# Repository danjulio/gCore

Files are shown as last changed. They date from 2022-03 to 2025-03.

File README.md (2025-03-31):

## gCore - gadget Core

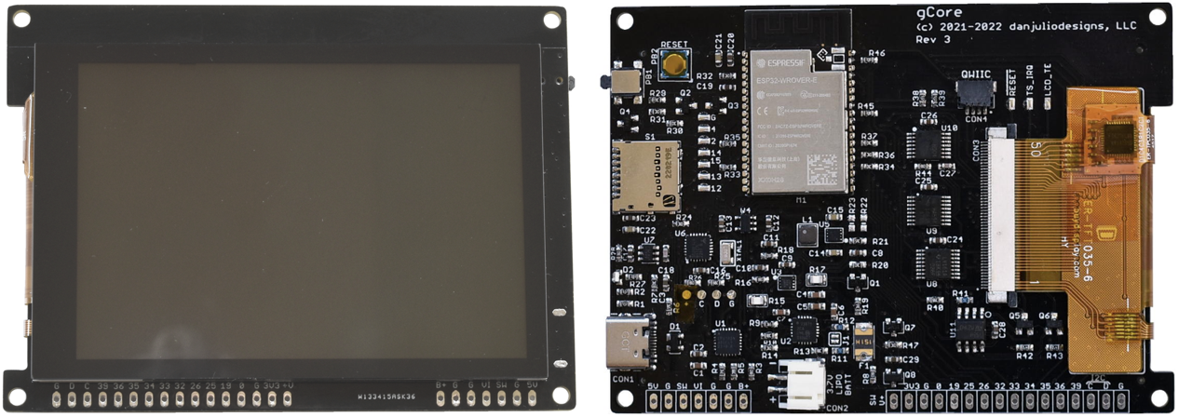
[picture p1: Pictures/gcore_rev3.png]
gCore Top

 
This repository contains documentation and example code for an ESP32-based development board I designed to enable building portable GUI-based gadgets (*).  It provides a rich feature set and high performance operation enabling, I hope, all kinds of cool and useful devices such as remote controls, instrument controllers and game platforms.  Code may be written using the ESP32 Arduino environment, Espressif's IDF or MicroPython.  Both Adafruit-compatible and [LVGL](https://lvgl.io) LCD drivers are available.

gCore can be purchased from [tindie](https://www.tindie.com/products/globoy/gcore-high-end-esp32-graphics-dev-board/).

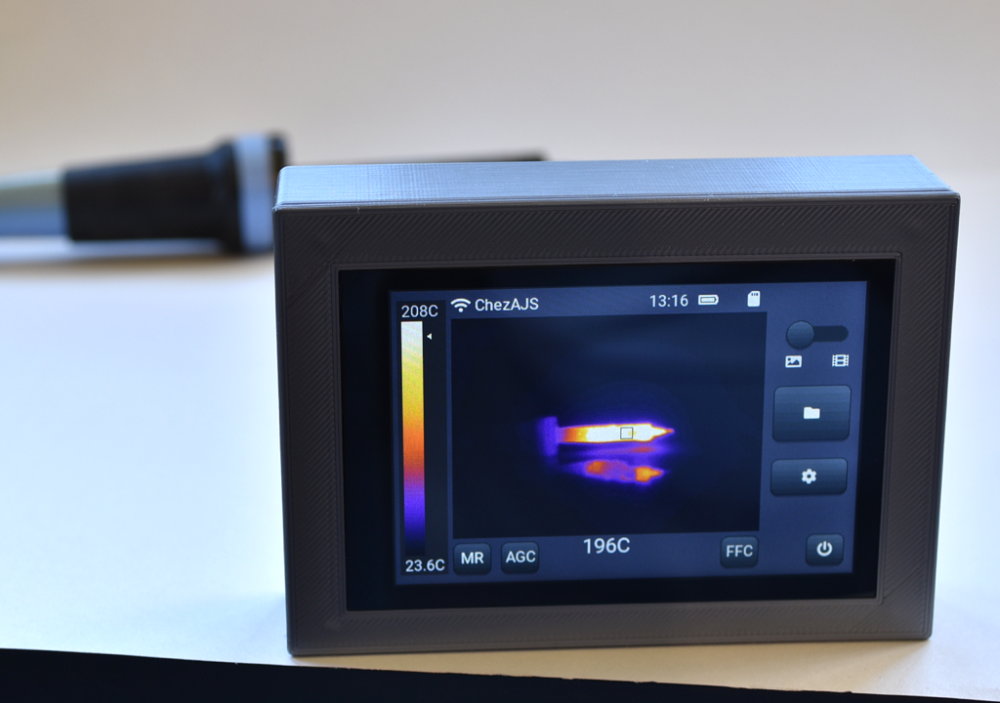
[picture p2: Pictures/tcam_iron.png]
gCore based tCam

(tCam thermal imaging camera)

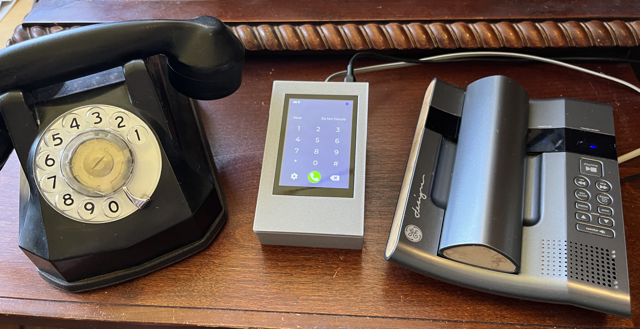
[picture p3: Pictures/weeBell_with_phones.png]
gCore based POTS to bluetooth

(POTS telephone to bluetooth adapter)

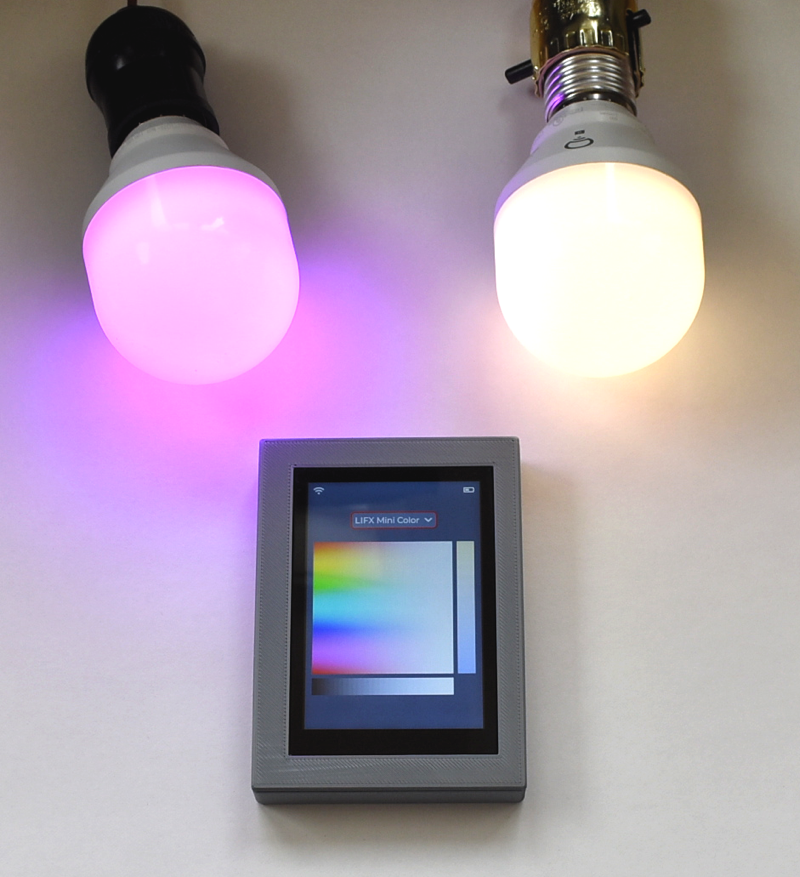
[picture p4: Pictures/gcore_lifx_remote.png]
gCore Controlling LIFX bulbs

(Controlling LIFX LED light bulbs via Wifi)

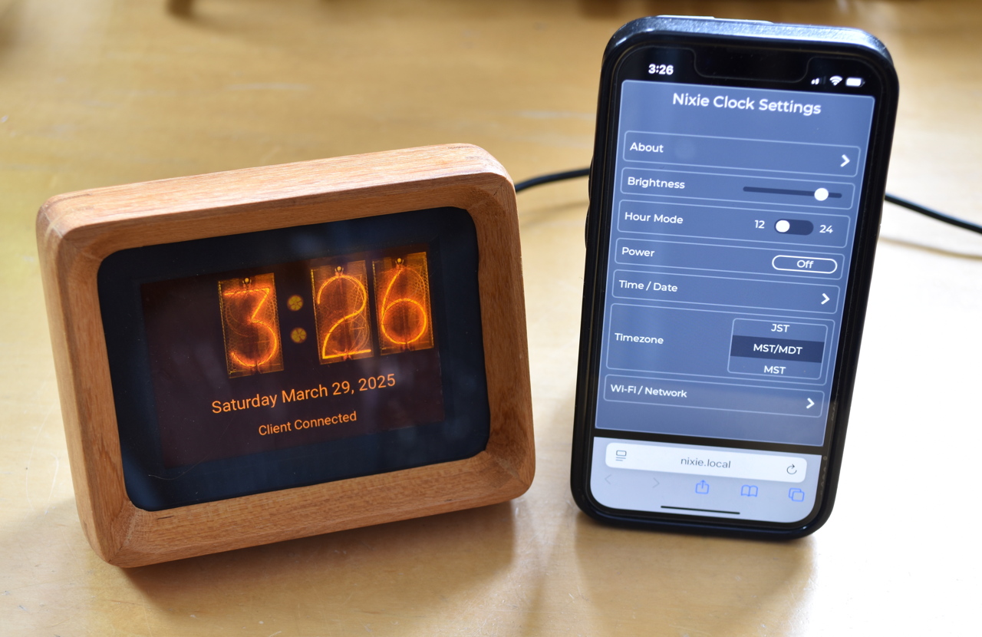
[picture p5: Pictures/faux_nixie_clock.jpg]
gCore Faux Nixie Clock

("Nixie" Desk clock)

### Supporting documentation and code
This repository contains documentation, firmware, an Arduino library with example code, and designs for 3D printed enclosures.

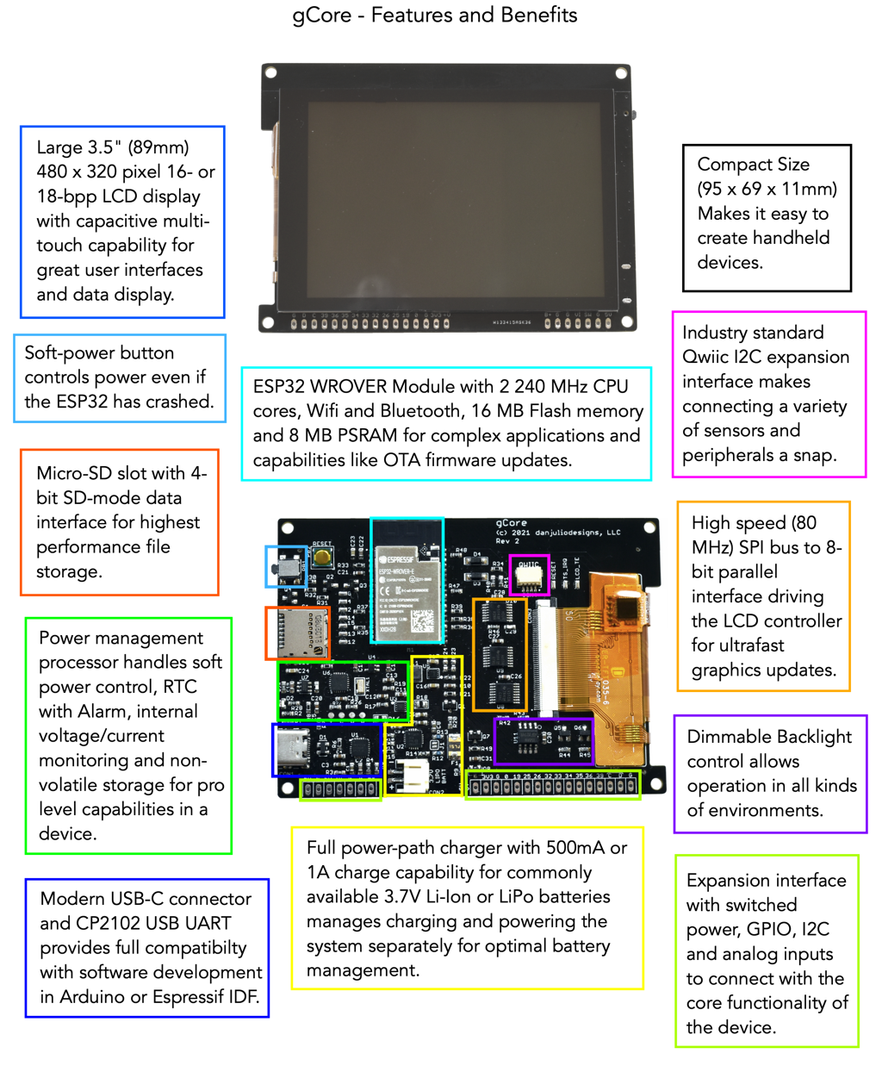
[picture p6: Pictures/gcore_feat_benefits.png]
gCore Features and Benefits


### Support in other Github repositories
Additional demos and ports of other software to gCore are stored in the following additional repositories to reduce the size of this repository.

1. [TFT_eSPI](https://github.com/danjulio/TFT_eSPI) - A fork of Bodmer's LCD driver library ported to gCore to maximize LCD drawing performance for Arduino programs.  Very fast.
2. [tCam](https://github.com/danjulio/tCam) - Assembly instructions and firmware for the tCam thermal imaging camera.
3. [MicroPython](https://github.com/danjulio/lv_binding_micropython) - LVGL binding for MicroPython.
4. [gcore_life](https://github.com/danjulio/gcore_life) - Life running on gCore using LVGL.  Shows how to integrate control for gCore into an ESP32 IDF program.
5. [gcore\_lv\_port_esp32](https://github.com/danjulio/gcore_lv_port_esp32) - The LVGL v7 demo with gCore optimized LCD and touch drivers useful for for ESP32 IDF programs.
6. [gcore_tank](https://github.com/danjulio/gcore_tank) - An easy-to-build remote controlled vehicle with video feed using gCore and the remote control.
7. [gcore\_lv\_music_demo](https://github.com/danjulio/gcore_lvgl_music_player) - The LVGL Music Demo running on LVGL v9.
8. [Galaga](https://github.com/danjulio/gcore_galagino) - A port of Harbaum's Galaga emulator on gCore.
9. [MiniWebRadio](https://github.com/danjulio/ESP32-MiniWebRadio) - A port of schreifbfaul1's internet radio/clock program to gCore.
10. [weeBell](https://github.com/danjulio/weeBell_bluetooth) - A bluetooth to POTS phone adapter running on a gCore [expansion board](https://github.com/danjulio/weeBell_hardware).
11. [Faux Nixie Clock](https://github.com/danjulio/faux_nixie_clock) - Desk clock with web browser control panel.

I wrote a desktop app that encapsulates a compiled version of esptool and can download pre-compiled binaries for most of the demos from my [website](https://danjuliodesigns.com/products/gcore.html) and load them into gCore without needing Arduino or the Espressif IDF.

1. [Linux download](https://danjuliodesigns.com/resources/AppSupport/gcore/gsc_0_2_0_Linux_x86_64.zip) - 64-bit x86 architecture version
2. [Mac OS download](https://danjuliodesigns.com/resources/AppSupport/gcore/gsc_0_2_0_macOS.zip) - 64-bit universal (sadly unsigned so you'll have to authorize it)
3. [Windows download](https://danjuliodesigns.com/resources/AppSupport/gcore/gsc_0_2_0_Windows64.zip) - 64-bit x86 architecture version

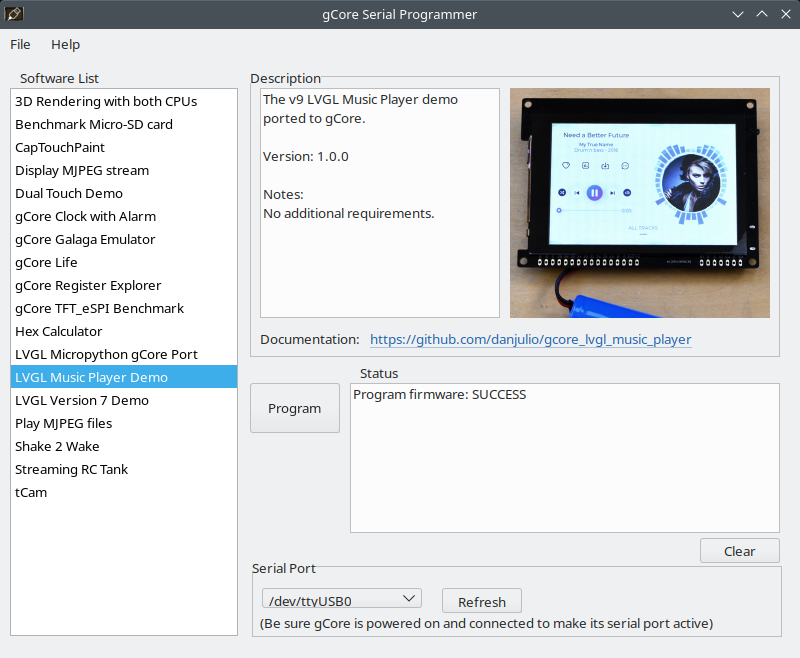
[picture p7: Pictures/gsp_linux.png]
gCore Serial Programmer


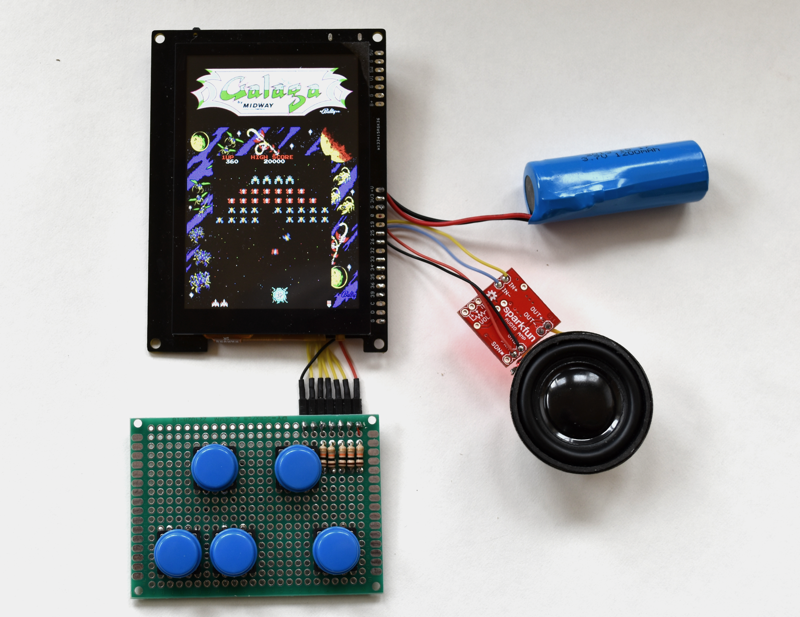
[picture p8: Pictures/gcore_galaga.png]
Galaga on gCore


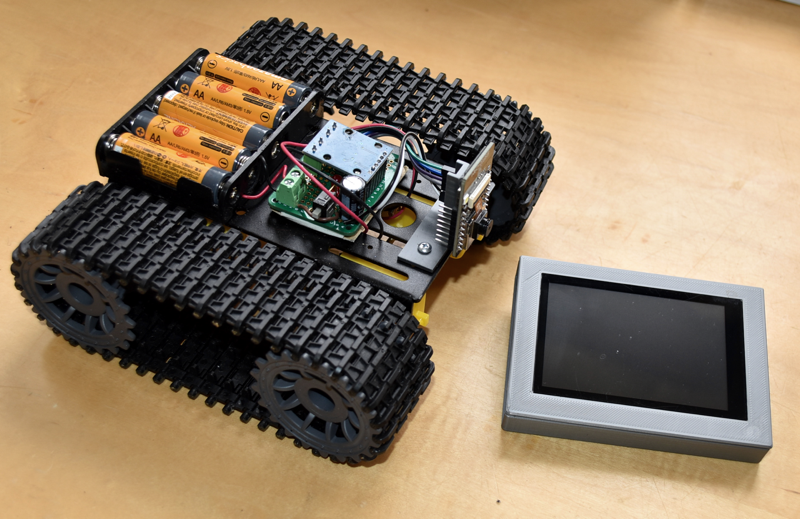
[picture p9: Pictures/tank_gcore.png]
Remote Controlled Tank


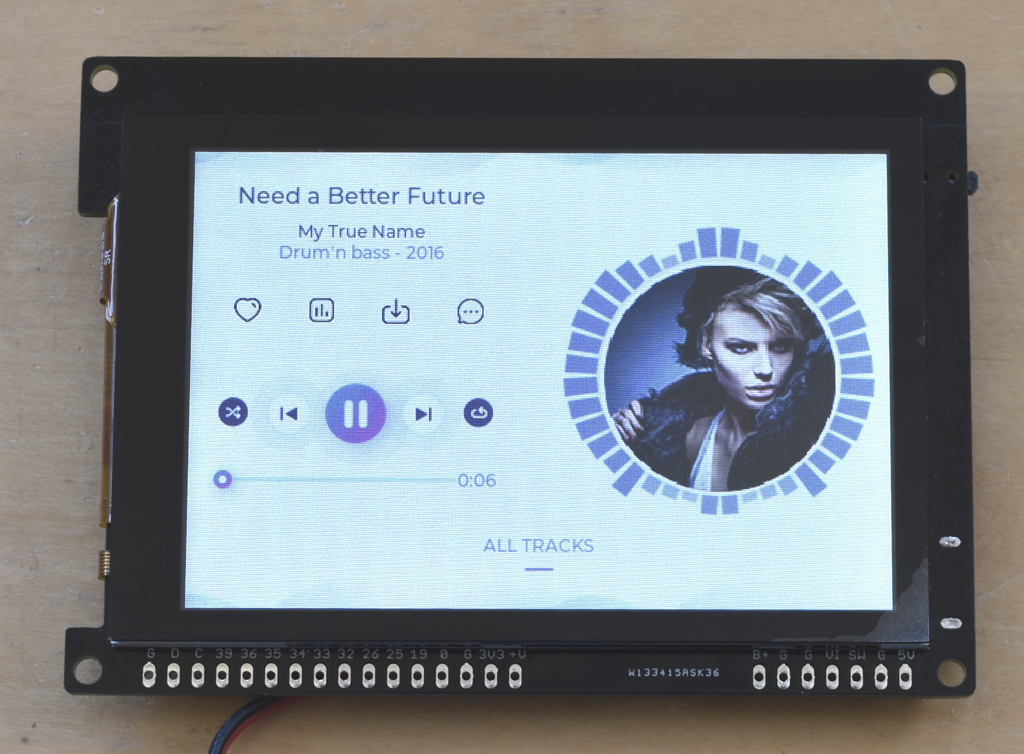
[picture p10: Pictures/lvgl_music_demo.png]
LVGL Music Demo


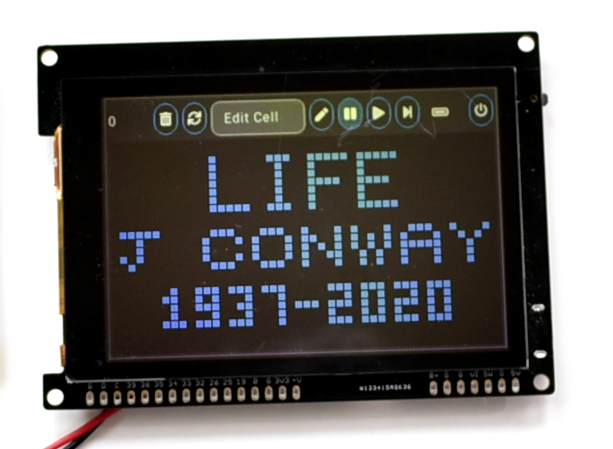
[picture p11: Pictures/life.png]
Life!


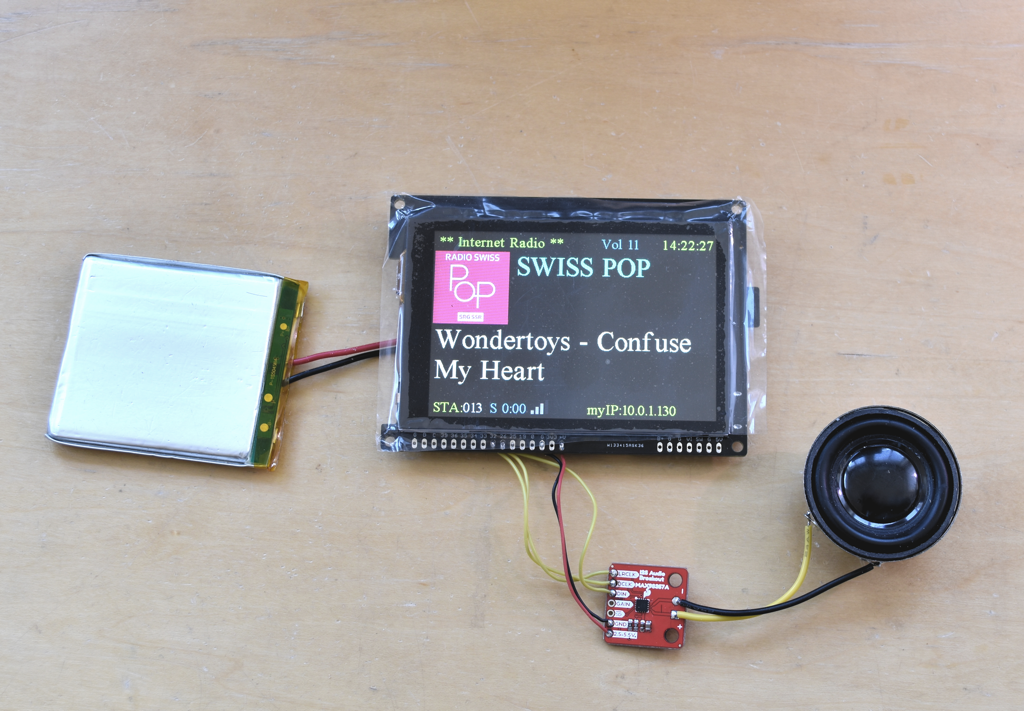
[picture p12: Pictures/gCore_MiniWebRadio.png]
MiniWebRadio


### (*) Historical Note
This is actually my second design.  The original gCore design was based around a "feather" PCB designed to fit under an Adafruit LCD module.  It is documented in the [Original gCore](https://github.com/danjulio/gCore-featherwing) repository.

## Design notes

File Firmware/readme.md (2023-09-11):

## gCore EFM8 Firmware
This directory contains the source code and compiled hex for the EFM8 RTC/PMIC co-processor on gCore.  It was created using Silicon Labs Simplicity Studio v4.

### Sept 2023 - Version 1.2
Version 1.2 fixes two bugs with the Real Time Clock (RTC) in the originally shipped version 1.1 firmware.

1. The once/second RTC interrupt is controlled by a timer.  The timer preset was incorrectly set and led to a time keeping error of -0.0061% (the RTC was slightly slow).
2. The once/second RTC interrupt could be missed on occasion with heavy I2C access to the EFM8 (for example polling the EFM8 several times per second to see if the power button has been pressed).  This could lead to a far more severe time keeping error of up to tens of seconds per day depending on the I2C access frequency.

There are no other known issues with version 1.1 firmware (e.g. there is no problem if you don't use the RTC or can live with the bugs).  Boards are currently shipping with version 1.2 firmware.

### Upgrading Version 1.1 gCore boards
For customers with gCore boards containing version 1.1 firmware and experiencing issues with the RTC there are three ways to get the new firmware loaded on your board.

1. Email me to arrange return and reprogramming.  You will pay the shipping to me and I will pay the return shipping.
2. Install Silicon Labs Simplicity Studio if you have a Silicon Labs USB Debug Adapter and use the programming tool to program the hex from this repository.  The tool can be run from within Simplicity Studio but you need to configure it for an EFM8SB20F32G micro-controller.
3. Update the firmware yourself with the instructions below and a 32-bit Arduino board.

You can tell what firmware you are using by running the ```gcore_reg_explorer``` demo Arduino sketch in the ```Arduino/gCore/examples``` folder in this repository.  You will see a line of text identifying the version on the gCore display.

```
	ID: 0x01  Version: 1.1
```

#### Local Firmware Update
The ```gcore_efm8_upd_1_2``` folder contains an Arduino sketch that contains the new firmware and code capable of programming the gCore EFM8 through a Silicon Labs C2 interface exposed via test points on gCore.  The sketch is designed to run on a 3.3V 32-bit Arduino development board and has been tested on the following boards.

1. PJRC Teensy 3.2 using Teensyduino 1.56
2. PJRC Teensy 4 using Teensyduino 1.56
3. Sparkfun ESP32 Thing Plus using Espressif ESP32 for Arduino version 2.0.9
4. Espressif ESP32-S3-DevKitC-1 using Espressif ESP32 for Arduino version 2.0.9
5. Waveshare RP2040 Zero using Earle Philhower’s Raspberry Pi Pico/RP2040 version 3.4.1

The C2 interface has some timing restrictions and various Arduino implementations have wildly different GPIO performance so unfortunately I cannot guarantee operation on any other board (although different Teensy 3/4, ESP32 and RP2040 boards will probably work).

Three wires connect the Arduino to gCore and programming only takes a few seconds after the sketch is compiled and downloaded to the Arduino board.

You should only attempt this if you understand how to compile Arduino sketches for different boards and can connect wires between the two boards.  Please read through the following instructions before attempting the update.

You will need some connecting wire, ideally three Dupont style wires with male and female ends.

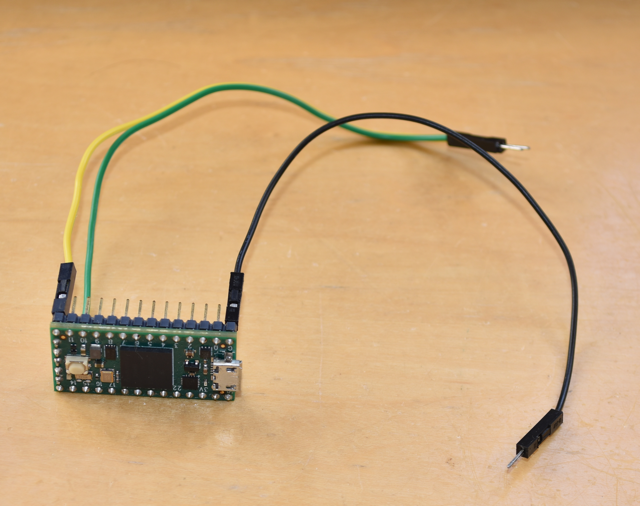
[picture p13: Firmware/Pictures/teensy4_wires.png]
Teensy 4 with wires


You will be connecting to the gCore EFM8 ICSP test points.

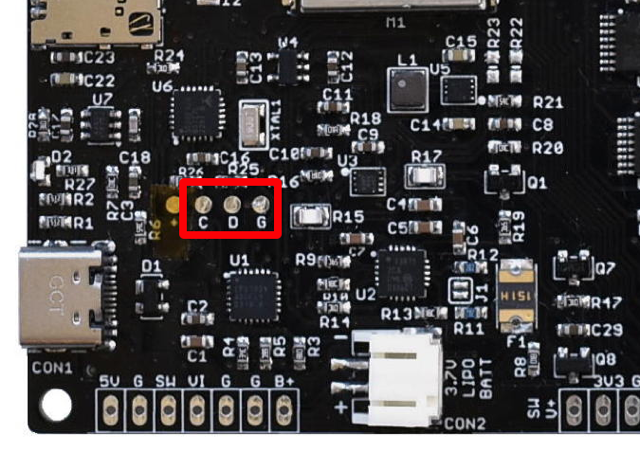
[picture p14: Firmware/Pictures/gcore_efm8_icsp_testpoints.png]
gCore EFM8 ICSP Test Points


#### Compile gcore\_efm8\_upd\_1_2

1. Either update your local copy of this repository or download a zip file of the repository to get the sketch on your computer.
2. Open the Arduino IDE and select your board type.
3. Configure the build environment for your board as discussed below under Board Specific Configuration.
4. Connect your Arduino board and select its serial port.
5. Load the sketch into Arduino. See the note below about selecting GPIO pins on your Arduino.
6. Compile and download the sketch.
7. Open the Arduino Serial Monitor and set it to 115200 baud.  Type the character 'H' in the Serial Monitor and hit send.  You should see the following message displayed in the Serial Monitor.

```
	gCore EFM8 version 1.2 firmware updater sketch
```

##### Board specific configuration

Teensy board have the following setup.  Important to get the right optimization level.

| Board | Setup |
| --- | --- |
| Teensy 3.2 | Optimization: "Faster", CPU Speed: 96 MHz |
| Teensy 4 | Optimization: "Faster", CPU Speed: 600 MHz |
| ESP32 | Flash Frequency: 80 MHz |
| ESP32-S3 | Flash Mode must match your module type (for example use OPI 80 MHz if you have an 8-bit Flash memory) |
| RP2040 | Optimization: "Optimize Even More (-O3)", CPU Speed: 133 MHz |

##### Selecting GPIO pins
By default the sketch uses the following two GPIO pins for the C2 interface.

1. GPIO 12 for the C2 Data (connects to the 'D' pad on gCore)
2. GPIO 14 for the C2 Clock (connects to the 'C' pad on gCore)

You can change these pins if necessary in the sketch under the Pin Definition section in the first tab to match ones available on your board.  Make sure the pins are capable of digital IO.  They should be 3.3V logic levels.

You also need to connect a common ground reference between the Arduino and gCore.

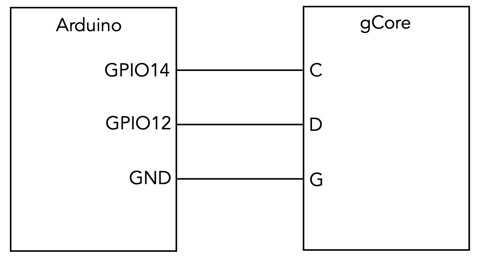
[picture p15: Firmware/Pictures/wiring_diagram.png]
Wiring Diagram


#### Connect the Arduino to gCore
The method described here requires no soldering but does require a steady hand (don't worry I did it a lot while testing this update method).  It also assumes your Arduino board has headers for the Dupont wires or they are soldered to it.

1. gCore should be powered by a connected battery or a USB-C cable but turned off (the EFM8 is always powered when gCore has power).
2. Plug the three Dupont cable female ends onto your Arduino board.  One wire should plug into a Ground (GND) pin and the other two wires into the two GPIO pins implementing the C2 interface.
3. Place the Arduino and gCore next to each other.  Hold the three male ends together in the order 'C' - 'D' - GND and press them onto the gCore EFM8 ICSP pads as shown in the pictures below.  Make sure they are contacting the pads.  They should poke through any oxide layer but you might clean the pads with Isopropyl alcohol on a Q-tip prior to updating.

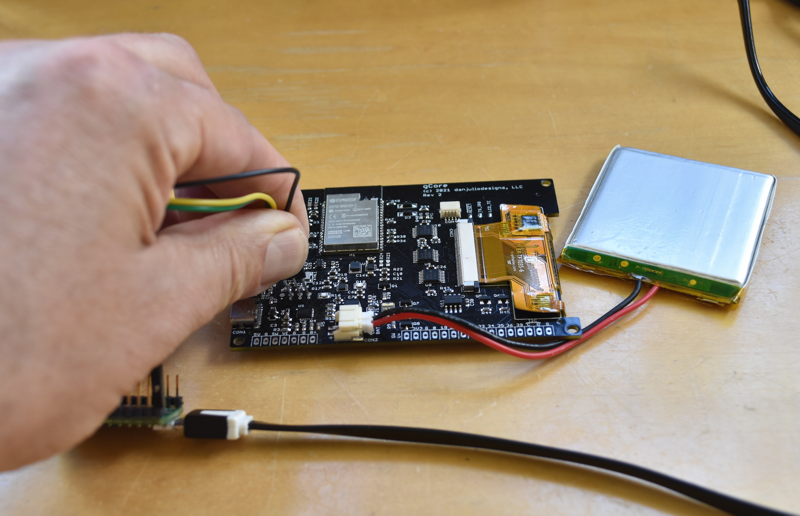
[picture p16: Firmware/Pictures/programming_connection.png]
Programming setup


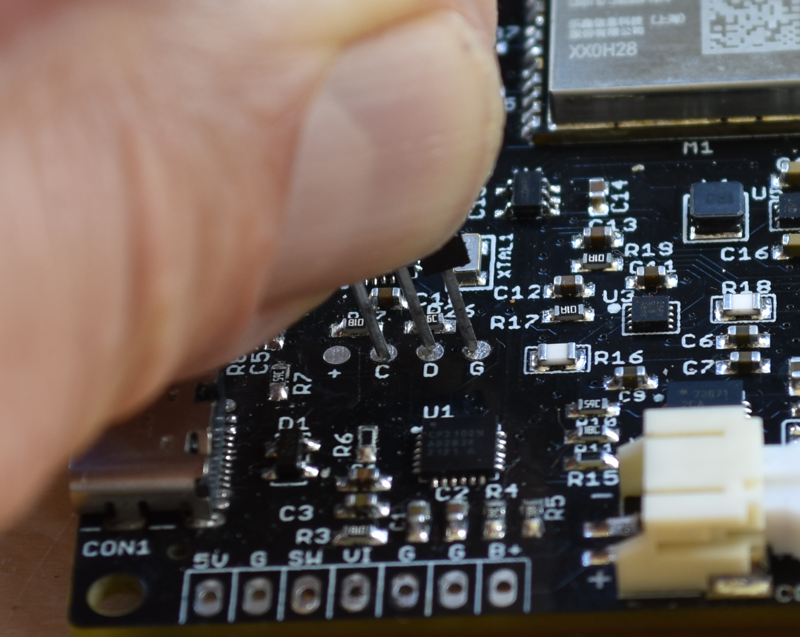
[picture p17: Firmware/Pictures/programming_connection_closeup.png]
Programming setup close-up view


#### Update
While holding the male ends against gCore's test points, type the character 'P' in the Arduino Serial Monitor and hit Send to start programming (it might be easier to type the P in first so you only have to click Send).  You should see the update process start.  It will complete in just a few seconds.

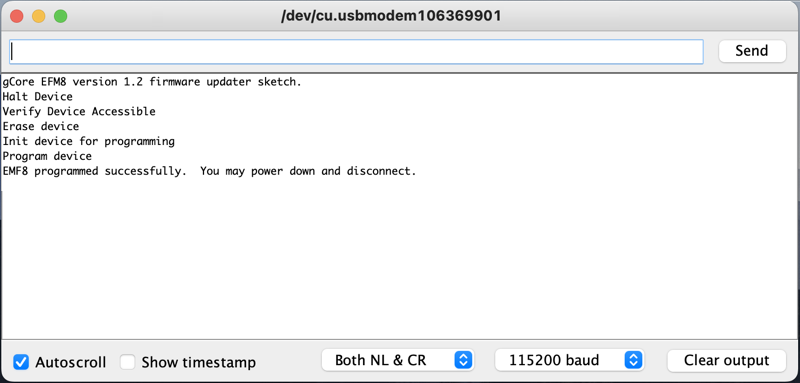
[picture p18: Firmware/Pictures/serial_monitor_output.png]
Serial Monitor Output


You can then disconnect the wires from gCore.  It will be running the new firmware.

#### Errors
The sketch will display an error message if any part of the programming sequence fails.  Most likely this is because of a poor connection or lack of power.  It's also possible if there's some issue with the GPIO performance on your Arduino board.  Although the EFM8 may be erased there should be no way to brick it so don't be afraid to try again.  In the worst case you can arrange re-programming with me.

#### Soldering
It's also possible to solder the Arduino wires to gCore as shown in the following image.  Use a fine wire (I love 30 AWG silicon sleeve wire) and small amounts of solder.  Be sure both the Arduino and gCore are unpowered while soldering and unsoldering.  Take care unsoldering as it is easy to pull the test points off the PCB.

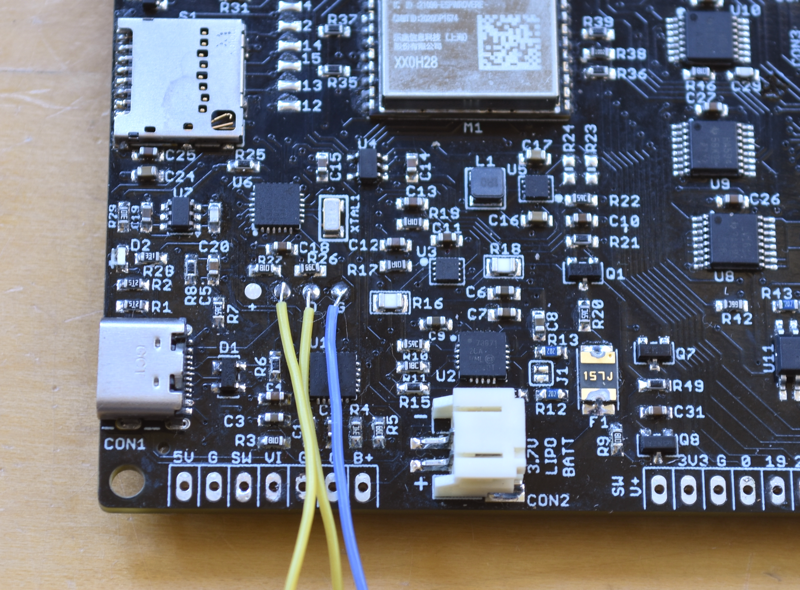
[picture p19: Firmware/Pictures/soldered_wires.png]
Picture of wired assembly


#### Using the Silicon Labs USB Debug Adapter

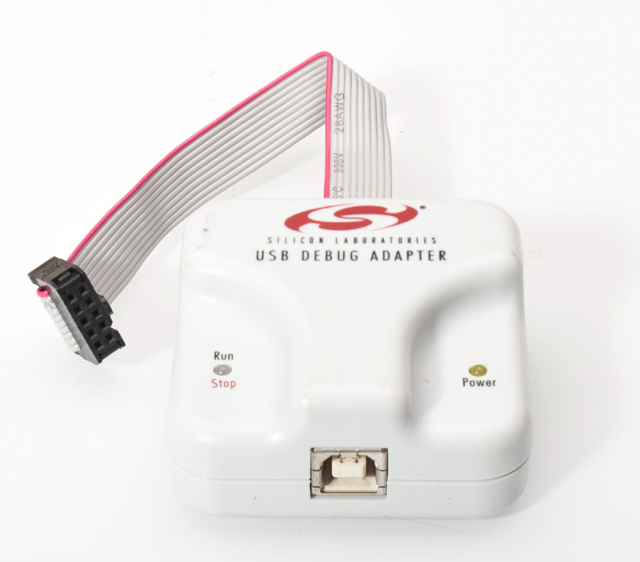
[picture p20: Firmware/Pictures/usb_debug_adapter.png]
Silicon Labs USB Debug Adapter


You will be connecting the same C2 interface pins to gCore: Common ground, clock and data.  In this case use male-male Dupont style wires.

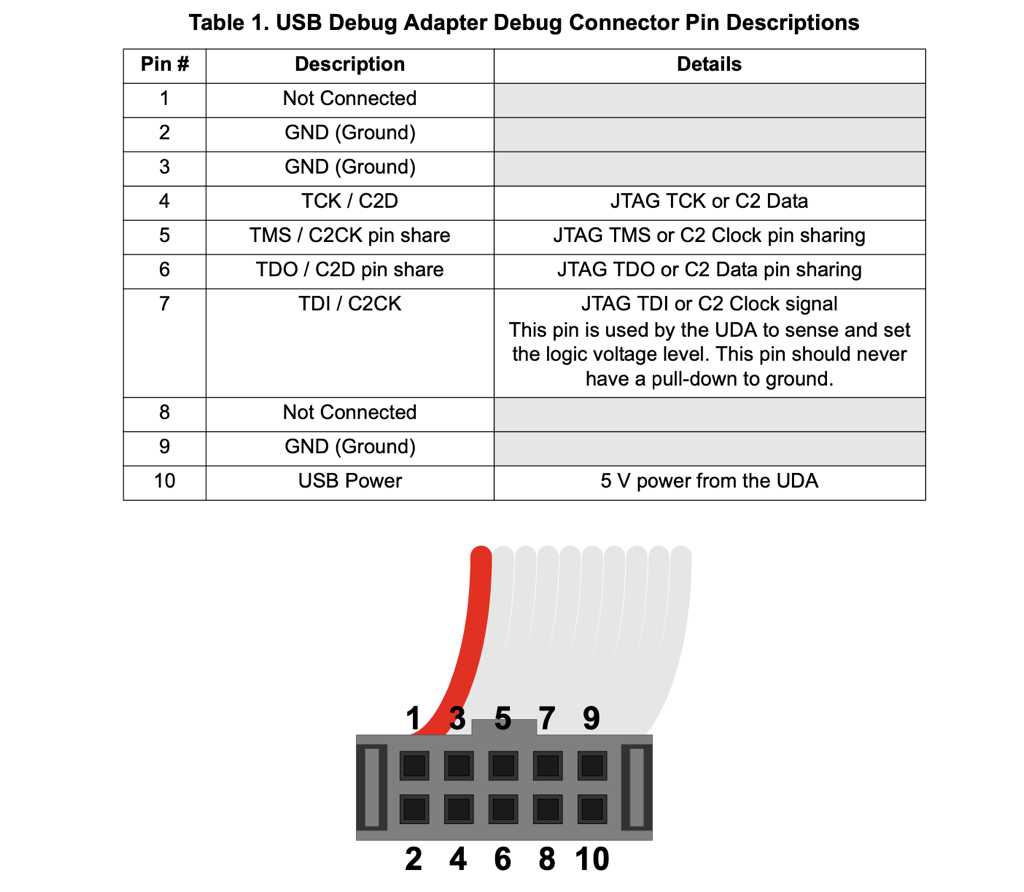
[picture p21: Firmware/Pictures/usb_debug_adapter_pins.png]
USB Debug Adapter Pins


| USB Debug Adapter | gCore |
| --- | --- |
| 9 - GND | G pad on PCB Bottom |
| 4 - TCK / C2D  | D pad on PCB Bottom |
| 7 - TDI / C2CK | C pad on PCB Bottom |

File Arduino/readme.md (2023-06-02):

## gCore Arduino Library

### Arduino Library
Copy the ```gCore``` directory into your Arduino libraries folder.  It contains two libraries.

1. ```gCore``` contains a class that interfaces with the EFM8 co-processor and provides control and time functions.
2. ```gCore_ILI9488``` contains an Adafruit compatible display driver for gCore's ILI9488 LCD controller.  It can be used anywhere an Adafruit driver would be used.  It is not as fast as the TFT\_eSPI library but provides a good example of how to interface with the ILI9488, including setup code.

### Other libraries used by gCore demos
There are other libraries, in addition to the gCore libraries, that have been ported to support gCore or are used by the gCore demos.

1. ```Adafruit_FT6206``` (v1.0.6) - Download using Arduino library manager.
2. ```Adafruit_GFX``` (v1.6.1) - Download using Arduino library manager.
3. ```LIFX``` - Use my version downloaded from [here](https://github.com/danjulio/LIFX).
4. ```lv_arduino``` (v3.0.1) - Download using Arduino library manager (see note below).
5. ```Sparkfun_Qwiic_Joystick_Arduino_Library``` (v1.1.1) - Download using Arduino library manager.
6. ```tgx``` - Use my version found in the ```supporting``` directory here (see note below).
7. ```TJpg_Decoder``` (see note below for version) - Download using the Arduino library manager or found [here](https://github.com/Bodmer/TJpg_Decoder).
8. ```TFT_eSPI``` - Use my version downloaded from [here](https://github.com/danjulio/LIFX) (see note below).

### Library notes

#### Arduino Library Manager
To open the Arduino Library Manager, select ```Sketch->Include Library->Manage Libaries...```.

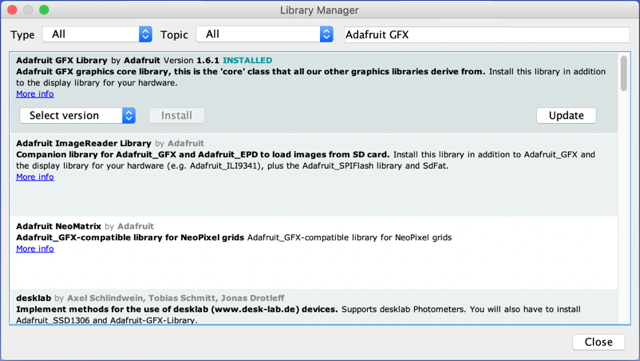
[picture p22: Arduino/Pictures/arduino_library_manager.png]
Arduino Library Manager


#### LIFX Port
I extended [Peter Hum's](https://github.com/peter-hum/LIFX) excellent ```LIFX``` library to support color capable bulbs as well as to be able to query the bulb and identify it and its capabilities.  The additional functionality is used by the ```lifx_controller``` demo.  Peter's original code won't work with the demo.

#### lv_arduino
The ```lv_arduino``` (LVGL for Arduino) library can be downloaded using the Arduino library manager.  I used v3.0.1 for these demos.  In case a new version breaks these demos, you should be able to download v3.0.1 from [here](https://github.com/lvgl/lv_arduino/releases/tag/3.0.1).

LVGL is configured for a particular project using a ```lv_conf.h``` file located at the top of the library directory.  Among many other things it tells LVGL the display resolution and enables various sizes of the built-in fonts.  The following preconfigured files are included in the ```supporting``` subdirectory here for use with the gCore demos.  The associated file should be copied to the LVGL Arduino library directory and renamed ```lv_conf.h```.

1. ```lv_conf_landscape.h``` is used with ```hex_calculator```.
2. ```lv_conf_portrait.h``` is used with ```lifx_controller```.

#### tgx
Because it appears that Arvind Singh is continuing to evolve his amazing 3D [tgx](https://github.com/vindar/tgx) library, I have included the copy of that library I used for the ```joystick_3d``` demo in case the API changes.  This can be found in the ```supporting ``` subdirectory here.  This library may need modification to compile with any of the 2.X ESP32 Arduino board packages.

#### TJpg_Decoder
Install version 0.0.3 of ```TJpg_Decoder``` if you have ESP32 Arduino version 1.X installed.  Install version 1.0.2 if you have ESP32 Arduino version 2.X installed.  This is because Bodmer made changes to the TJpg\_Decoder library that make version 1.0.2 incompatible with version 1.X ESP32 board support packages (see the explanation [here](https://github.com/Bodmer/TJpg_Decoder/issues/30)).

#### TFT_eSPI Port
[Bodmer's](https://github.com/Bodmer/TFT_eSPI) fantastic Adafruit-compatible TFT\_eSPI library is incredibly fast and even though I wrote my own ILI9488 library I'd advise using it when possible.  However it must be configured for each type of display it will use.  My configuration customizations for the ILI9488 LCD controller, gCore specific GPIO pins and 80 MHz SPI operation are found in my [fork](https://github.com/danjulio/TFT_eSPI).  Download and install it as an Arduino library.  You may have to temporarily move aside any other version of TFT_eSPI you have when you compile for gCore.

### Demo Programs
Demo programs show off various aspects of gCore.  They require additonal libraries listed with each demo description.  The Arduino environment needs to have the ESP32 addition installed using the Board Manager and configured for the Wrover Module as shown below.

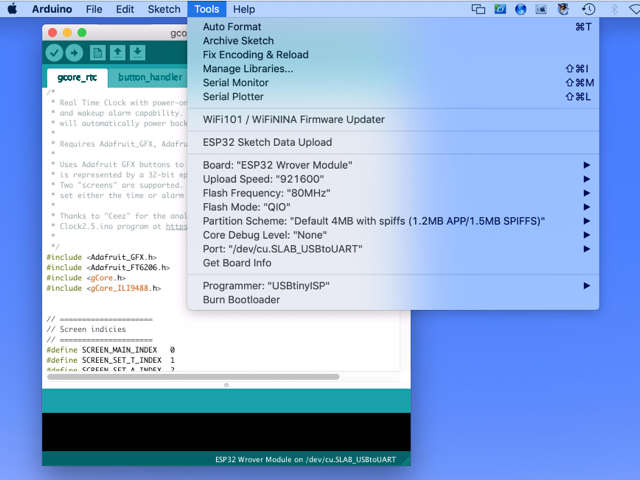
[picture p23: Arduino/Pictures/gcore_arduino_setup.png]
gCore Arduino setup


#### CapTouchPaint
A port of the Adafruit CapTouchPaint program.  Uses the following libraries.

1. gCore
2. gCore_ILI9488
3. Adafruit_GFX
4. Adafruit_FT6206

#### disp\_mjpg_stream
Displays a mjpeg video stream from an ESP32 CAM running the ```esp32-cam-webserver``` sketch found in the ```supporting``` directory.  The ESP32 CAM board acts as a WiFi access point and gCore connects to the camera, initiates a raw stream and uses both CPUs to receive the stream, parse it into individual jpeg images, and then decode and display them.

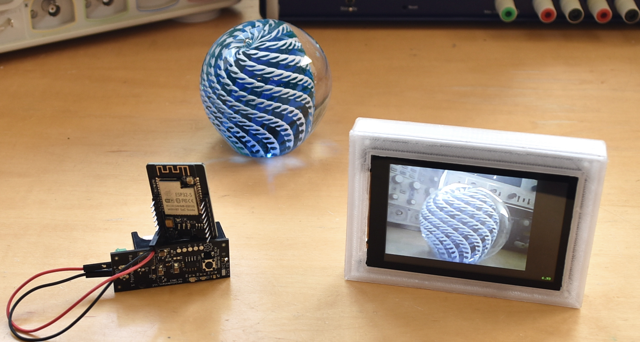
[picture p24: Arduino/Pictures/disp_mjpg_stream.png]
Display streaming mjpeg demo


Uses the following libraries.

1. gCore
2. TFT_eSPI for gCore
3. TJpg_Decoder

The pre-configured ```esp32-cam-webserver``` sketch in ```supporting``` is based on Owen Carter's modified ESP32 cam program ([link](https://github.com/easytarget/esp32-cam-webserver)).  By default it is configured to run on an [AI Thinker](http://www.ai-thinker.com/pro_view-24.html) or compatible board but supports most of the standard ESP32 camera boards.  Instructions for programming the board may be found in the ```README.md``` file in the sketch's main folder.

The camera is configured for CIF resolution (400 x 296 pixels) but the ```disp_mjpg_stream``` sketch should handle any resolution up to 480 x 320 pixels.  By modifying it to point to another mjpeg stream it should be able to work with other streaming sources.  Frame rate is primarily limited by the jpeg decode process and scene complexity.  I saw the following typical performance.

| Resolution | Frame Rate (Frames/Sec) |
| --- | --- |
| CIF 400x296 | ~7 FPS |
| QVGA 320x240 | ~10.5 FPS |
| QQVGA 160x120 | ~23 FPS |

#### dual_touch
A simple demo showing how to use the dual touch detection capability of the FT6236 touchscreen controller.  Displays a circle around each of one or two touch points.  Note that the FT6236 seems to have a bug where, when two touch points are vertically aligned, it reports one touch with a position somewhere between them.

Uses the following libraries.

1. gCore
2. gCore_ILI9488
3. Adafruit_GFX

#### eTFT_graphicstest
A port of the Adafruit ```graphicstest``` benchmark program using the TFT\_eSPI library.  Blazing fast.  Uses the following libraries.

1. Adafruit_GFX
2. TFT_eSPI for gCore

Results should look like the following (open the serial monitor at 115200 baud).

```
Benchmark                Time (microseconds)
Screen fill              159072
Text                     9702
Lines                    100609
Horiz/Vert Lines         14424
Rectangles (outline)     8061
Rectangles (filled)      387786
Circles (filled)         58732
Circles (outline)        38298
Triangles (outline)      21696
Triangles (filled)       137064
Rounded rects (outline)  18267
Rounded rects (filled)   392288
```

#### gcore\_reg_explorer
A demo program that displays the EFM8 registers, dynamically updated, and provides a command line interface through the serial monitor allowing access to the registers and NVRAM.  Designed to allow easy modification of register values to explore how the EFM8 co-processor works (see the ```Documentation``` directory for address offsets and a description of the registers).  Demonstrates how to use the ```gCore``` library to access the EFM8.

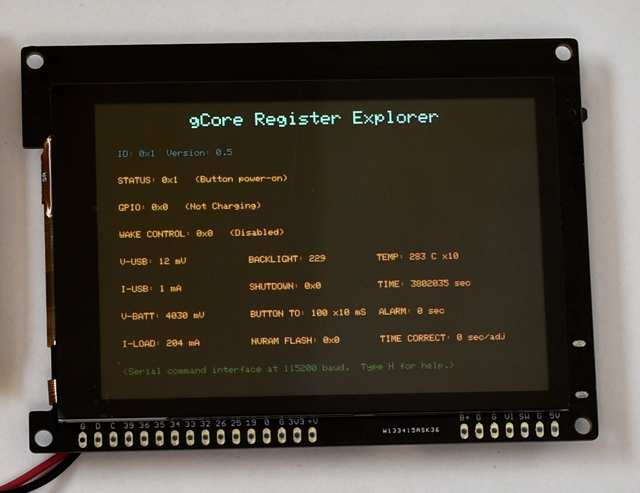
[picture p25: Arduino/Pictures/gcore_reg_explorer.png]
gCore Register Explorer Demo


Configure the Arduino Serial Monitor for 115200 baud operation.  Type 'H' followed by Send to display a help menu.

Uses the following libraries.

1. gCore
2. gCore_ILI9488
3. Adafruit_GFX

#### gcore_rtc
A demo program that displays a clock to demonstrate use of the EFM8's RTC and Alarm functions.  Use a simple touch interface to set the time and an alarm, enable the alarm by pressing ```ALARM```then turn gCore off by pressing the ```OFF``` button.  It will automatically switch back on when the alarm time passes.

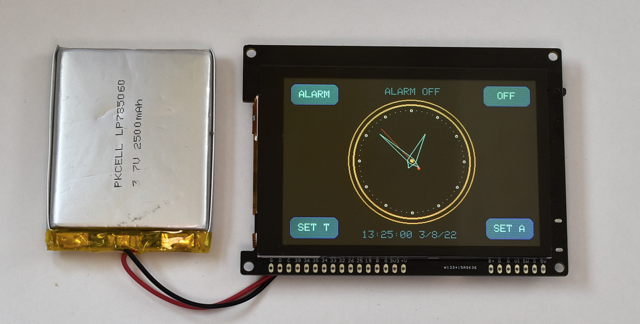
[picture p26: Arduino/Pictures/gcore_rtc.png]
gCore RTC Demo


Uses the following libraries.

1. gCore
2. gCore_ILI9488
3. Adafruit_GFX
4. Adafruit_FT6206

#### graphicstest
The Adafruit ```graphicstest``` benchmark program using the gCore\_ILI9488 LCD driver.  No slouch compared to other ILI9488 driver's I played with but not as fast as TFT_eSPI.  Uses the following libraries.

1. Adafruit_GFX
2. gCore_ILI9488

Results should look like the following.

```
Benchmark                Time (microseconds)
Screen fill              500222
Text                     91095
Lines                    2066654
Horiz/Vert Lines         45573
Rectangles (outline)     29837
Rectangles (filled)      1221137
Circles (filled)         389725
Circles (outline)        883671
Triangles (outline)      388336
Triangles (filled)       567608
Rounded rects (outline)  257851
Rounded rects (filled)   1284509
```

#### hex_calculator
A simple programmer's calculator inspired by the Apple OS X calculator program, but with the features I wanted.  Uses LVGL to create the GUI and makes use of gCore NVRAM to store calculator state and memory between power cycles.  Supports configurable bit lengths from 8 - 64 bits and operates in either decimal or hexadecimal modes.

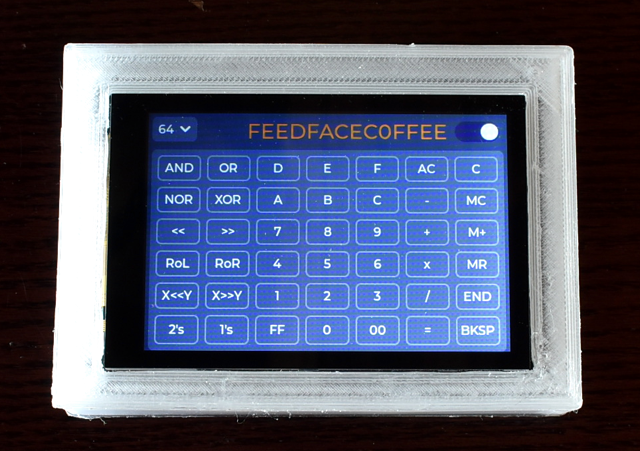
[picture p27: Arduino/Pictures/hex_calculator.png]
Hex Calculator Demo


Be sure to replace the default ```lv_conf.h``` file in the LVGL Arduino library with ```lv_conf_landscape.h``` file in the ```supporting``` directory here.  This configures LVGL to the correct resolution and landscape orientation, and enables the two fonts used by the demo.

Uses the following libraries.

1. gCore
2. lv_arduino
3. TFT_eSPI for gCore

#### joystick_3d
A port of Arvind Singh's Naruto demo using his tgx 3D graphic library.  Spin around a model of the character Naruto Uzumaki displayed as a 3D surface with or without a texture map or shading. Makes use of tasks running on both CPUs to improve performance.  Supports an optional Sparkfun [I2C joystick](https://www.sparkfun.com/products/15168) plugged into the Qwiic interface to manually control the view (pan/zoom/switch shaders).  Be sure to uncomment the line ```#define USE_JOYSTICK``` just below the comments at the top of the sketch to include support for the joystick.  The last ESP32 Arduino package I could compile the tgx library with is 1.0.6.

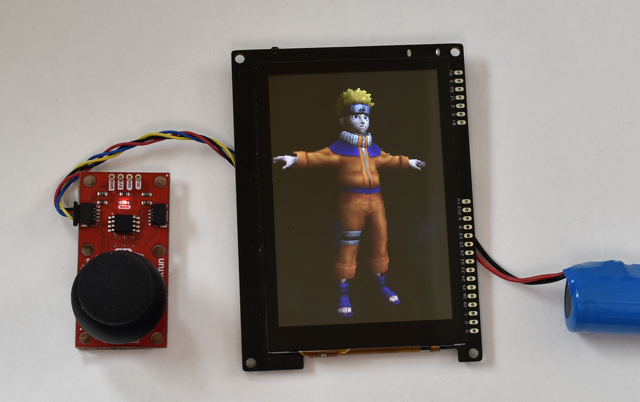
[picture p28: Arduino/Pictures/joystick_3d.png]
joystick_3d Demo


Uses the following libraries.

1. gCore
2. Sparkfun\_Qwiic\_Joystick\_Arduino\_Library (only needed if ```USE_JOYSTICK``` is defined)
3. TFT_eSPI for gCore
4. tgx

#### lifx_controller
A demo remote control application that connects to Wifi and discovers any [LIFX](https://www.lifx.com/) LED light bulbs that have also been configured on that Wifi.  It then uses the [LVGL](https://lvgl.io/) graphics library to display a GUI interface that may be used to control the bulbs.  A drop-down menu lists all discovered bulbs. Selecting a bulb displays an appropriate touch control interface for the bulb.  For example a color-temperature dimmable white bulb will display a brightness and color temperature graphic.  Touching on the graphic controls the bulb.  A color capable bulb displays a color picker, brightness and color temperature graphics.

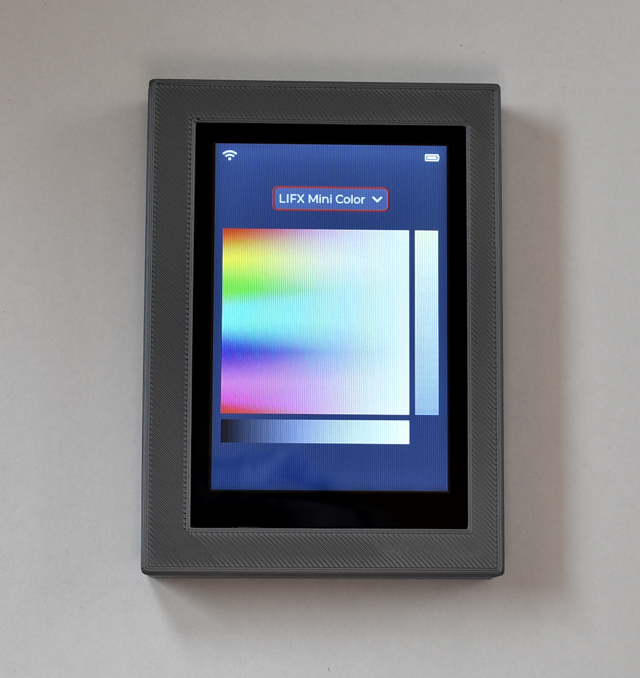
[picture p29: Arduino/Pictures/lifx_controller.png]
LIFX LED Controller


Be sure to set your Wifi credentials in the USER CONFIGURATION section of the ```lifx_controller.ino``` file.  You should have one or more LIFX LED bulbs previously setup on the same Wifi.

Also be sure to replace the default ```lv_conf.h``` file in the LVGL Arduino library with ```lv_conf_portrait.h``` file in the ```supporting``` directory here.  This configures LVGL to the correct resolution and portrait orientation used by the demo.

Uses the following libraries.

1. gCore
2. lv_arduino
3. LIFX
4. TFT_eSPI for gCore

#### play_mjpeg
Plays mjpeg files from the Micro-SD Card.  Uses the serial interface to select a file to play (open the Arduino serial monitor at 115200 baud).  Video file resolution must be 480x320 pixels max.  Large resolution videos might require you to increase the jpeg buffer (MJPEG\_BUF_LEN define) or re-encode the video with lower quality.

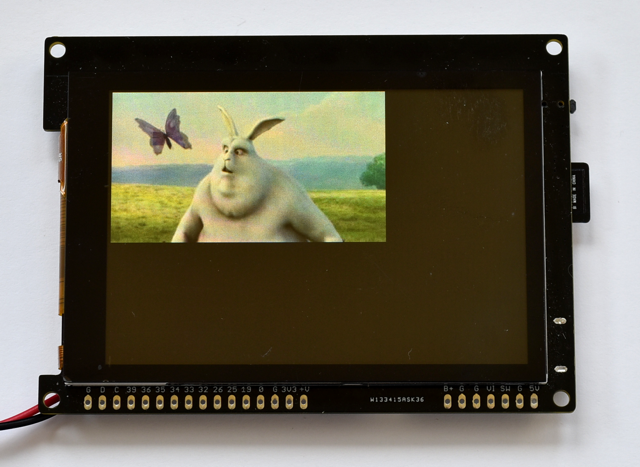
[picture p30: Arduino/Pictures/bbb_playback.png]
Playing Big Buck Bunny


Uses the following libraries.

1. SD, SD_MMC (built-in)
2. TFT_eSPI for gCore
3. TJpg_Decoder

There are two example video files in the ```supporting/mjpeg_files``` directory in this repository.  These should be copied to a Micro-SD card and that card inserted before running the sketch.  The ```bbb10fps.mjp``` file is a transcoded version of the cute [Big Buck Bunny](https://peach.blender.org/) released under the Creative Commons license.  Encoded for 10 FPS, it plays back slightly fast at around 13.5 FPS.  The ```pexels.mjp``` file was transcoded from a video found at [pexels.com](https://www.pexels.com/videos/) originally created by Uzunov Rostislav.  It plays back at around 10 FPS.

When entering a filename to play using the serial monitor, be sure to include the "/" prefix (e.g. ```/bbb10fps.mjp```).

#### sd_benchmark
A port of the [ESP32\_SD_Benchmark](https://github.com/moononournation/ESP32_SD_Benchmark) program to gCore.  This test writes and reads a 4MB file to the Micro-SD Card using different block sizes for each communication method (SPI bus, 1-bit data mode, 4-bit data mode).  I found that I couldn't easily switch between communication methods so the test power-cycles gCore between the tests run with each method using the RTC/Alarm capability and storing the test type in NVRAM.  Output is displayed via serial in the Arduino monitor (115200 baud).  Be sure to open the monitor before downloading and running.  There is nothing displayed on the LCD for this sketch.

Uses the following libraries.

1. gCore
2. SD, SD_MMC, FS (built-in)

Performance will probably vary with the type of card.  Tests with a Sandisk Extreme 32GB (UHS Speed class) are shown below.  The 4-bit mode pays off when writing files.

Write Performance

| Blocksize | HSPI | 1-bit | 4-bit |
| --- | --- | --- | --- |
| 1K | 264 KB/s | 426 KB/s | 439 KB/s |
| 2K | 460 KB/s | 878 KB/s | 937 KB/s |
| 4K | 893 KB/s | 1674 KB/s | 2135 KB/s |
| 8K | 1198 KB/s | 2386 KB/s | 3676 KB/s |
| 16K | 1472 KB/s | 3187 KB/s | 6105 KB/s |
| 32K | 1629 KB/s | 3689 KB/s | 8905 KB/s |
| 64K | 1632 KB/s | 3742 KB/s| 9039 KB/s |

Read Performance

| Blocksize | HSPI | 1-bit | 4-bit |
| --- | --- | --- | --- |
| 1K | 776 KB/s | 907 KB/s | 1049 KB/s |
| 2K | 776 KB/s | 913 KB/s | 1056 KB/s |
| 4K | 774 KB/s | 923 KB/s | 1068 KB/s |
| 8K | 771 KB/s | 921 KB/s | 1068 KB/s |
| 16K | 761 KB/s | 932 KB/s | 1084 KB/s |
| 32K | 749 KB/s | 932 KB/s | 1082 KB/s |
| 64K | 751 KB/s | 932 KB/s| 1083 KB/s |

##### Note about SD Cards and gCore programming

It's possible that a high logic level from a Micro-SD Card on the IO2 pin will cause programming to fail.  Retry after removing and re-inserting the Micro-SD Card if this occurs.

#### shake\_2_wake
An example of how to use a low-power external circuit, powered by gCore's always-on 3.3V power rail, to drive the SW input low turning the system on as the result of some external event.  Simply picking gCore up can switch it on.  Useful for applications such as remote controls.

An ADXL362 ultra low-power accelerometer is configured to drive its INT1 output low upon motion detection.  The INT1 output is connected to the SW input so that motion detection will turn gCore on.  The sketch reconfigures the ADXL362 into normal operating mode and disables driving INT1 so that it can read acceleration data and display it in a repeating graph on the LCD display.  When gCore is turned off by pressing the power button, or after five minutes of operation, the ADXL362 is configured back into motion detection mode capable of driving INT1 again.

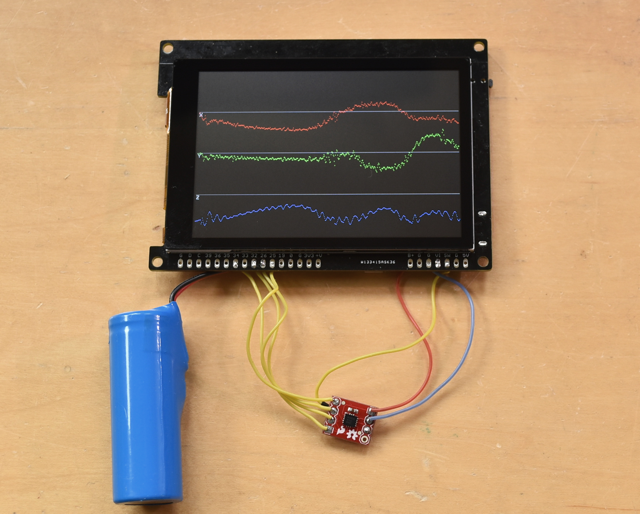
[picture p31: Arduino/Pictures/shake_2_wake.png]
Shake to Wake


This sketch also shows how to configure and use the ESP32 HSPI peripheral for use as a SPI master.  This is necessary because the default VSPI peripheral that is used for the default ESP32 Arduino SPI library is unavailable on gCore (VSPI is used to drive the LCD display).

The ADXL362 is available on a Sparkfun [breakout board](https://www.sparkfun.com/products/11446) and wired to gCore as shown below.  The 1 k-ohm resistor prevents an accidental short condition where the ADXL362 could be driving a logic high on INT1 when the SW input is pulled low as the user presses the power button.

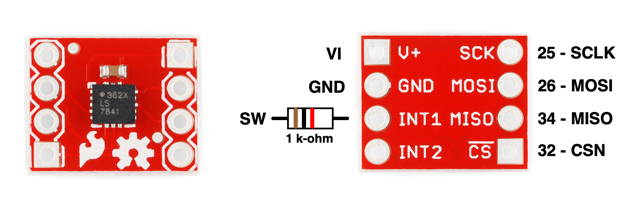
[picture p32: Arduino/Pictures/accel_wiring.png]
Accelerometer Connections

(Board photos courtesy of Sparkfun - [CC BY 2.0](eativecommons.org/licenses/by/2.0/))

The sketch should be able to be be adapted for other accelerometer chips.

#### shake\_2\_wake\_lifx\_controller
A mash-up of ```shake_2_wake``` and ```lifx_controller```.  Just grab the remote and go!

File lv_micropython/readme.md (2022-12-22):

## Micropython + LVGL for gCore
This directory contains documentation and supporting files to build Micropython with LVGL bindings, using the official [lv_micropython](https://github.com/lvgl/lv_micropython) repository, for gCore.  It also contains pre-built binaries (MicroPython v1.19.1 and LVGL v8.3.2).

### ILI9488 Driver
The ```ili9XXX.py``` driver is modified to support gCore.  A new class, ```ili9488g```, is added so that the existing ```ili9488``` class can retain backward compatibility.  The new class has the following modifications.

1. Move default SPI peripheral from HSPI to VSPI.
2. Move default SPI pins to native VSPI pins used on gCore.
3. Change default SPI frequency from 40 MHz to 80 MHz.
4. Add support for 16-bit pixels (RGB565).  The driver automatically works when Micropython is built with either 32- or 16-bit pixels.  The driver is faster when using 16-bit pixels since less data is transferred and the driver doesn't have to copy data for each update (see ```espidf.c```).

Note: As of Dec 20, 2022, this driver has been incorporated in the official lv_micropython project.

### FT6x36 Driver
The existing ```ft6x36.py``` may be used for the touchscreen but needs to be included in the build since it is currently not included by default.  In addition it needs to be specially instantiated to configure it to the necessary 100 kHz I2C clock frequency (since gCore's EFM8 co-processor can't support 400 kHz I2C due to a bug).  See below for instructions to both include it in the build and instance it.

### Building lv_micropython for gCore

#### Modify the repository
First create a local copy of the ```lv_micropython``` repository.  Best to check the current instructions in the repository readme file but basically:

```
git clone https://github.com/lvgl/lv_micropython.git
cd lv_micropython
git submodule update --init --recursive lib/lv_bindings
```

Then replace the ```lib/lv_bindings/driver/esp32/ili9XXX.py``` driver with the ```drivers/ili9XXX.py``` file here.  Make sure the symbolic link in ```ports/esp32/modules/ili9XXX.py``` still points to the updated file.

Finally create a symbolic link from the ```lib/lv_bindings/generic/esp32/ft6x36.py``` file to ```ports/esp32/modules/ft6x36.py``` so that the touchscreen driver will be included in the build.

```
ln -s lib/lv_bindings/generic/esp32/ft6x36.py ports/esp32/modules/ft6x36.py
```

#### Build and load Micropython
First build ```mpy-cross```

```
make -C mpy-cross
```

Then build and download Micropython to gCore.  You can build it with LVGL configured to use either 16-bit RGB565 pixels or 32-bit RGBA8888 pixels (displayed as RGB666 by the ILI9488).

To build 16-bit LVGL:

```
make -C ports/esp32 LV_CFLAGS="-DLV_COLOR_DEPTH=16 -DLV_COLOR_16_SWAP=1" BOARD=GENERIC_SPIRAM PORT=[SERIAL_PORT] deploy
```

To build 32-bit LVGL:

```
make -C ports/esp32 LV_CFLAGS="-DLV_COLOR_DEPTH=32" BOARD=GENERIC_SPIRAM PORT=[SERIAL_PORT] deploy
```

Be sure gCore is turned on before deploying so its serial port will enumerate on your computer to find [SERIAL_PORT].

Connect to gCore after programming using a serial terminal program set to 115200 baud to get the Micropython REPL prompt.  For example using ```screen``` on Linux or Mac OS X.

```
screen [SERIAL_PORT] 115200
```

#### Clean up build
You must clean up the build if you change the python driver before rebuilding.

```
make -C ports/esp32 BOARD=GENERIC_SPIRAM clean
```

### Using the precompiled binaries
There are pre-compiled binaries for 16-bit pixels (```micropython16.bin```) and 32-bit pixels (```micropython32.bin```) in the ```precompiled``` directory here.  They are loaded along with the ```bootloader.bin``` and ```partition-table.bin``` files at the following locations in ESP32 flash memory.

| Location | File |
| --- | --- |
| 0x1000 | bootloader.bin |
| 0x8000 | partition-table.bin |
| 0x10000 | micropython16.bin or micropython32.bin |

If you have the Espressif IDF loaded you can use its tools to download the binaries.  Assuming all three files are in the current directory and you have sourced the ```esp-idf/export.sh``` file.

```
esptool.py esp32 -p [SERIAL_PORT] -b 460800 --before=default_reset --after=hard_reset write_flash --flash_mode dio --flash_freq 40m --flash_size 4MB 0x1000 bootloader.bin 0x10000 micropython16.bin 0x8000 partition-table.bin
```

You can also use the Espressif Windows based download utility to program gCore with the files.

### Super simple LVGL demo
The following code may be entered at the REPL prompt to verify the build.  It will display a simple button that can be pressed.  You should be able to cut and paste the code into your open terminal connection.

```
import lvgl as lv
from ili9XXX import ili9488g
from ft6x36 import ft6x36
disp=ili9488g()
touch=ft6x36(0, 21, 22, 100000)
scr=lv.obj()
btn=lv.btn(scr)
btn.center()
label=lv.label(btn)
label.set_text('Button')
lv.scr_load(scr)

```

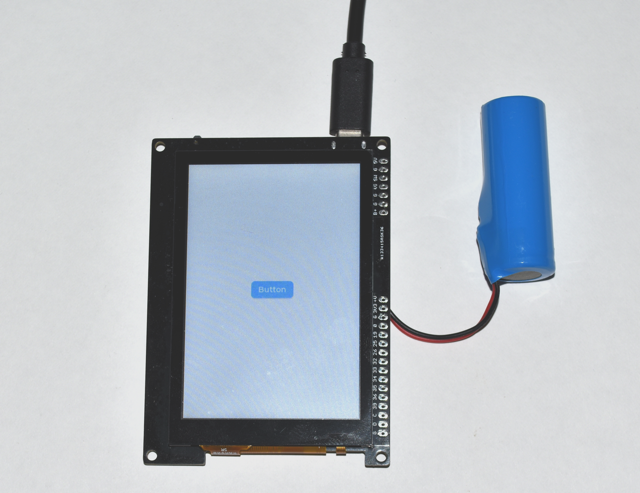
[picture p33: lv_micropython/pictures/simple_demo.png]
Simple LVGL demo


### Advanced LVGL demo
The ```demos/advanced_demo_gcore.py``` file is a modified version of the demo provided with the lv_bindings.  It displays several screens under a tab selector with the ability to swipe between pages and is a great way to see the speed-up of using 16-bit pixels.

There are several ways to load code into Micropython but I've found Adafruit's ```ampy``` utility to be easy to use.  Basic installation and usage instructions can be found [here](https://learn.adafruit.com/micropython-basics-load-files-and-run-code).

```
pip3 install adafruit-ampy
```

Once installed the demo can be downloaded to a gCore with Micropython running on it using the following command (assuming the demo is in the current diretory).  Make sure no other python code is running (reset gCore by pressing the RESET button on back).

```
ampy --port [SERIAL_PORT] run advanced_demo_gcore.py
```

You should see the following output and the gCore screen should display the demo.

```
	Single buffer
	ILI9488g initialization completed
	FT6X36 touch IC ready (fw id 0x3 rel 1, lib 1003)
```

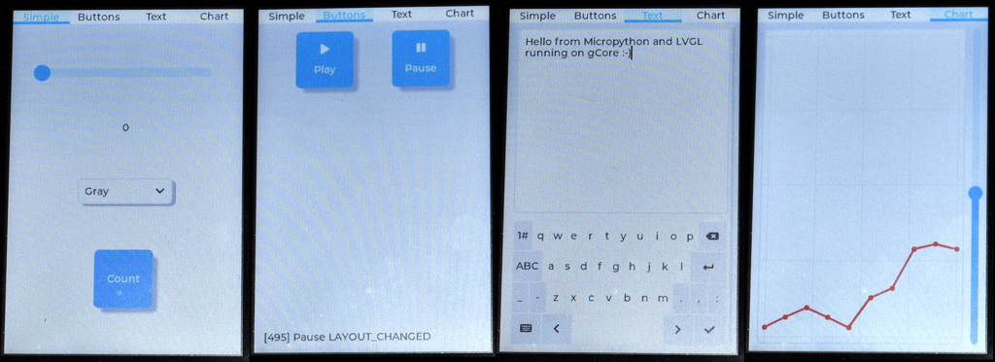
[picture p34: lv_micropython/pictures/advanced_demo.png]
Advanced Demo


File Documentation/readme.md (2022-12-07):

## gCore Documentation
This directory contains gCore documentation with PDF files stored in the ```Documents``` directory.

### gCore Subsystems

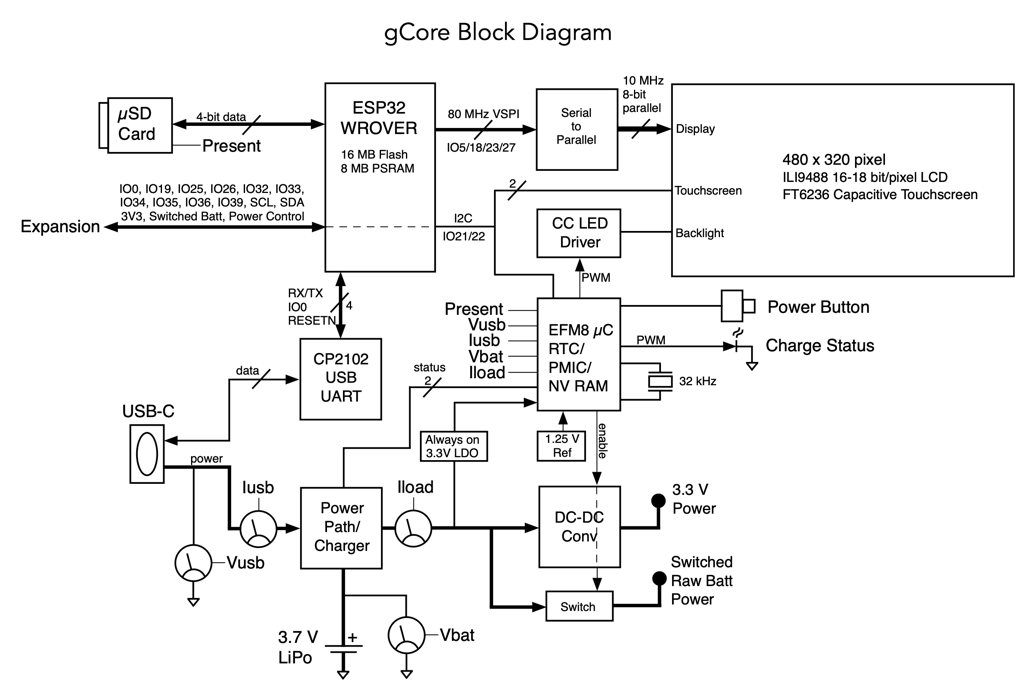
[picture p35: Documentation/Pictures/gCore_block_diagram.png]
gCore Block Diagram


1. CPU - Dual-core ESP32 with 16 MB Flash and 8 MB PSRAM.
2. Display - 480 x 320 pixel TFT LCD with ILI9488 controller, FT6236 capacitive touchscreen and PWM-based backlight control.  SPI-to-Parallel converter allows operation of the Display SPI peripheral at up to the maximum 80 MHz.
3. EFM8 - Co-processor providing Real Time Clock (RTC) with alarm, power-management, internal voltage and current monitoring, and 4096 bytes of NVRAM with 1024 bytes flash backup.
4. Micro-SD - Mass storage with high speed 4-bit data.
5. Power - 3.7V Li-Ion/LiPo with power-path charger and regulated 3.3V output.
6. USB Interface - CP2102 USB UART with auto-programming (Reset/GPIO0 boot mode entry) control.

### Power Control
gCore generates two internal 3.3V rails.  One that powers the EFM8 co-processor and is always on, and one switched by the EFM8 that powers the rest of gCore and user application circuitry.  gCore also makes a switched rail from the Charge Controller (raw battery voltage) available.  Total current from both the switched 3.3V and switched raw battery outputs, used by both gCore and user circuitry, should be approximately 1A or less.

gCore can be turned on by multiple sources.

1. Power Button Press - Pressing the button for a configurable time (20 mSec - 2.5 seconds) always switches power on.
2. RTC Alarm - An alarm value can be set in the EFM8 RTC that will turn on gCore when the Alarm time is reached.
3. Charge Start and/or Charge End - The EFM8 can be configured to turn on when charging starts or completes (full battery).

It can also be turned off by multiple sources.

1. ESP32 initiated - Code running on the ESP32 can switch power off using the EFM8.  Short Power Button Presses can be used by code for soft power off.
2. Long Power Button Press - A long Power Button press (~5 seconds) will switch power off regardless of the code running on the ESP32.
3. Critical Battery Voltage - The EFM8 switches power off if the battery voltage falls below 3.3V.  A warning is available to code running on the ESP32 prior to power off.

The EFM8 prevents power on if the battery voltage is 3.5V or less.

### Display
#### LCD Controller
The ILI9488 LCD controller is configured with an 8-bit parallel interface.  A serial-to-parallel converter connects the LCD controller to the ESP32 VSPI peripheral dedicated pins.  This allows driving the LCD controller at the maximum SPI clock rate of 80 MHz.

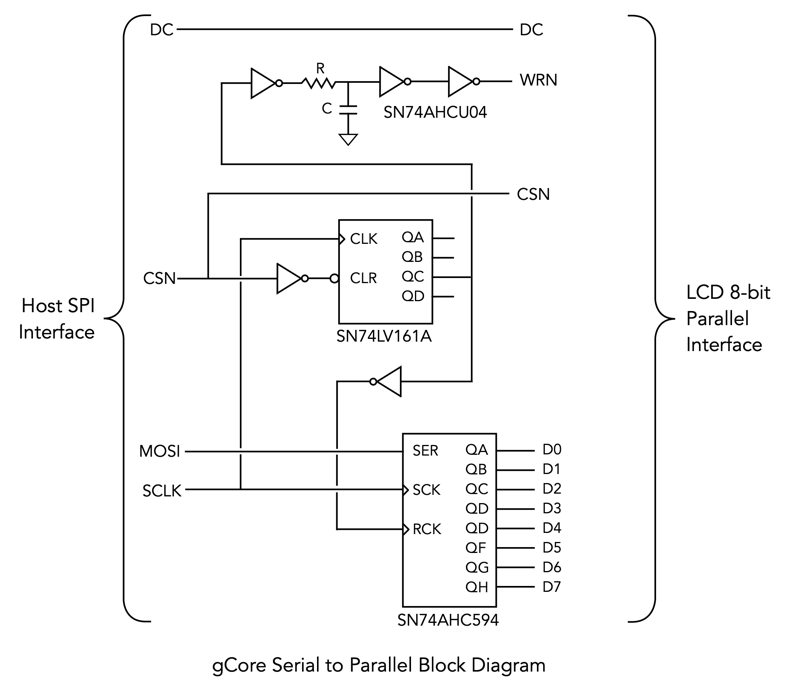
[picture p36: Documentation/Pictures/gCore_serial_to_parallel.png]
Serial-to-parallel converter


The 8-bit parallel interface allows both 16-bit (2-byte RGB565) and 18-bit (3-byte RGB666) pixels.  Sixteen-bit pixels are not available when using a SPI interface directly to the ILI9488 so you may find other ILI9488 drivers performing extra work to convert 16-bit pixels to 24-bits.

There are some specific timing requirements, described below, that must be followed.

| Specification | min | max |
| --- | --- | --- |
| CSN asserted before first rising edge of SCLK | 20 nS | |
| CSN hold after final edge of SCLK | 100 nS | |
| MOSI setup to rising edge of SCLK | 4 nS | |
| MOSI hold after rising edge of SCLK | 2 nS | |
| DC asserted before CSN asserted | 0 nS | |
| DC hold after final edge of SCLK | 100 nS | |

Primarily the CSN signal must be de-asserted after the final SCLK rising edge.  This is handled automatically by the Arduino gCore LCD driver and the ported eSPI_TFT libraries but must be specified as shown below when configuring the VSPI peripheral directly in the IDF.

```
	spi_device_interface_config_t devcfg={
            .clock_speed_hz=80000000,
            .mode=0,
            .spics_io_num=5,
            .queue_size=1,
            .pre_cb=NULL,
            .post_cb=NULL,
            .cs_ena_pretrans = 12,            // Make sure CS brackets transaction with enough
            .cs_ena_posttrans= 12,            //   time for setup/hold on serial-parallel circuit
            .flags = SPI_DEVICE_HALFDUPLEX
    };
```

#### Backlight
The LCD backlight is driven by a constant current source providing constant brightness over the full operating range of battery voltage.  Backlight brightness is controlled by a PWM output on the EFM8 co-processor and can be controlled by code running on the ESP32.  The PWM frequency is about 24 kHz.

#### Touchscreen Controller
The FT6236 capacitive touchscreen controller is an I2C device and well supported by existing drivers for both the Arduino and IDF environments.  The controller has a 7-bit I2C address of 0x38.  gCore demo software polls the controller but an interrupt pin is also available (see Misc IO below).

### Charge Management
A Microchip MCP73871 load sharing charge controller supplies 500 mA charge current to a standard 2 mm JST connector for a 3.7V Li-Ion or LiPo battery (4.2V max charge voltage).  Positive and negative battery terminal locations align with batteries sold by suppliers such as Adafruit and Sparkfun.  A jumper option allows increasing charge current to 1A (this may violate the USB limits on some computer USB ports).  The charge controller provides autonomous power source selection using USB power when available and automatically switching to battery when USB power is not available or augmenting USB power with battery power if necessary.  A safety timer shuts down charging if the battery is not charged within six hours.  A 1.5A PTC fuse is connected in series with the battery for protection.

The Charge LED provides the following status.  The status is also available to code running on the ESP32.

1. Off - No USB Power.  gCore powered by the battery.
2. On Solid - USB supplying power.  Battery charged.
3. Slowly pulsing on and off - USB supplying power.  Battery charging.
4. Blinking - USB supplying power. Charge Fault detected (e.g. safety timer expired).

gCore is designed to work with batteries from 500 mAh to about 4 Ah capacity.  The battery must be able to take the selected full charge current and be capable of being charged within the 6 hour safety timeout implemented by the charge controller.

### GPIO Utilization
ESP32 GPIO available to the user and used by gCore are shown below along with power and miscellaneous signals.

gCore Illustrated
gCore GPIO Utilization

### Micro-SD
The Micro-SD socket is configured to use the ESP32 4-bit data mode interface (SD driver).  It may also use the 1-bit data mode or be treated as a SPI device (using the ESP32 HSPI peripheral).  The GPIO12-15 signals double as a JTAG debugging port when no Micro-SD Card is installed.

The ```SD_MMC``` class is used in the Arduino environment to configure 1- or 4-bit data modes as shown below.

```
	#include <SD.h>
	#include <SD_MMC.h>
	
	void setup() {
		// Select only one of the following begin statements
		
		// 4-bit data mode
		if (!SD_MMC.begin()) {
		    Serial.println("ERROR: SD card mount failed!");
		}
		
		// 1-bit data mode
		if (!SD_MMC.begin("/sdcard", true)) {
		    Serial.println("ERROR: SD card mount failed!");
		}
	}
```

### EFM8 Operation
The EFM8 co-processor performs a variety of functions for gCore.  It operates independently from the ESP32 but may be controlled by the ESP32 through a register-based I2C interface.

1. Power Management - Power Button monitoring, soft power control, critical battery voltage shut off.
2. Charge Monitoring - Provides charge status to the ESP32, controls the charge LED.
3. Real Time Clock with Alarm - Stores real time as a 32-bit integer incremented each second with an alarm function that can be used to switch power on.  gCore library functions store epoch time and provide conversion functions to/from standard time units.
4. Internal current and voltage monitoring - Monitor and make available USB voltage and input current, battery voltage and load current to the ESP32.
5. Non-volatile RAM with partial flash backup - Provides 4096 bytes of NVRAM for use by the ESP32 to store information that can survive ESP32 power cycles.  The NVRAM is maintained as long as the EFM8 has power (battery installed).
6. Provides 1024 bytes of flash-based storage that can survive EFM8 power cycles (battery removal).
7. Backlight brightness control - Set backlight PWM value.
8. Micro-SD card detection - Monitors the Micro-SD card present switch as status for the ESP32.

The ```gCore``` Arduino library contains functions for accessing the EFM8 from ESP32 code.

#### I2C Interface
The EFM8 I2C interface has a 7-bit address of 0x12.  The maximum frequency for the I2C bus is 100 kHz (including communication with the FT6236 touchscreen controller and any user I2C peripherals).

Registers and NVRAM are addressed using a 16-bit address.

Register write cycles are shown below.

EFM8 Register Write Cycles

Register read cycles are shown below.

EFM8 Register Read Cycles

#### Register Map

| Register | Register Address | Size | Type | Description |
| --- | ---| --- | --- | --- |
| NVRAM | 0x0 - 0x3FF | 8-bit | RW | Non-volatile RAM with Flash backup |
| | 0x400 - 0xFFF | 8-bit | RW | Non-volatile RAM |
| ID | 0x1000 | 8-bit | RO | Firmware ID |
| VER | 0x1001 | 8-bit | RO | Firmare Version |
| STATUS | 0x1002 | 8-bit | RO | Device Status |
| GPIO | 0x1003 | 8-bit | RO | GPIO Input Signal Values |
| VU | 0x1004 | 16-bit | RO | USB Voltage (mV) - unsigned |
| IU | 0x1006 | 16-bit | RO | USB Current (mA) - unsigned |
| VB | 0x1008 | 16-bit | RO | Battery Voltage (mV) - unsigned |
| IL | 0x100A | 16-bit | RO | Load Current (mA) - unsigned|
| TEMP | 0x100C | 16-bit | RO | EFM8 internal temp (°C x 10) - signed |
| BACKLIGHT | 0x100E | 8-bit | RW | Backlight PWM Value (0-255) - default 128 |
| WAKE_CONTROL | 0x100F | 8-bit | RW | Automatic Power-on Control |
| SHUTDOWN | 0x1010 | 8-bit | WO | Power-off trigger |
| PWR\_BTN_TIME | 0x1011 | 8-bit | RW | Power Button short press detection time (mS x 10) - default 100 |
| NV_CONTROL | 0x1012 | 8-bit | RW | NVRAM Flash Storage control |
| TIME | 0x1013 | 32-bit | RW | Real Time Clock value (seconds) - unsigned |
| ALARM | 0x1017 | 32-bit | RW | Real Time Clock Alarm value (seconds) - unsigned |
| TIME_CORRECT | 0x101B | 32-bit | RW | Real Time Clock correction value - signed |

##### ID Register
The ID is 1.

##### Version Register
The Version Register contains two fields.

| Bits | Description |
| --- | --- |
| 7:4 | Major Revision (0-15) - Incremented for new user-visible functionality |
| 3:0 | Minor Revision (0-15) - Incremented for bug fixes |

##### Status Register
The Status register contains the following status information.

| Bits | Description |
| --- | --- |
| 7 | Critical Battery Detected - Battery voltage is 3.3V or less and power will be switched off within ten seconds |
| 6:5 | Reserved.  Read as 0 |
| 4 | Power Button Short Press detected - The Power Button was pressed longer than the period configured in the PWR\_BTN_TIME register (but shorter than the 5 second hard power-off threshold) and then released. |
| 3 | Reserved.  Reads as 0 |
| 2 | Power On due to Charge Status change (either Charge Start or Charge End as configured in the WAKE_CONTROL register) (latched) |
| 1 | Power On due to RTC Alarm (latched) |
| 0 | Power On due to Power Button Press (latched) |

##### GPIO Register
The GPIO register contains the following real-time status information from EFM8 GPIO pins.

| Bits | Description |
| --- | --- |
| 7:4 | Reserved.  Read as 0 |
| 3 | Micro-SD Card present bit |
| 2 | Power Button currently pressed bit |
| 1:0 | MCP73871 Charge Status bits |

MCP73871 Charge Status values are shown below.

| Status Bit 1 | Status Bit 0 | Charge Status |
| --- | --- | --- |
| 0 | 0 | Not charging |
| 0 | 1 | Charging |
| 1 | 0 | Charge done |
| 1 | 1 | Charge fault |

##### Voltage and Current Registers
The voltage and current registers contain filtered values.  Voltages are in mV (for example 3.9 volts will read 3900).  Current values are in mA (0.5A will read 500).

##### Temperature Register
The Temperature register contains the temperature from a sensor on the EFM8 die output as °C x 10 (for example 22.5°C will read 225).  The value is signed.  The temperature sensor is not particularly accurate.

##### Backlight Register
The Backlight register controls the PWM signal connected to the constant current backlight driver.  A value of 0 will turn the backlight off.  A value of 255 sets the backlight to full brightness (and maximum power consumption).  Since there is a non-linear function between PWM value and perceived brightness, it is often sufficient to set a value lower than 255 to obtain adequate brightness.  Upon power-on (battery attachment) the EFM8 sets this register to 128.

##### Wake Control Register
The Wake Control register enables or disables various power-on wake sources.  The Power Button control of power is always enabled.

| Bits | Description |
| --- | --- |
| 7:3 | Reserved.  Read as 0 |
| 2 | Power on when Charge Complete is detected |
| 1 | Power on when Charging is started (USB Power supplied) |
| 0 | Power on when Time Register matches Alarm Register |

Upon power-on (wake) the EFM8 sets this register to 0.  It is up to code running on the ESP32 to setup subsequent wake conditions.

##### Shutdown Register
The Shutdown register is used to switch power off.  Writing the value 0x0F to this register turns off the switched 3.3V and raw battery supply rails.  Writing any other value has no effect.  Register read values are undefined.

##### Power Button Short Press Time Register
The Power Button Short Press Time register controls the period of time the button must be pressed to detect an ESP32 visible short press.  When power is off, a short press turns power on.  When power is on pressing the button for longer than the specified time and then releasing it sets the Power Button Short Press detected bit in the Status register.  It is set in units of 10 mSec intervals with legal values 2-255 representing 20 mSec to 2.55 seconds.  Upon power-on (battery attachment) the EFM8 sets this register to 100 (for a detection period of 1 second).

##### NV Control Register
The NV Control register is used to trigger a save of the first 1024 bytes of NVRAM to EFM8 flash storage to allow this data to persist over EFM8 power cycles (battery removal), or to read the EFM8 flash storage values into the first 1024 bytes of NVRAM (the remaining 3072 bytes are unaffected).

Writing 0x57 ('W') to the register triggers a write of NVRAM to flash.  Wait at least 36 mSec after triggering the write before accessing the EFM8 as it will not respond to I2C cycles while it is erasing the flash memory in preparation to write to it.

Writing 0x52 ('R') to the register triggers a read of flash into NVRAM.

Writing NVRAM to flash takes up to approximately 128 milliseconds.  The register may be polled (after waiting an initial 36 mSec) to determine when the write is complete.  It will return the value 1 while the write is in progress and the value of 0 when the write is complete.  However it is possible for the I2C read cycle to fail if part of it occurs just as a write is occurring internal to the EFM8.  For this reason code must either be able to deal with a failed reads or just wait 36 + 128 = 164 mSec before accessing the EFM8.

##### Time Register
The Time register contains a value that is incremented every second.  It is designed to work with an epoch time system (starting Jan 1, 1970).  It is an unsigned 32-bit value and, if used with the epoch time system, will roll over in the year 2106.

The time value is latched when a read is initiated to the first (MSB) byte address.  All four bytes should be read in the same I2C transaction.

All four bytes should be written in the same I2C transaction when setting the time.  The time will be updated upon completion of the fourth (LSB) byte.

##### Alarm Register
The Alarm register contains the time that can be used to turn on gCore if the associated bit is set in the Wake Control register.  An alarm occurs when the Time register becomes equal to or greater than the Alarm register.

The Alarm register is updated after the fourth byte is written.

To set an alarm, first set the Alarm register with a time larger then the Time register and then set bit 0 in the Wake Control register.

Upon power-on (battery attachment) the EFM8 sets this register to 0.

##### Time Correct Register
The Time Correct register is used to improve the accuracy of the EFM8 RTC.  It may be written with a signed value specifying a number of seconds between time corrections.  Typically it would be written by software after observing the accuracy of the RTC over a long period of time.

A positive value is used to correct a slow RTC.  A value of 1 is added to the Time Register every time the number of seconds in the Time Correct register passes.  For example if the Time Correct register contains the value 5 then the Time register might increment as follows: 1 2 3 4 6 7 8 9 11 ... (obviously the Time Correct value will be a much larger number of seconds).

A negative value is used to correct a fast RTC.  A value of 1 is subtracted from the Time Register every time the absolute value of the number of seconds in the Time Correct register passes.

Upon power-on (battery attachment) the EFM8 sets this register to 0.  A value of 0 has no effect on the Time register (performs no correction).

#### NVRAM / Flash Storage
The EFM8 provides 4096 bytes of NVRAM at address offset 0 - 0x0FFF.  This RAM is maintained as long as the EFM8 has power (battery attached).  It may be used by the ESP32 to store persistent values if the application does not want to use the ESP32's built-in persistent storage mechanisms (for example if the ESP32 flash will often be completely erased).

The EFM8 also provides 1024 bytes of flash memory that can be used to back the first 1024 bytes of NVRAM.  This flash is copied to the first 1024 bytes of RAM when power is applied to the EFM8 (battery attachment).  Code running on the ESP32 can copy the first 1024 bytes of NVRAM back to flash using the NV Control register.  After this the values copied will be restored to NVRAM in the event the battery is disconnected and reconnected.  Code on the ESP32 can also overwrite the NVRAM with the values stored in flash at any time using the NV Control register (for example to restore a previous snapshot of data).

Initially the flash contains the value 0xFF in each byte.  This means after power-on (battery attachment) the first 1024 bytes of NVRAM will contain the value 0xFF and the remaining 3072 bytes of NVRAM will contain the value 0.

Important notes:

1. The EFM8 datasheet specifies a typical erase/write endurance for the flash memory of 30k cycles.  However it also specifies a minimum of only 1k cycles.  This is probably under worst case conditions but you should only copy the NVRAM to flash when necessary.  Avoid implementations that update flash blindly (e.g. when there is no difference between flash and NVRAM).
2. Wait at least 36 mSec after triggering a copy of NVRAM to flash memory using the NV_CONTROL register before accessing the EFM8 as it will not respond to I2C cycles while it is erasing the flash memory in preparation to write to it.
3. During the process of writing the NVRAM to flash the EFM8 will occasionally become unresponsive (during the actual flash write) and it is possible I2C cycles to it will fail.  The writing process takes a maximum of 128 mSec so it may just be easier to wait for 36 + 128 = 164 mSec after triggering the write operation before accessing the EFM8 again.

### Dimensions

gCore Dimensions

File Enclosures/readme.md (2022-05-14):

## gCore 3D Printed Enclosures
This directory contains designs and STL files for slicing and printing on a FDM printer.  Design made using [OpenSCAD](https://openscad.org/).  To the mechanical engineers and 3D modeling pros out there: Apologies in advance for my terrible coding...

1. ```handheld_1_fdm``` contains the design for a snap-together handheld enclosure designed to hold gCore and a flat LiPo battery.  It works reasonably well with a good 3D printer.
2. ```handheld_2_fdm``` contains a second version that is held together using 4x 4-40 x 0.25 inch (or metric equivalent) pan-head screws.  This design works very well.
3. ```openscad_libraries```.  A copy of Ryan Colyer's OpenSCAD support functions and a gCore model used by the enclosure designs.  This directory and the design directories must be in the same relative position when opening the OpenSCAD design.

These enclosures are for remote control type applications.  Dimensions are approximately 105 x 75 x 17 mm.  They are designed to use a flat LiPo battery like the Sparkfun [1000 mAh model](https://www.sparkfun.com/products/13813) (battery height of 6mm or less).  The battery can be attached to the bottom of the case as shown below using double sticky tape.  It may be helpful to include a skirt when slicing the enclosure base to prevent slight warping during the print.  It may also be necessary to shave extra material from the mounting posts and to drill out the screw holes in the ```handheld_2_fdm``` design to clear stray plastic threads.

### handheld\_2_fdm
Standalone Enclosure 2

Standalone Enclosure 2 Rear

Standalone Enclosure 2 Assembly

### handheld\_1_fdm
Standalone Enclosure 1

Standalone Enclosure 1 Guts

Standalone Enclosure 1 Assembly

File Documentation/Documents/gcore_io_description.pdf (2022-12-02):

# Welcome to gCore - Peripherals and Expansion

USB-C
Power/Serial

Charge LED

Micro-SD

Power Button
Micro-SD
GPIO

ESP32 Reset Button


System Power | ESP32 GPIO
2mm JST Battery Connector | Charge Current Jumper (500 mA open / 1A closed)
Qwiic I2C | Misc IO

ESP32 GPIO
SW V+
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
Switched Battery Power (500 mA max) Switched 3.3V Power (500 mA max) Ground
GPIO 0 (Shared with serial boot circuit) GPIO 19
GPIO 25 (DAC Channel 1)
GPIO 26 (DAC Channel 2)
GPIO 32
GPIO 33
GPIO 34 (Input only)
GPIO 35 (Input only)
GPIO 36 (Input only)
GPIO 39 (Input only)
I2C SCL (GPIO 22)
I2C SDA (GPIO 21)
Ground

System Power
5V
G
SW
VI
G
G
B+

USB 5V Power
Ground

Power Button (pulled high, ground to close)

Always on internal 3.3V power (50 mA max) Ground
Ground
Battery Positive terminal

Micro-SD GPIO (available when not using card) G
4
2
14
15
13
12

Ground
GPIO 4 / SD D1 (10 k-ohm pullup) GPIO 2 / SD D2 (10 k-ohm pullup)

GPIO 14 / SD CLK (10 k-ohm pullup) GPIO 15 / SD CMD (10 k-ohm pullup) GPIO 13 / SD D3 (10 k-ohm pullup) GPIO 12 / SD D2 (ESP32 internal pullup)

Sparkfun Qwiic / Adafruit STEMMA QT G
3V3
SDA
SCL

Ground (pin 1, denoted by the dot) Switched 3.3V power (500 mA max) I2C SDA (GPIO 21)
I2C SCL (GPIO 22)

Misc IO

RESETn

TS_IRQ

LCD_TE

ESP32 reset (pulled high, ground to reset) Touchscreen controller interrupt
LCD controller TE (sync) output

ILI9488 LCD Controller SPI Interface (VSPI HS) CSn
DC
SCK
MOSI

GPIO 5
GPIO 27
GPIO 18
GPIO 23

## Quick Notes

1. LCD Controller: ILI9488
2. Touchscreen controller: FT6236
3. USB UART: CP2102N
4. Battery Charger: MCP73871-2CA
5. Internal 7-bit I2C addresses
PMIC/RTC : 0x12
FT6236 : 0x38
6. Max LCD VSPI clock frequency: 80 MHz
7. Max I2C clock frequency: 100 kHz
8. Internally monitored: V-USB, I-USB, V-BATTERY, I-LOAD
9. Battery connector polarity compatible with Sparkfun and Adafruit single cell LiPo and Li-Ion batteries. Protected by a 1.5A PTC fuse. 500 mA or 1 A charge.
10. Power button on press time: default 100 mSec, programmable between 20 mSec - 2.55 seconds.
11. Power button hard off press time : 5 seconds
12. Low-battery shutdown voltage: 3.3V
13. Minimum turn-on battery voltage: 3.5V
14. Charge LED operation
Off | No USB power / Battery powering
Solid | Battery Charged / USB powering
Pulsing | Battery Charging / USB powering
Blinking | Charge Fault / USB powering

Version 2 - Copyright (c) 2022 - danjuiliodesigns, LLC

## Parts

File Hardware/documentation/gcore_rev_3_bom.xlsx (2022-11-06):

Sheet: gCore Rev 3 PCB
gCore Rev 3 PCB Specifications
Material | FR4
Layers | 2
Thickness | 1.6 mm
Copper Thickness | 1 oz
Soldermask | Black
Silkscreen | White
Finish | LF HASL
Outer Dimensions | 95 x 69 mm
Drills | 332

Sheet: gCore Rev 3 BOM
gCore Rev 3 PCB Assembly BOM
Line No | Qty | Ref Desg | Part Number | Manuf | Package/Type | Desc | Distributor Part Number | Alternate | Notes
1 | 5 | C1, C4, C5, C6, C7 | JMK107BJ475KA-T | Taiyo Yuden | SMT/0603 | Multilayer Ceramic Capacitors MLCC - 6.3VDC 4.7uF 10% X5R | Mouser 963-JMK107BJ475KA-T | TDK C1608X5R1C475K080AC | May substitute with equal or better
2 | 14 | C2, C3, C8, C9, C10, C11, C16, C20, C23, C24, C25, C26, C28, C29 | EMK107B7104KAHT | Taiyo Yuden | SMT/0603 | Multilayer Ceramic Capacitors MLCC - SMD/SMT 0603 16VDC 0.1uF 10% X7R AEC-Q200 | Mouser 963-EMK107B7104KAHT | Samsung Electro-Mechanics CL10B104KO8NNWC | May substitute with equal or better
3 | 4 | C12, C13, C17, C19 | TMK107B7105KA-T | Taiyo Yuden | SMT/0603 | Multilayer Ceramic Capacitors MLCC - SMD/SMT 0603 25VDC 1uF 10% X7R | Mouser 963-TMK107B7105KA-T | TDK CGA3E1X7R1E105K080AC | May substitute with equal or better
4 | 4 | C14, C15, C21, C22 | GRM188R60J226MEA0D | Murata | SMT/0603 | Multilayer Ceramic Capacitors MLCC - SMD/SMT 22UF 6.3V 20% 0603 | Mouser 81-GRM188R60J226ME0D | TDK C1608X5R0J226M080AC | May substitute with equal or better
5 | 2 | C18, C27 | CC0603JRNPO9BN220 | Yageo | SMT/0603 | Multilayer Ceramic Capacitors MLCC - SMD/SMT 50V 22pF C0G 0603 5% | Mouser 603-CC603JRNPO9BN220 | TDK C1608C0G1H220J080AA | May substitute with equal or better
6 | 1 | CON1 | USB4105-GF-A | Global Connector Technology (GCT) | SMT | USB Connectors USB Type C,2.0, Rec,SMT, 0.95mmTH Shell Stakes,G/F,RA,Top Mnt,T&R | Mouser 640-USB4105-GF-A | GCT USB4105-GF-A-120 | May substitute with equal or better
7 | 1 | CON2 | S2B-PH-SM4-TB(LF)(SN) | JST Sales America Inc | SMT | Connector Header Surface Mount, Right Angle 2 position 0.079" (2.00mm) | Digi-Key 455-1749-2-ND, 455-1749-1-ND, 455-1749-6-ND | Sullins Connector Solutions SWR201-NRTN-S02-HM-BG | May substitute with equal or better
8 | 1 | CON3 | ER-CON50HT-1 | EastRising Technology Co | SMT | FFC & FPC Connectors .5mm Side entry Flat Flexible Cable Conn 50Pos | Buy Display with display |  | Bought with LCD Module. Possible alternative GCT FFC2B17-50-T (Mouser 640-FFC2B17-50T)
9 | 1 | CON4 | SM04B-SRSS-TB(LF)(SN) | JST Sales America Inc | SMT | Connector Header Surface Mount, Right Angle 4 position 0.039" (1.00mm) | Digi-Key 455-1804-2-ND, 455-1804-1-ND, 455-1804-6-ND | Adafruit sells them in bags of 10 for $10 (expensive!) | May substitute with equal or better
10 | 1 | D1 | SP0503BAHTG | Littelfuse | SMT/SOT-143-4 | ESD Suppressors / TVS Diodes TVS AVAL DIODE SMT | Mouser 576-SP0503BAHTG | Diodes Incorporated DRTR5V0U2SR-7, Eaton STS142050UL08
11 | 1 | D2 | APA1606SURCK | Kingbright | SMT/0605 | Standard LEDs - SMD Red 630nm Water Clear 250mcd | Mouser 604-APA1606SURCK | ROHM SML-A12UTT86J, Broadcom ASMT-CR00 | May substitute with equal or better
12 | 1 | F1 | MF-MSMF150-2 | Bourns | SMT/1812 | Resettable Fuses - PPTC 6V 1.5A-HD 100A MAX | Mouser 652-MF-MSMF150-2 | Bel Fuse 0ZCG0150FF2C, Littlefuse MINISMDC150F-2 | May substitute with equal or better
13 | 1 | L1 | SRN3015-1R0Y | Bourns | SMT/3015 | Fixed Inductors 1uH 30% SMD 2.35A 48mOhm | Mouser 652-SRN3015-1R0Y | Bourns SRN3015TA-1R0Y, Wurth 74405031010 | May substitute with equal or better
14 | 1 | M1 | ESP32-WROVER-E-N16R8 | Espressif | SMT | WiFi Modules - 802.11 SMD Module ESP32-WROVER-E, ESP32-D0WD-V3, 3.3V 64Mbit PSRAM, 16 MB SPI flash, PCB Antenna | Mouser 356-ESP32WRVE22864PC
15 | 1 | PB1 | PTS850VM18PSMTR LFS | C&K Switches | SMT | Tactile Switches 50mA 12VDC, 180gf, Black Actuator, with Boss | Mouser 611-PTS850VM18PSMTRL | C&K PTS850VM18SMTR LFS | May substitute with equal or better
16 | 1 | PB2 | PTS530GM055SMTRLFS | C&K Switches | SMT | Tactile Switch - Straight, Round, 1.6N, 50MA, 12VDC, SPST | Mouser 611-PTS530GM055SMTR | C&K PTS530GH055SMTRLFS, PTS530GK055SMTRLFS | May substitute with equal or better
17 | 2 | Q1, Q7 | NX7002AKVL | Nexperia | SMT/SOT23-3 | MOSFET 60V N-CHANNEL, 190MA, 4.5OHM, VGS1.1V | Mouser 771-NX7002AKVL | Nexperia NX7002AK,215, Toshiba T2N7002AK,LM | May substitute with equal or better
18 | 3 | Q2, Q3, Q4 | MMBT3904-7-F | Diodes Incorporated | SMT/SOT23-3 | Bipolar Transistors - BJT 40V NPN SS Trans 60Vceo 6Vebo 200mA | Mouser 621-MMBT3904-F | Nexperia PMBT3904,235, Panjit MMBT3904_R1_00001, Diodes MMBT3904-7-F | May substitute with equal or better
19 | 2 | Q5, Q6 | BSS4130AT116 | ROHM Semiconductor | SMT/SOT23-3 | Bipolar Transistors - NPN 30V, VCE SAT90MV, 1A | Mouser 755-BSS4130AT116 | Rohm BSS4130AHZGT116, On Semi 2SD1048-6-TB-E | May substitute with equal or better
20 | 1 | Q8 | SI2315BDS-T1-E3 | Vishay | SMT/SOT23-3 | MOSFET P-CHANNEL VDS12V, ID3A, RDS50mOHM, VGS0.9V | Mouser 781-SI2315BDS-E3 | Vishay SI2315BDS-T1-BE3, Nexperia PMV50XPR | May substitute with equal or better
21 | 4 | R1, R2, R38, R39 | RC0603FR-075K1L | Yageo | SMT/0603 | Thick Film Resistors - SMD 5.1 kOhms 100mW 0603 1% | Mouser 603-RC0603FR-075K1L | Panasonic ERJ-3EKF5101V | May substitute with equal or better
22 | 4 | R3, R8, R26, R44 | RC0603FR-071KL | Yageo | SMT/0603 | Thick Film Resistors - SMD 1 kOhms 100mW 0603 1% | Mouser 603-RC0603FR-071KL | Panasonic ERJ-3EKF1001V | May substitute with equal or better
23 | 1 | R4 | RC0603FR-1322K1L | Yageo | SMT/0603 | Thick Film Resistors - SMD 22.1kOhms 100-200 mW 0603 1% | Mouser 603-RC0603FR-1322K1L | Panasonic ERJ-3EKF2212V | May substitute with equal or better
24 | 3 | R5, R25, R40 | RC0603FR-1347K5L | Yageo | SMT/0603 | Thick Film Resistors - SMD 47.5kOhms 100-200 mW 0603 1% | Mouser 603-RC0603FR-1347K5L | Panasonic ERJ-3EKF4752V | May substitute with equal or better
25 | 4 | R6, R9, R19, R21 | RC0603FR-0740K2L | Yageo | SMT/0603 | Thick Film Resistors - SMD 40.2 kOhms 100mW 0603 1% | Mouser 603-RC0603FR-0740K2L | Panasonic ERJ-3EKF4022V | May substitute with equal or better
26 | 14 | R7, R14, R20, R24, R29, R30, R31, R32, R33, R34, R35, R36, R37, R47 | RC0603FR-0710KL | Yageo | SMT/0603 | Thick Film Resistors - SMD 10 kOhms 100mW 0603 1% | Mouser 603-RC0603FR-0710KL | Panasonic ERJ-3EKF1002V | May substitute with equal or better
27 | 1 | R23 |  |  |  |  |  |  | Do Not Populate
28 | 2 | R10, R13 | RC0603FR-0715KL | Yageo | SMT/0603 | Thick Film Resistors - SMD 15 kOhms 100mW 0603 1% | Mouser 603-RC0603FR-0715KL | Panasonic ERJ-3EKF1502V | May substitute with equal or better
29 | 3 | R11, R12, R41 | RE0603FRE072KL | Yageo | SMT/0603 | Thick Film Resistors - SMD 2 kOhms 100 mW 0603 1% | Mouser 603-RE0603FRE072KL | Panasonic ERJ-3EKF2001V | May substitute with equal or better
30 | 2 | R15, R17 | UR73VD2ATTD20L0F | KOA Speer | SMT/0805 | Current Sense Resistors - SMD 1/2W 0.02 Ohm 1% 75ppm | Mouser 660-UR73VD2ATTD20L0F | Panasonic ERJ-6CWFR020V | May substitute with equal or better
31 | 2 | R16, R18 | RC0603FR-13100RL | Yageo | SMT/0603 | Thick Film Resistors - SMD 100 Ohms 100-200 mW 0603 1% | Mouser 603-RC0603FR-13100RL | Panasonic ERJ-3EKF1000V | May substitute with equal or better
32 | 1 | R22 |  |  |  |  |  |  | Do Not Populate
33 | 1 | R27 | RC0603FR-07330RL | Yageo | SMT/0603 | Thick Film Resistors - SMD 330 Ohms 100mW 0603 1% | Mouser 603-RC0603FR-07330RL | Panasonic ERJ-3EKF3300V | May substitute with equal or better
34 | 1 | R28 | RC0603FR-071ML | Yageo | SMT/0603 | Thick Film Resistors - SMD 1 MOhms 100mW 0603 1% | Mouser 603-RC0603FR-071ML | Panasonic ERJ-3EKF1004V | May substitute with equal or better
35 | 2 | R42, R43 | ERJ-3BQF2R4V | Panasonic | SMT/0603 | Current Sense Resistors - SMD 0603 2.4ohm 1% Curr Sense | Mouser 667-ERJ-3BQF2R4V | Panasonic ERJ-3BQF2R4V | May substitute with equal or better
36 | 2 | R45, R46 | RC0603FR-0733RL | Yageo | SMT/0603 | Thick Film Resistors - SMD 33 Ohms 100mW 0603 1% | Mouser 603-RC0603FR-0733RL | Panasonic ERJ-3EKF33R0V | May substitute with equal or better
37 | 1 | S1 | 104031-0811 | Molex | SMT | Memory Card Connectors MICRO SD PUSH-PULL SMT 1.42MM HEIGHT | Mouser 538-104031-0811 |  | May substitute with equal or better
38 | 1 | U1 | CP2102N-A02-GQFN24 | Silicon Laboratories | SMT/QFN24 | USB Interface IC USBXpress - USB to UART Bridge QFN24 | Mouser 634-CP2102NA02GQFN24
39 | 1 | U2 | MCP73871-2CAI/ML | Microchip | SMT/QFN20 | Battery Management USB/AC Battery Charger | Mouser 579-MCP73871-2CAI/ML | Microchip MCP73871-2CCI/ML
40 | 1 | U3 | INA2180A2IDSGR | Texas Instruments | SMT/WSON | Current Sense Amplifiers 26V, dual channel, 350kHz current sense amplifier 8-WSON -40 to 125 | Mouser 595-INA2180A2IDSGR | Texas Instruments INA2180A2IDSGT
41 | 1 | U4 | NCP170ASN330T2G | On Semi | SMT/SOT23-5 | LDO Voltage Regulators ULTRA-LOW IQ 150 MA CMOS LDO REGULATOR ACT DISCHARGE VOUT= 3.3V | Mouser 863-NCP170ASN330T2G | Microchip MIC5245-3.3YM5-TR | May substitute with equal or better
42 | 1 | U5 | TPS62082DSGR | Texas Instruments | SMT/WSON | Switching Voltage Regulators 1.2A HIGH EFF STEP DOWN CONVERTER | Mouser 595-TPS62082DSGR | Texas Instruments TPS62082DSGT | May substitute with TPS62080 but must include R22 and R23.
43 | 1 | U6 | EFM8SB20F32G-B-QFN24 | Silicon Laboratories | SMT/QFN24 | 8-bit Microcontrollers - MCU 8051 25 MHz 32 kB flash 4 kB RAM 8-bit Sleepy Bee MCU | Mouser 634-EFM8SBF32GBQFN24
44 | 1 | U7 | MCP1501T-12E/CHY | Microchip | SMT/SOT23-6 | Voltage References Precision Buffered 1.25V 0.1% 50PPM | Mouser 579-MCP1501T-12E/CHY |  | May substitute with equal or better
45 | 1 | U8 | SN74LV161APWR | Texas Instruments | SMT/TSSOP-16 | Counter ICs 4-Bit Synch Binary | Mouser 595-SN74LV161APWR | Texas Instruments SN74LV161APWRG4, SN74LV161APW | May substitute with equal or better
46 | 1 | U9 | SN74AHC594PWRG4 | Texas Instruments | SMT/TSSOP-16 | Counter Shift Registers 8Bit Shift Register | Mouser 595-SN74AHC594PWRG4 | Texas Instruments SN74AHC594PW, SN74AHC594PWR | May substitute with equal or better
47 | 1 | U10 | SN74AHCU04PW | Texas Instruments | SMT/TSSOP-14 | Inverters HEX INVERTERS | Mouser 595-SN74AHCU04PW | Texas Instruments SN74AHCU04PWR, SN74AHCU04PWRG4 | May substitute with equal or better
48 | 1 | U11 | LM358WDT | STMicroelectronics | SMT/SOIC-8 | Operational Amplifiers - Op Amps Low power dual operational amplifiers | Mouser 511-LM358WDT | STMicroelectronics LM358AWDT | May substitute with equal or better
49 | 1 | XTAL1 | ECS-.327-12.5-34B | ECS | SMT/3215 | Crystals SM 12.5PF WATCH XTAL 20PPM | Mouser 520-ECS-327-12.5-34B | Abracon ABS07-32.768KHZ-T, ECS ECS-.327-12.5-34B-TR, Seiko SC32S-12.5PF20PPM, Plettronics SM8S-32.768K-20 | May substitute with equal or better

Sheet: gCore Rev 3 Assembly
gCore Rev 3 PCB Assembly
LCD Display | ER-TFT035-6 w Capacitive Touchscreen | buydisplay.com
Double Sticky Tape | Mount LCD to PCB Bottom using 2.5” strips

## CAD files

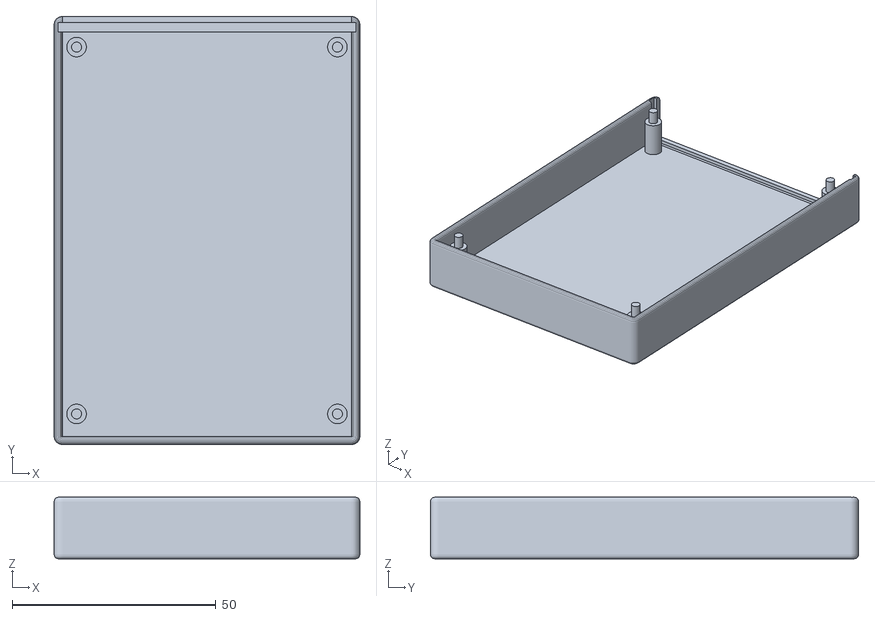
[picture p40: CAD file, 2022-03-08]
Enclosures/handheld_1_fdm/standalone_enclosure_1_base.stl
75.0 x 105.0 x 15.1

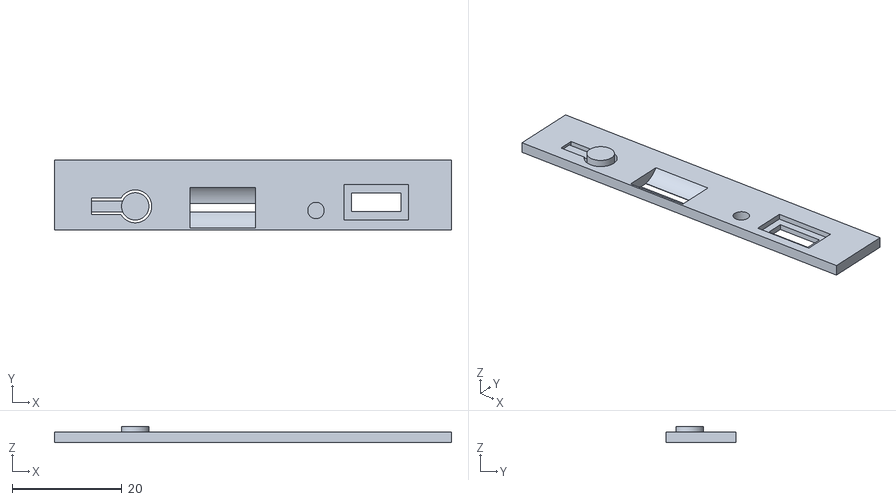
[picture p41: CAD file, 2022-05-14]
Enclosures/handheld_2_fdm/standalone_enclosure_2_io.stl
72.5 x 12.8 x 3.00

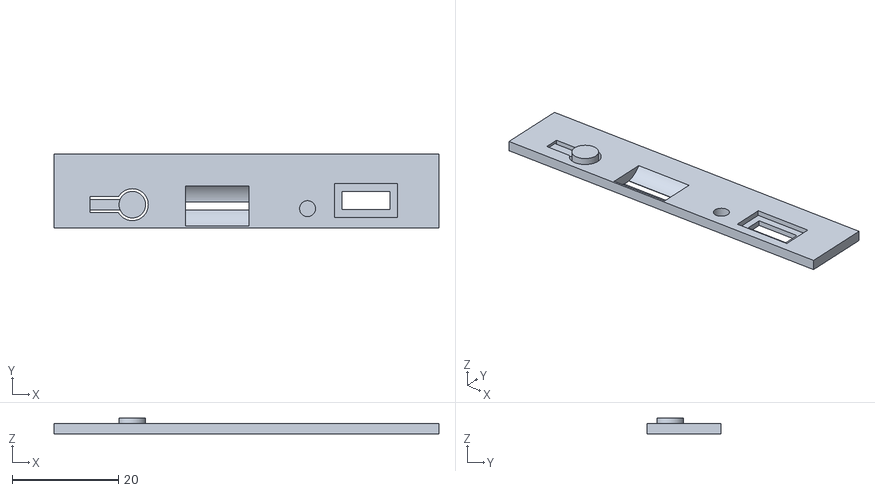
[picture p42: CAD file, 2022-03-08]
Enclosures/handheld_1_fdm/standalone_enclosure_1_end.stl
72.5 x 13.8 x 3.00

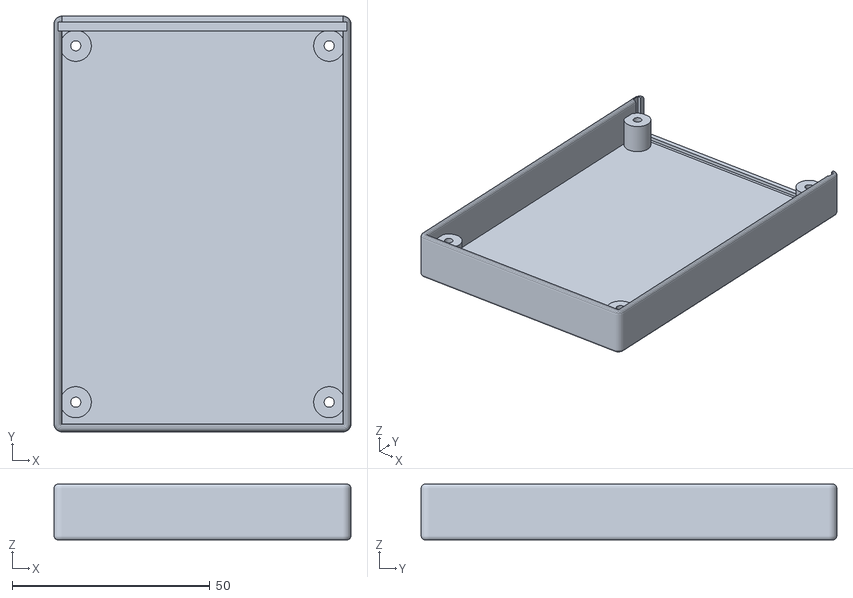
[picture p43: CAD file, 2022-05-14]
Enclosures/handheld_2_fdm/standalone_enclosure_2_base.stl
75.0 x 105.0 x 14.1

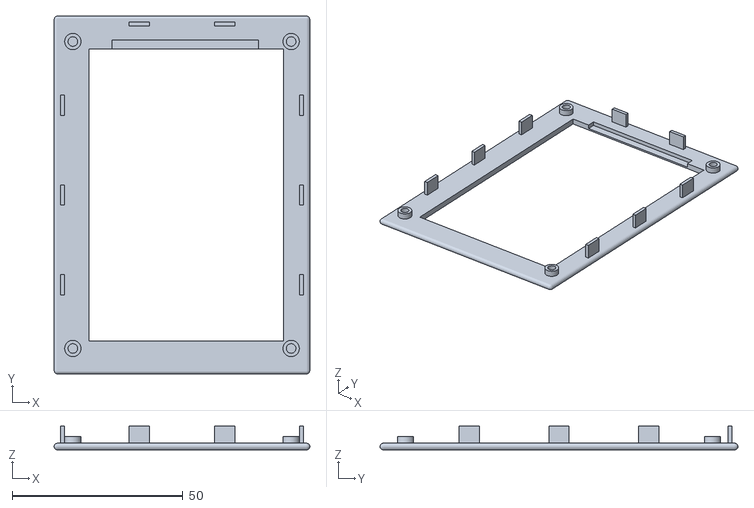
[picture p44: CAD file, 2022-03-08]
Enclosures/handheld_1_fdm/standalone_enclosure_1_bezel.stl
75.0 x 105.0 x 6.98

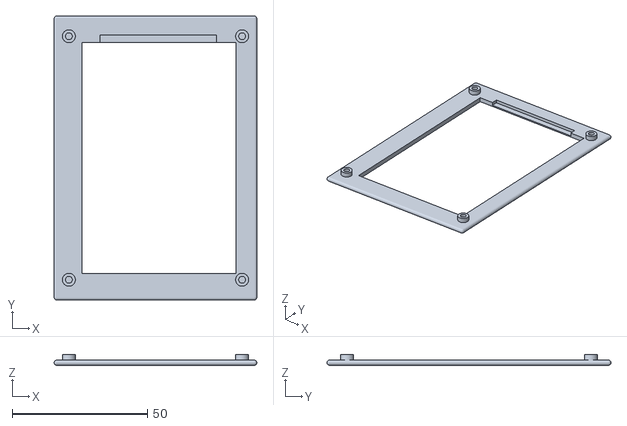
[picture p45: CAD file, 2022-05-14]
Enclosures/handheld_2_fdm/standalone_enclosure_2_bezel.stl
75.0 x 105.0 x 3.98

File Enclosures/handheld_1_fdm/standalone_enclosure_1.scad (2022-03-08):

//
// gCore standalone enclosure base supporting a small, flat Li-Ion battery
// for printing on a FDM 3D printer.  Battery height should be 6mm or less.
//
// Copyright 2022 (c) Dan Julio
//
// Apologies as I'm not a mechanical engineer and this is a big 'ole hack...  But
// it gets the job done after a fashion.
//
// Dimensions are mm.
//
// Version 1.0 - Initial release
//
// standalone_enclosure is free software: you can redistribute it and/or modify
// it under the terms of the GNU General Public License as published by
// the Free Software Foundation, either version 3 of the License, or
// (at your option) any later version.
//
// standalone_enclosure is distributed in the hope that it will be useful,
// but WITHOUT ANY WARRANTY; without even the implied warranty of
// MERCHANTABILITY or FITNESS FOR A PARTICULAR PURPOSE.  See the
// GNU General Public License for more details.
//
// You should have received a copy of the GNU General Public License
// along with standalone_enclosure.  If not, see <https://www.gnu.org/licenses/>.
//
//
use <../openscad_libraries/smooth_prim.scad>
use <../openscad_libraries/gcore.scad>

//
// Render control
//   1 - Draw Base for STL export
//   2 - Draw IO Assembly for STL export
//   3 - Draw Bezel for STL export
//   4 - Draw Base and IO Assembly for debug
//   5 - Draw all parts for debug
render_mode = 5;

//
// Definitions
//

// gCore PCB Dimensions (taken from gCore)
gcore_width = 69;
gcore_depth = 95;
gcore_height = 1.6;
gcore_lcd_width = 56.5;
gcore_lcd_depth = 85;
gcore_lcd_height = 4;
gcore_lcd_offset_x = 7.5;
gcore_lcd_offset_y = 5;
gcore_mnt_hole_d = 2.8;
gcore_mnt_hole_inset = 2.5;

// Base Dimensions
top_wall_thickness = 2;
wall_thickness = 2;
encl_open_space_height = 9.5;
encl_offset_x = 3;
encl_offset_y = 5;

encl_width = gcore_width + 2*encl_offset_x;
encl_depth = gcore_depth + 2*encl_offset_y;
encl_height = encl_open_space_height + gcore_height + wall_thickness + (gcore_lcd_height - top_wall_thickness);

// Base Mounting posts
encl_mnt_post_d = gcore_mnt_hole_d - 0.35;
encl_mnt_base_d = gcore_mnt_hole_d + 2;
encl_mnt_inset_x = (encl_width - gcore_width)/2 + gcore_mnt_hole_inset;
encl_mnt_inset_y = (encl_depth - gcore_depth)/2 + gcore_mnt_hole_inset;
encl_mnt_x = [encl_mnt_inset_x, encl_width - encl_mnt_inset_x, encl_mnt_inset_x, encl_width - encl_mnt_inset_x];
encl_mnt_y = [encl_mnt_inset_y, encl_mnt_inset_y, encl_depth - encl_mnt_inset_y, encl_depth - encl_mnt_inset_y];
encl_mnt_base_h = wall_thickness + encl_open_space_height;
encl_mnt_post_h = encl_mnt_base_h + gcore_height + (gcore_lcd_height - top_wall_thickness);

// Base IO Assy mounting dimensions
encl_io_assy_tolerance = 0.25;
encl_io_assy_thickness = 2 + 2 * encl_io_assy_tolerance;
encl_io_assy_x_offset = 1;
encl_io_assy_y_offset = encl_depth - encl_io_assy_thickness - 1 - encl_io_assy_tolerance;
encl_io_assy_z_offset = 1;

// IO Assembly Dimensions (taken from gCore)
// This is a block extending the depth of gCore, above
// and below the PCB with cutouts for the USB connector,
// Micro-SD card and power button cap/cutout.  In addition it
// provides a very thin wall for the charge LED to light
// through.  A cutout should be made in the outside
// enclosure starting at the top of the wall to access
// this assembly.
io_assy_x_offset = encl_io_assy_x_offset + encl_io_assy_tolerance;
io_assy_y_offset = encl_io_assy_y_offset + encl_io_assy_tolerance;
io_assy_z_offset = 1;
io_assy_width = encl_width - 2 * encl_io_assy_x_offset - 2 * encl_io_assy_tolerance;
io_assy_height = encl_height - io_assy_z_offset - encl_io_assy_tolerance;
io_assy_depth = encl_io_assy_thickness - 2 * encl_io_assy_tolerance;
io_assy_btn_center_x = 13 + (encl_width - gcore_width)/2 - io_assy_x_offset;
io_assy_btn_center_y = 0;
io_assy_btn_center_z = encl_open_space_height + (wall_thickness - encl_io_assy_x_offset) - 1;
io_assy_btn_d = 5;
io_assy_btn_h = 1; // Height above surface
io_assy_btn_gap = 0.5;
io_assy_btn_hole_d = io_assy_btn_d + 2*io_assy_btn_gap;
io_assy_btn_cutout_w = 3;
io_assy_btn_cutout_l = 8;
io_assy_btn_lever_depth = io_assy_depth - 0.5;
io_assy_sd_height = 1.5;
io_assy_sd_width = 12;
io_assy_sd_cyl_d = 9;
io_assy_sd_center_x = 29 + (encl_width - gcore_width)/2 - io_assy_x_offset;
io_assy_sd_center_y = -1;
io_assy_sd_center_z = encl_open_space_height + (wall_thickness - encl_io_assy_x_offset) - 0.75;
io_assy_led_center_x = 46 + (encl_width - gcore_width)/2 - io_assy_x_offset;
io_assy_led_center_y = 0.25; // Window thickness
io_assy_led_center_z = encl_open_space_height + (wall_thickness - encl_io_assy_x_offset) - 0.25;
io_assy_led_hole_d = 3;
io_assy_usb_height = 3.4;
io_assy_usb_width = 9;
io_assy_usb_center_x = 57 + (encl_width - gcore_width)/2 - io_assy_x_offset;
io_assy_usb_center_y = -1;
io_assy_usb_center_z = encl_open_space_height + (wall_thickness - encl_io_assy_x_offset) - 1.75;
io_assy_usb_wall_thick = 1;
io_assy_usb_cutout_height = io_assy_usb_height + 3;
io_assy_usb_cutout_width = io_assy_usb_width + 2.8;

// Small button cutout on bottom
btn_cutout_width = 2.4;
btn_cutout_height = 1.6;
btn_cutout_depth = 0.75;
btn_cutout_offset_x = -(btn_cutout_width/2);
btn_cutout_offset_z = -(btn_cutout_height/2);


// Bezel Dimensions
bezel_width = encl_width;
bezel_depth = encl_depth;
bezel_height = top_wall_thickness;

bezel_cutout_tolerance = 0.25;
bezel_cutout_offset_x = encl_offset_x + gcore_lcd_offset_x - bezel_cutout_tolerance;
bezel_cutout_offset_y = encl_offset_y + gcore_lcd_offset_y - bezel_cutout_tolerance;

// Bezel LCD flex wiring cutout
bezel_flex_offset_x = encl_offset_x + 14;
bezel_flex_offset_y = encl_offset_y + gcore_lcd_offset_y - 3;
bezel_flex_offset_depth = 3;
bezel_flex_offset_width = 43;
bezel_flex_offset_height = bezel_height - 0.6;

// Bezel Mounting posts
bezel_mnt_post_d = gcore_mnt_hole_d + 2;
bezel_mnt_drill_d = gcore_mnt_hole_d;
bezel_mnt_post_h = gcore_lcd_height - bezel_height;

// Bezel clips
bezel_clip_width = 6;
bezel_clip_height = 5 + 0.5;
//bezel_clip_depth = 1;
bezel_clip_depth = 1.15;
bezel_clip_z_offset = bezel_mnt_post_h + 0.5;
//bezel_clip_wall_offset = wall_thickness;
bezel_clip_wall_offset = wall_thickness - 0.15;
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

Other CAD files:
Enclosures/handheld_2_fdm/standalone_enclosure_2.scad
Enclosures/openscad_libraries/gcore.scad
Enclosures/openscad_libraries/smooth_prim.scad

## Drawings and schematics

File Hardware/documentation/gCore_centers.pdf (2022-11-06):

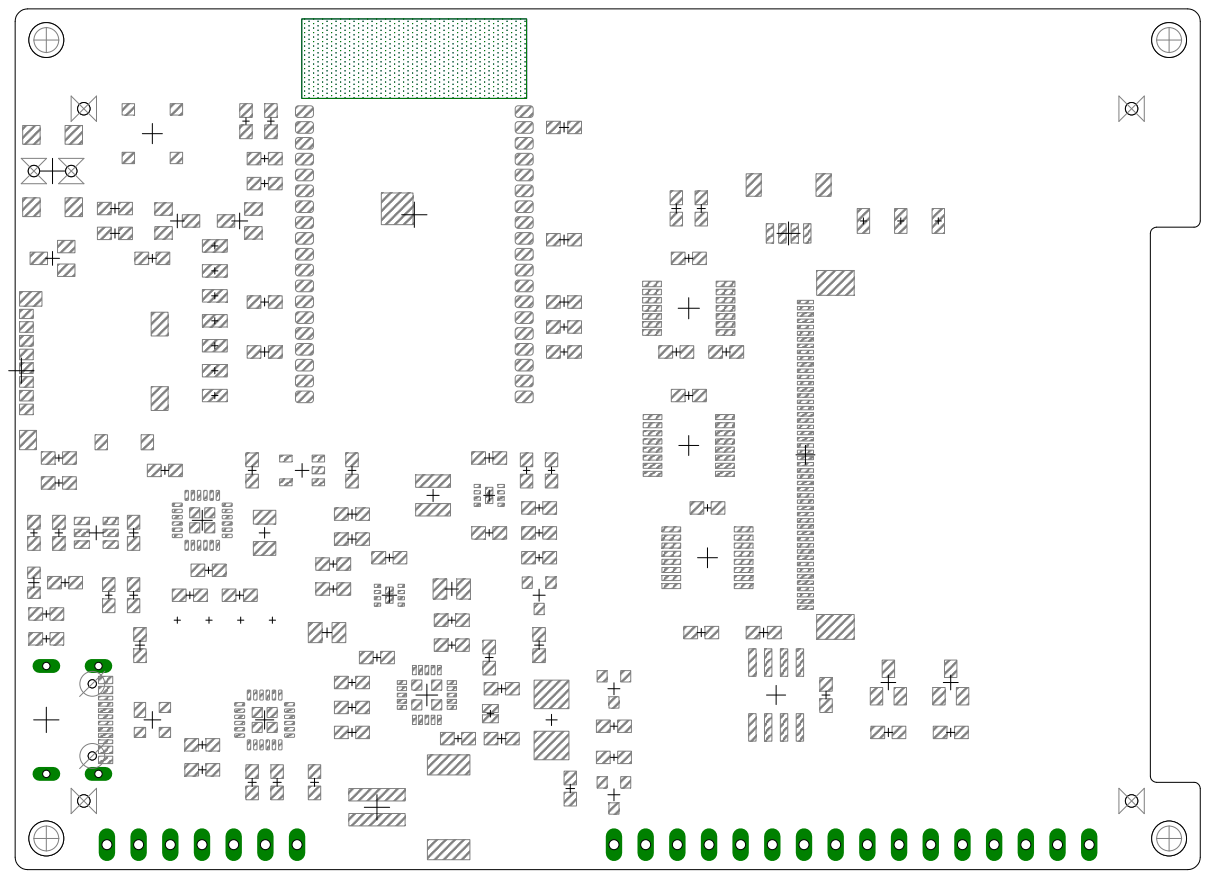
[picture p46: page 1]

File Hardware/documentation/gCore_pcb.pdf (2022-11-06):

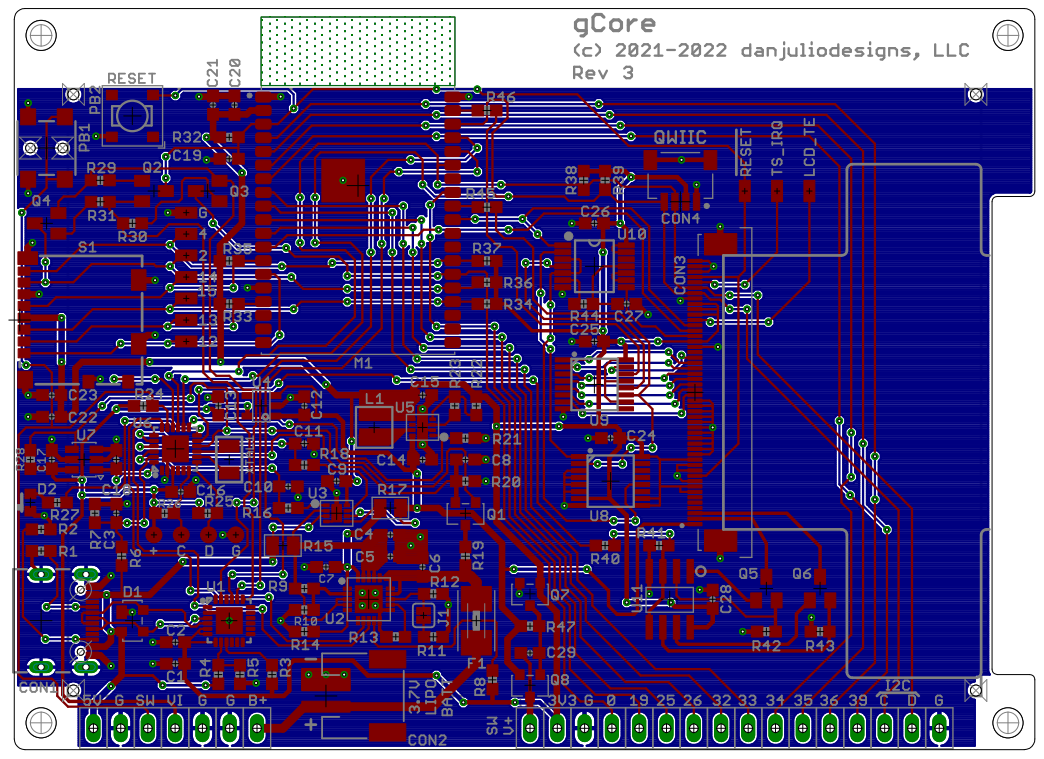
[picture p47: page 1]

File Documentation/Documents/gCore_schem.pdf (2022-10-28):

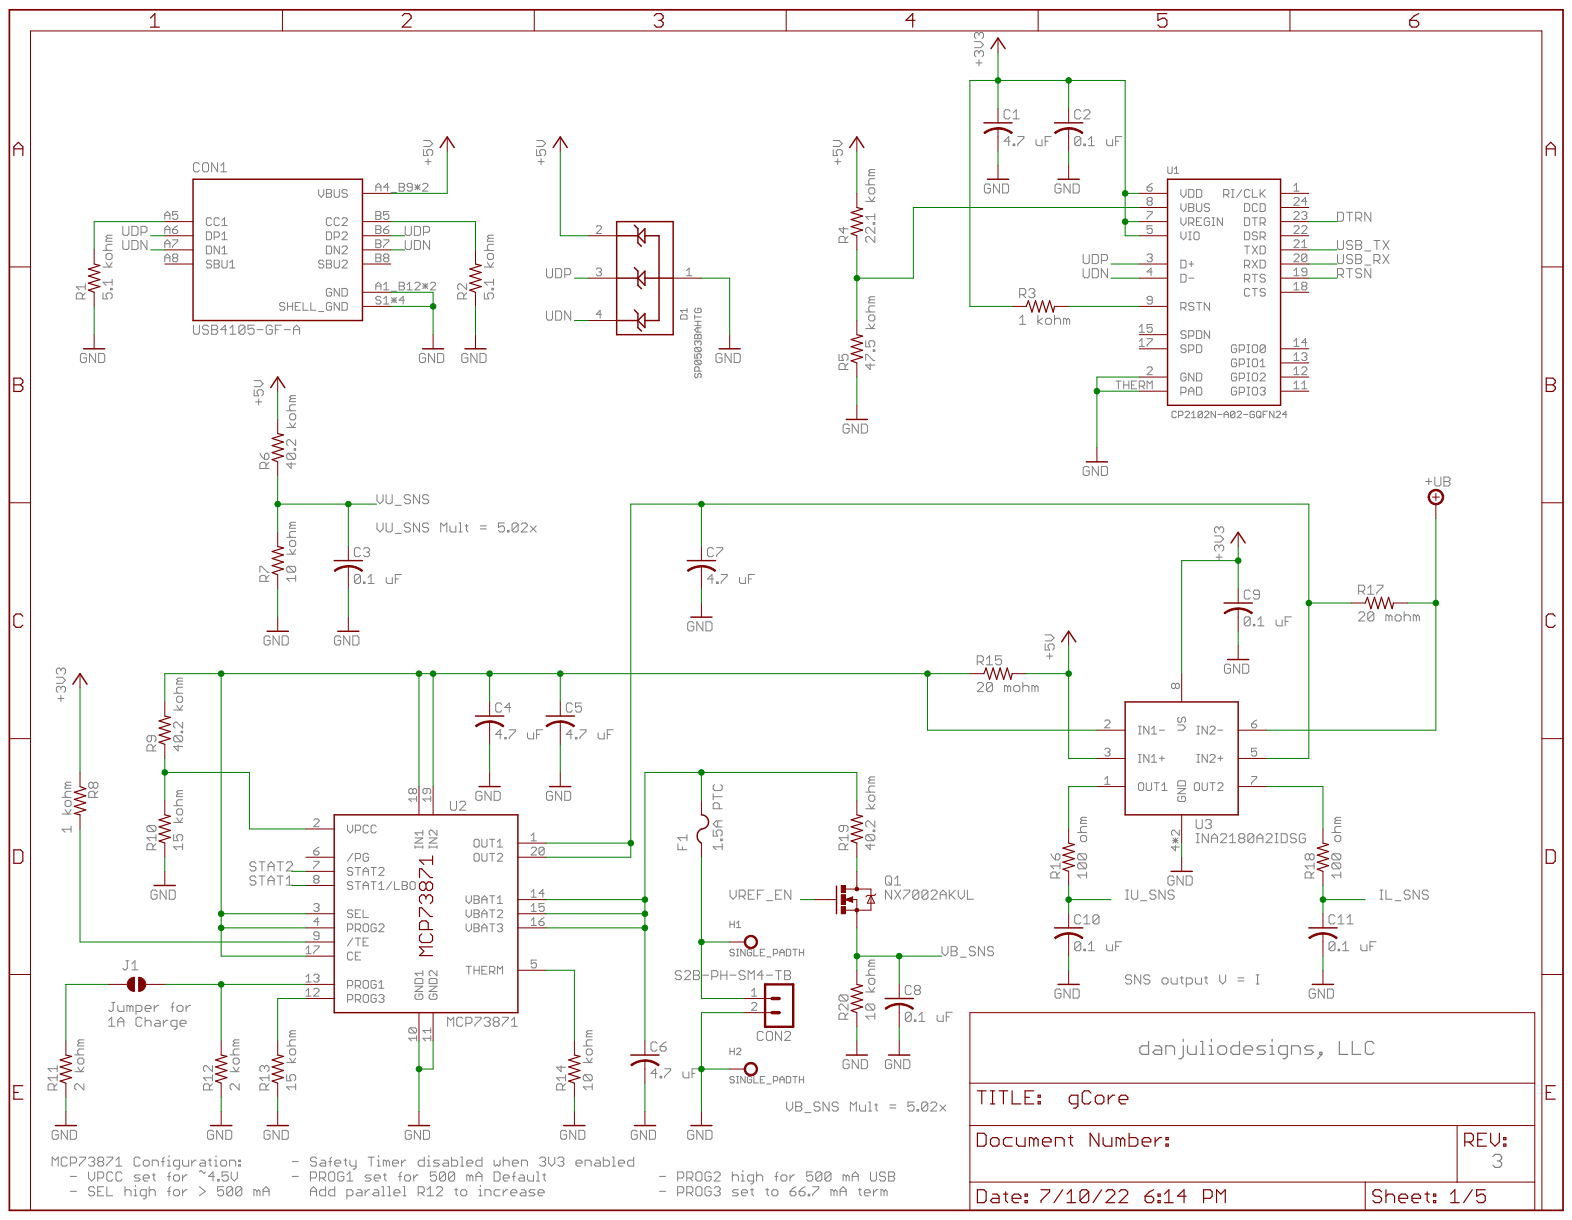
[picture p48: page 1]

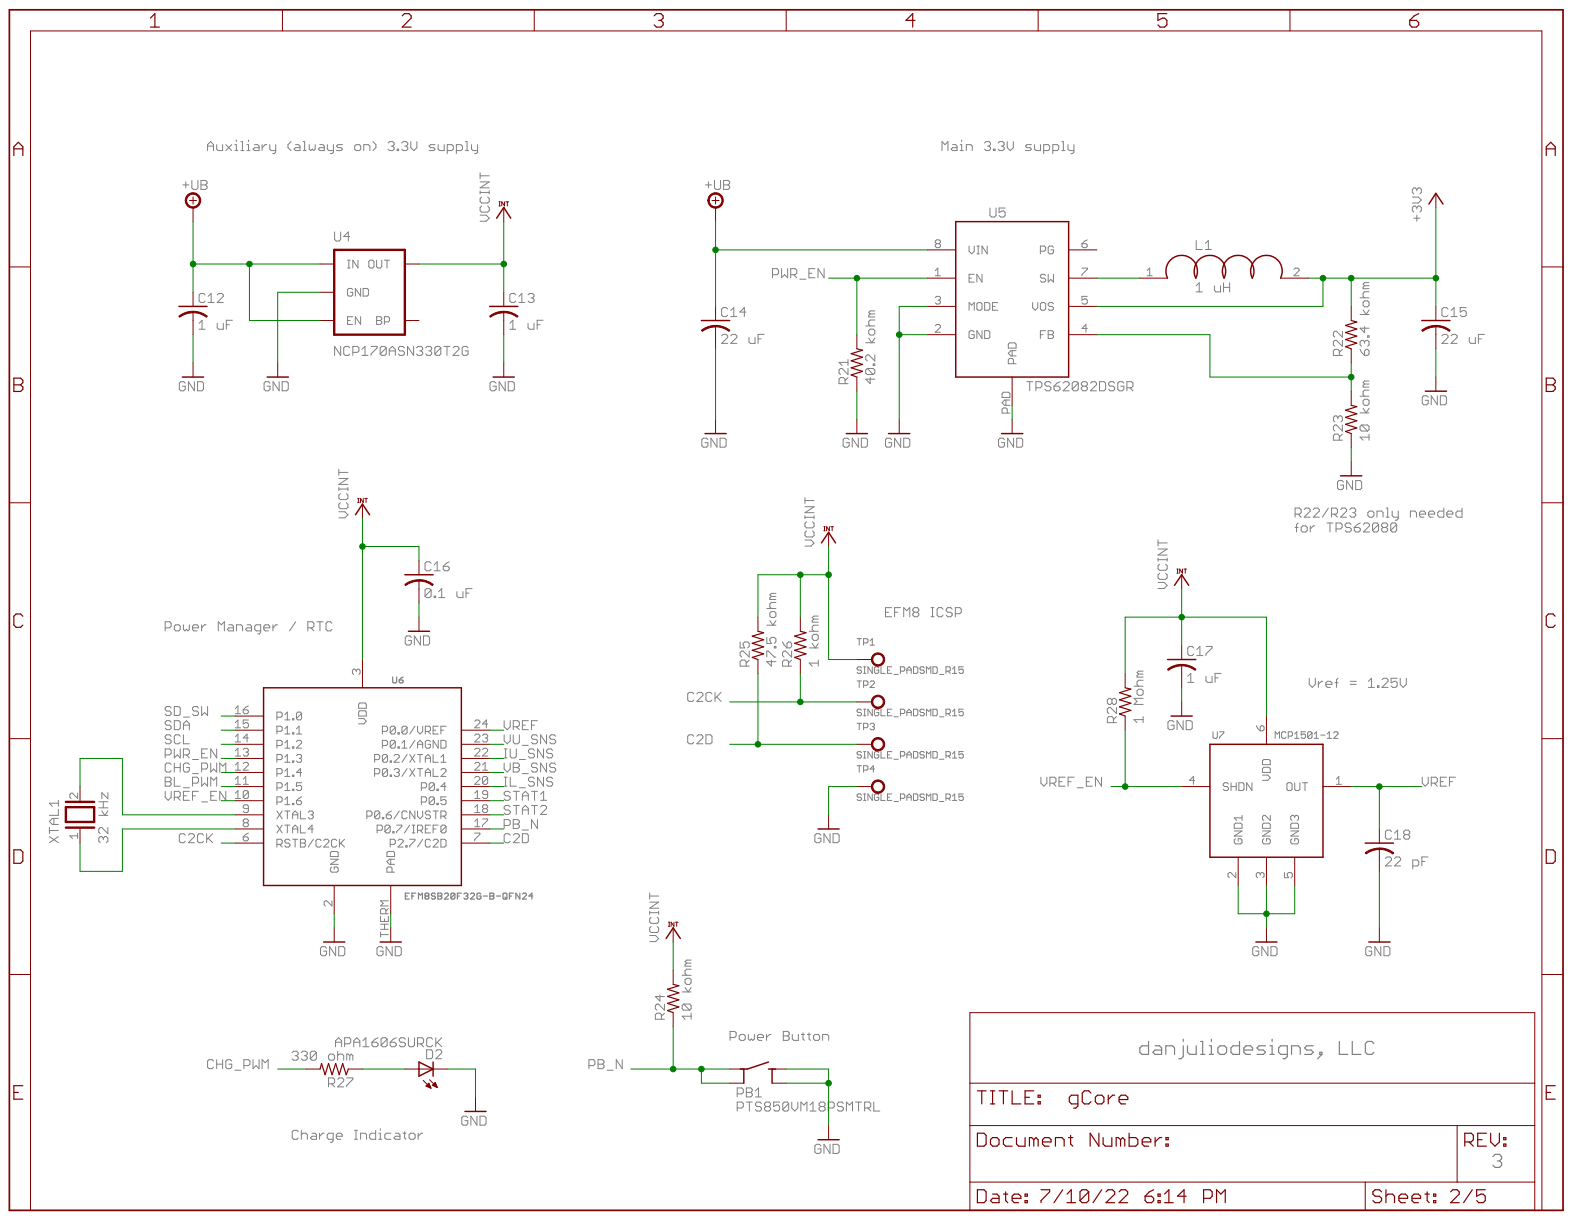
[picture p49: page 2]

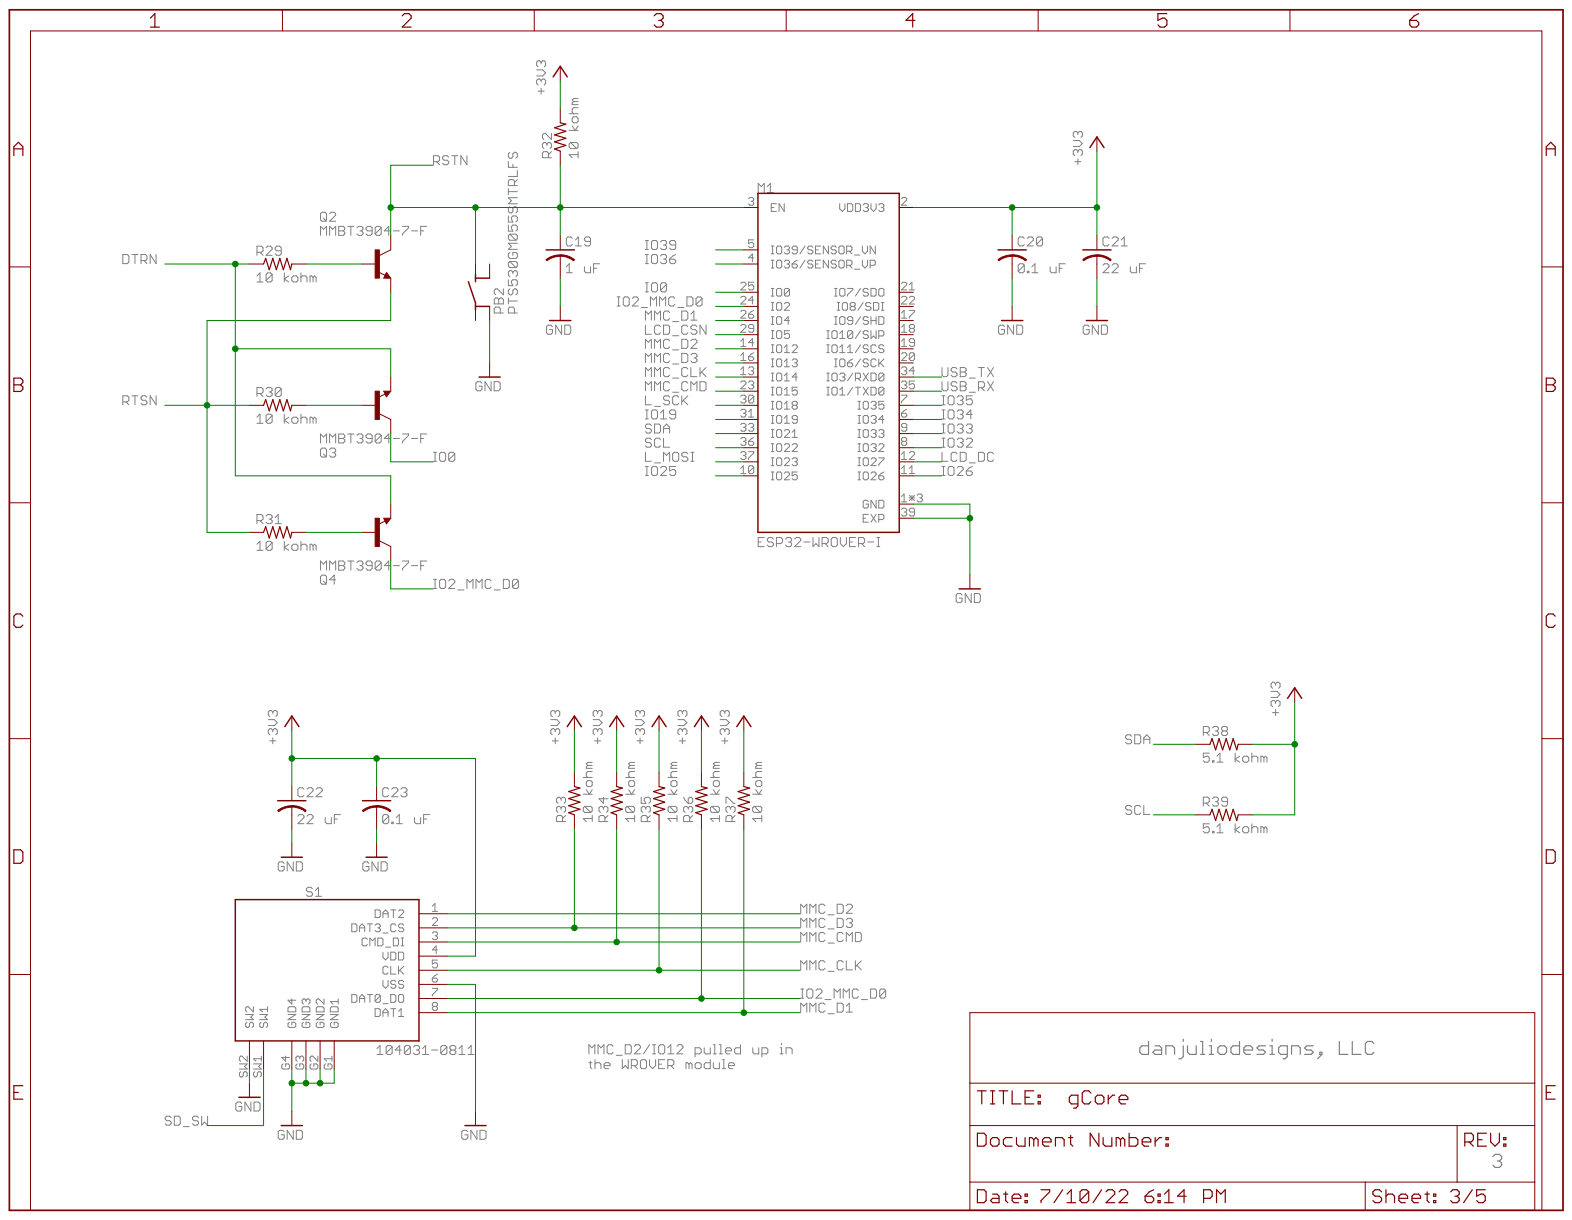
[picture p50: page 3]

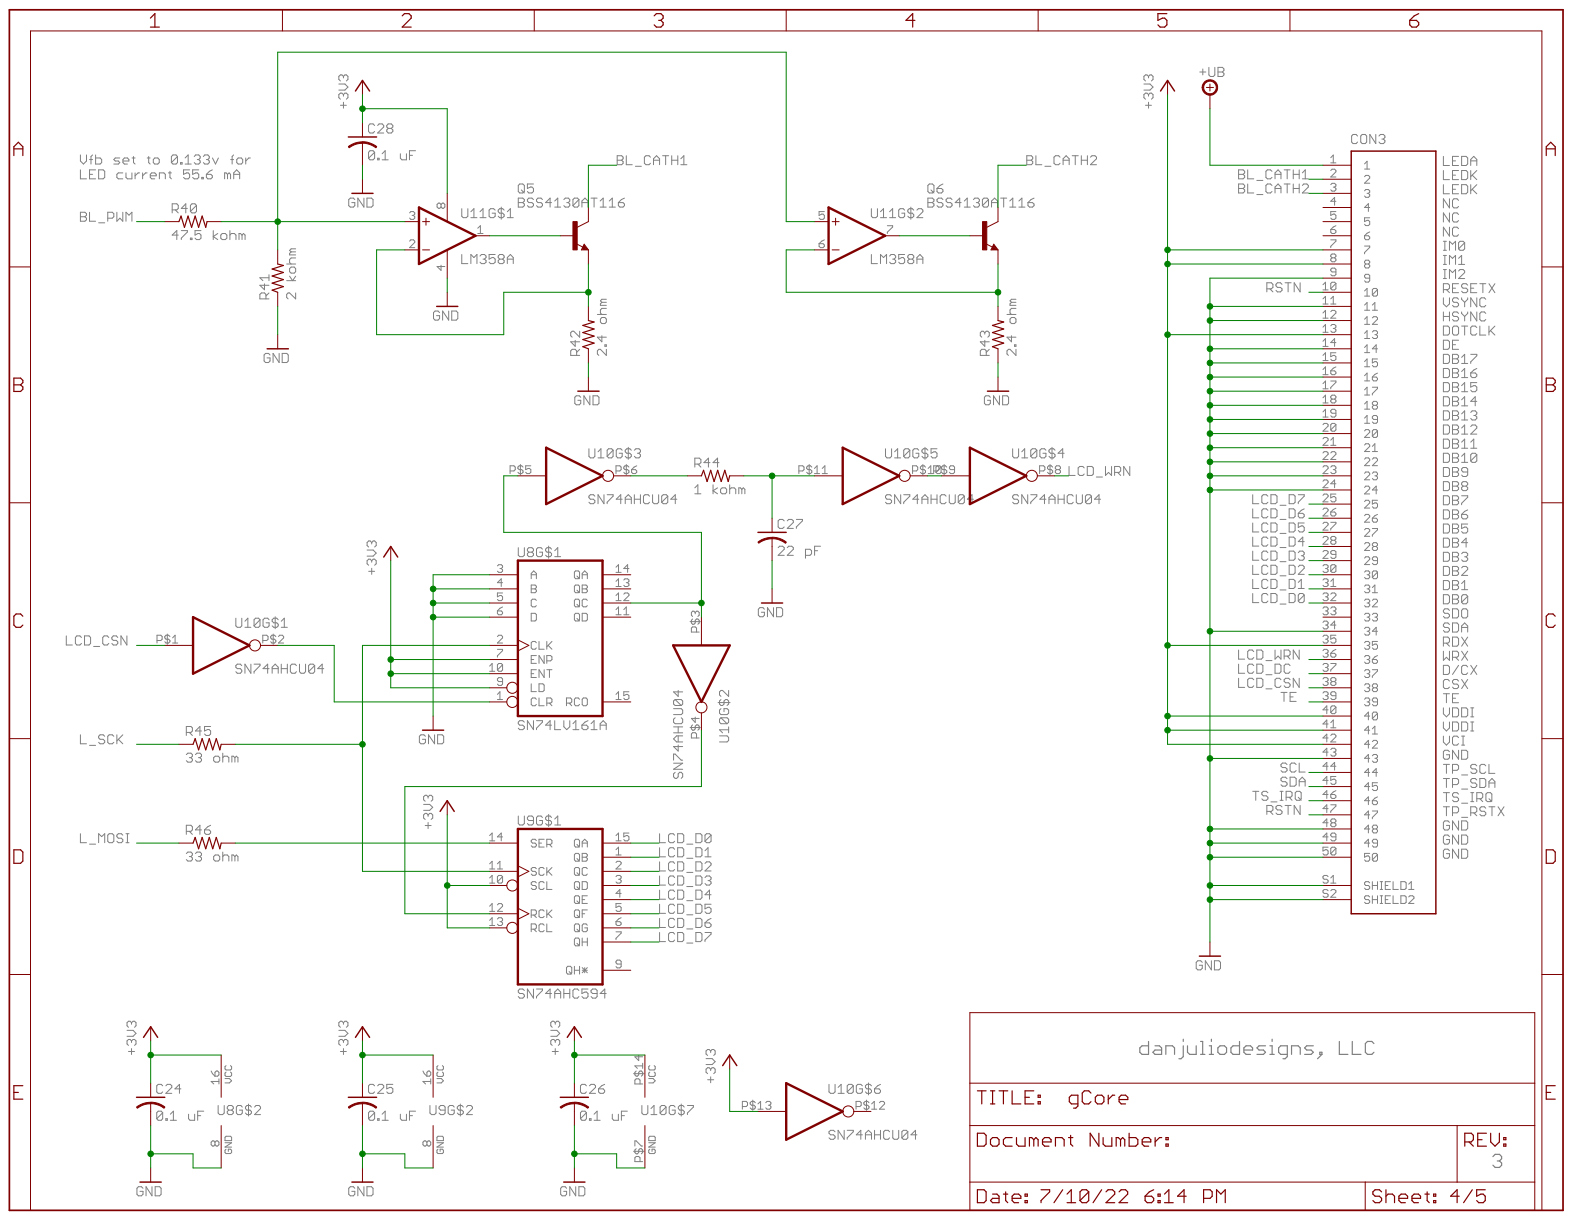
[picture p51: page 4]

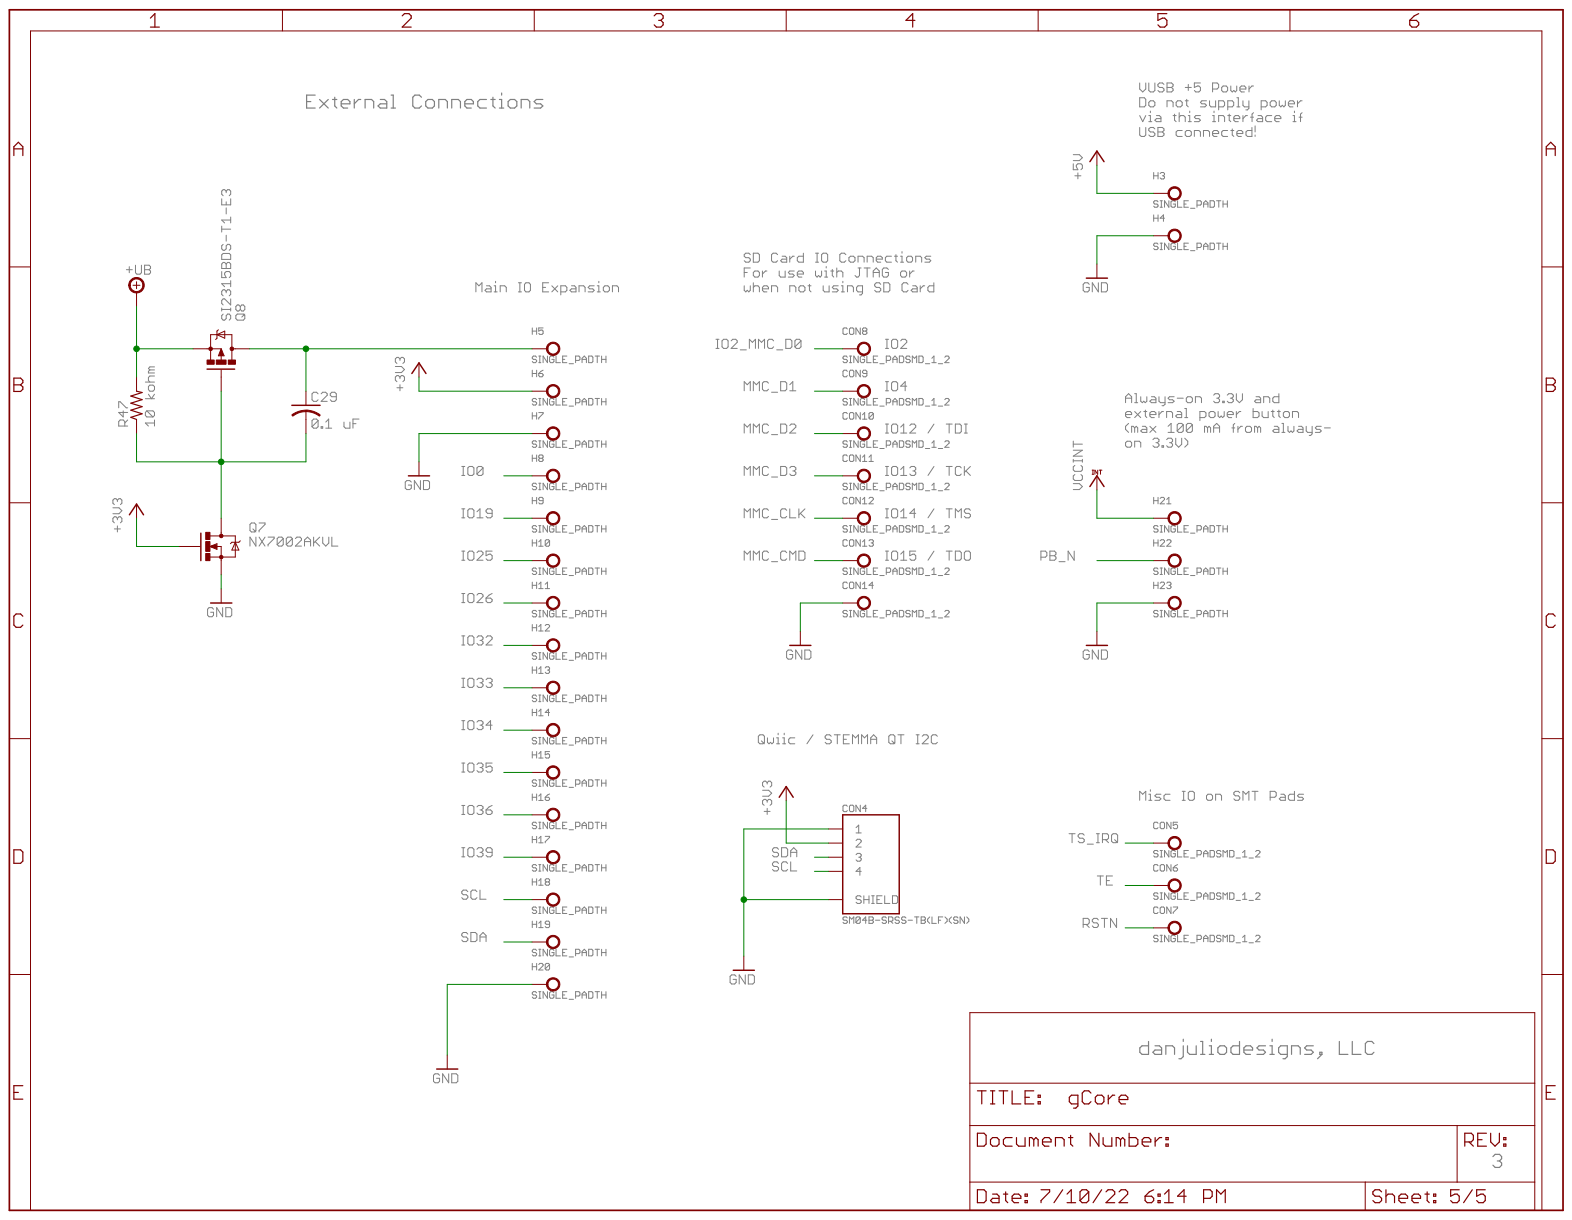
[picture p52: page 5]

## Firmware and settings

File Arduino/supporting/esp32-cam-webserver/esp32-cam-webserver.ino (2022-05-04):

#include <esp_camera.h>
#include <esp_int_wdt.h>
#include <esp_task_wdt.h>
#include <WiFi.h>
#include <DNSServer.h>
#include <ArduinoOTA.h>
#include "src/parsebytes.h"
#include "time.h"

/*
 * A pre-configured version of Owen Carter's modified ESP32 cam program.  Original source
 * 
 * https://github.com/easytarget/esp32-cam-webserver
 * 
 * This sketch is designed to stream to the gCore disp_mjpg_stream sketch and is configured
 * as follows in the myconfig.h file:
 *    1. Acts as an Access Point (AP) - SSID: ESP32-CAM    Password: esp32cam
 *    2. Default streaming resolution: CIF 400x296 pixels
 *       Reasonable values: QQVGA, QVGA, CIF, HVGA (not all ESP32 Arduino version support HVGA)
 *    3. AI Thinker ESP32-CAM board pinout
 *    
 * gCore connects to "http://192.168.4.1:81" to get the mjpg stream.
 * 
 * Configure Arduino for "AI Thinker ESP32 CAM" and be sure to set IO0 low and then
 * reset the board to put it in programming mode (as explained in the Readme).
 * 
 * Owen's original comment block below.  See the readme.md file for more information.
 */

/* This sketch is a extension/expansion/reork of the 'official' ESP32 Camera example
 *  sketch from Expressif:
 *  https://github.com/espressif/arduino-esp32/tree/master/libraries/ESP32/examples/Camera/CameraWebServer
 *
 *  It is modified to allow control of Illumination LED Lamps's (present on some modules),
 *  greater feedback via a status LED, and the HTML contents are present in plain text
 *  for easy modification.
 *
 *  A camera name can now be configured, and wifi details can be stored in an optional 
 *  header file to allow easier updated of the repo.
 *
 *  The web UI has had changes to add the lamp control, rotation, a standalone viewer,
 *  more feeedback, new controls and other tweaks and changes,
 * note: Make sure that you have either selected ESP32 AI Thinker,
 *       or another board which has PSRAM enabled to use high resolution camera modes
 */


/* 
 *  FOR NETWORK AND HARDWARE SETTINGS COPY OR RENAME 'myconfig.sample.h' TO 'myconfig.h' AND EDIT THAT.
 *
 * By default this sketch will assume an AI-THINKER ESP-CAM and create
 * an accesspoint called "ESP32-CAM-CONNECT" (password: "InsecurePassword")
 *
 */

// Primary config, or defaults.
#if __has_include("myconfig.h")
    struct station { const char ssid[65]; const char password[65]; const bool dhcp;};  // do no edit
    #include "myconfig.h"
#else
    #warning "Using Defaults: Copy myconfig.sample.h to myconfig.h and edit that to use your own settings"
    #define WIFI_AP_ENABLE
    #define CAMERA_MODEL_AI_THINKER
    struct station { const char ssid[65]; const char password[65]; const bool dhcp;} 
    stationList[] = {{"ESP32-CAM-CONNECT","InsecurePassword", true}};
#endif

// Upstream version string
#include "src/version.h"

// Pin Mappings
#include "camera_pins.h"

// Internal filesystem (SPIFFS)
// used for non-volatile camera settings
#include "storage.h"

// Sketch Info
int sketchSize;
int sketchSpace;
String sketchMD5;

// Start with accesspoint mode disabled, wifi setup will activate it if
// no known networks are found, and WIFI_AP_ENABLE has been defined
bool accesspoint = false;

// IP address, Netmask and Gateway, populated when connected
IPAddress ip;
IPAddress net;
IPAddress gw;

// Declare external function from app_httpd.cpp
extern void startCameraServer(int hPort, int sPort);
extern void serialDump();

// A Name for the Camera. (set in myconfig.h)
#if defined(CAM_NAME)
    char myName[] = CAM_NAME;
#else
    char myName[] = "ESP32 camera server";
#endif

// Ports for http and stream (override in myconfig.h)
#if defined(HTTP_PORT)
    int httpPort = HTTP_PORT;
#else
    int httpPort = 80;
#endif

#if defined(STREAM_PORT)
    int streamPort = STREAM_PORT;
#else
    int streamPort = 81;
#endif

#if !defined(WIFI_WATCHDOG)
    #define WIFI_WATCHDOG 5000
#endif

// Number of known networks in stationList[]
int stationCount = sizeof(stationList)/sizeof(stationList[0]);

// If we have AP mode enabled, ignore first entry in the stationList[]
#if defined(WIFI_AP_ENABLE)
    int firstStation = 1; 
#else
    int firstStation = 0;
#endif

// Select between full and simple index as the default.
#if defined(DEFAULT_INDEX_FULL)
    char default_index[] = "full";
#else
    char default_index[] = "simple";
#endif

// DNS server
const byte DNS_PORT = 53;
DNSServer dnsServer;
bool captivePortal = false;
char apName[64] = "Undefined";

// The app and stream URLs
char httpURL[64] = {"Undefined"};
char streamURL[64] = {"Undefined"};

// Counters for info screens and debug
int8_t streamCount = 0;          // Number of currently active streams
unsigned long streamsServed = 0; // Total completed streams
unsigned long imagesServed = 0;  // Total image requests

// This will be displayed to identify the firmware
char myVer[] PROGMEM = __DATE__ " @ " __TIME__;

// Camera module bus communications frequency.
// Originally: config.xclk_freq_hz = 20000000, but this lead to visual artifacts on many modules.
// See https://github.com/espressif/esp32-camera/issues/150#issuecomment-726473652 et al.
#if !defined (XCLK_FREQ_HZ)
    #define XCLK_FREQ_HZ 16500000;
#endif

// initial rotation
// can be set in myconfig.h
#if !defined(CAM_ROTATION)
    #define CAM_ROTATION 0
#endif
int myRotation = CAM_ROTATION;

// Illumination LAMP/LED
#if defined(LAMP_DISABLE)
    int lampVal = -1; // lamp is disabled in config
#elif defined(LAMP_PIN)
    #if defined(LAMP_DEFAULT)
        int lampVal = constrain(LAMP_DEFAULT,0,100); // initial lamp value, range 0-100
    #else
        int lampVal = 0; //default to off
    #endif
#else 
    int lampVal = -1; // no lamp pin assigned
#endif
bool autoLamp = false;         // Automatic lamp (auto on while camera running)

int lampChannel = 7;           // a free PWM channel (some channels used by camera)
const int pwmfreq = 50000;     // 50K pwm frequency
const int pwmresolution = 9;   // duty cycle bit range
const int pwmMax = pow(2,pwmresolution)-1;

#if defined(NO_FS)
    bool filesystem = false;
#else
    bool filesystem = true;
#endif

#if defined(NO_OTA)
    bool otaEnabled = false;
#else
    bool otaEnabled = true;
#endif

#if defined(NTPSERVER)
    bool haveTime = true;
    const char* ntpServer = NTPSERVER;
    const long  gmtOffset_sec = NTP_GMT_OFFSET;
    const int   daylightOffset_sec = NTP_DST_OFFSET;
#else
    bool haveTime = false;
    const char* ntpServer = "";
    const long  gmtOffset_sec = 0;
    const int   daylightOffset_sec = 0;
#endif

// Critical error string; if set during init (camera hardware failure) it
// will be returned for all http requests
String critERR = "";

// Debug flag for stream and capture data
bool debugData;

void debugOn() {
    debugData = true;
    Serial.println("Camera debug data is enabled (send 'd' for status dump, or any other char to disable debug)");
}

void debugOff() {
    debugData = false;
    Serial.println("Camera debug data is disabled (send 'd' for status dump, or any other char to enable debug)");
}

// Serial input (debugging controls)
void handleSerial() {
    if (Serial.available()) {
        char cmd = Serial.read();
        if (cmd == 'd' ) {
            serialDump();
        } else {
            if (debugData) debugOff();
            else debugOn();
        }
    }
    while (Serial.available()) Serial.read();  // chomp the buffer
}

// Notification LED 
void flashLED(int flashtime) {
#ifdef LED_PIN                    // If we have it; flash it.
    digitalWrite(LED_PIN, LED_ON);  // On at full power.
    delay(flashtime);               // delay
    digitalWrite(LED_PIN, LED_OFF); // turn Off
#else
    return;                         // No notifcation LED, do nothing, no delay
#endif
}

// Lamp Control
void setLamp(int newVal) {
    if (newVal != -1) {
        // Apply a logarithmic function to the scale.
        int brightness = round((pow(2,(1+(newVal*0.02)))-2)/6*pwmMax);
        ledcWrite(lampChannel, brightness);
        Serial.print("Lamp: ");
        Serial.print(newVal);
        Serial.print("%, pwm = ");
        Serial.println(brightness);
    }
}

void printLocalTime(bool extraData=false) {
    struct tm timeinfo;
    if(!getLocalTime(&timeinfo)){
        Serial.println("Failed to obtain time");
    } else {
        Serial.println(&timeinfo, "%H:%M:%S, %A, %B %d %Y");
    }
    if (extraData) {
        Serial.printf("NTP Server: %s, GMT Offset: %li(s), DST Offset: %i(s)\r\n", ntpServer, gmtOffset_sec, daylightOffset_sec);
    }
}

void WifiSetup() {
    // Feedback that we are now attempting to connect
    flashLED(300);
    delay(100);
    flashLED(300);
    Serial.println("Starting WiFi");

    // Disable power saving on WiFi to improve responsiveness 
    // (https://github.com/espressif/arduino-esp32/issues/1484)
    WiFi.setSleep(false);

    Serial.print("Known external SSIDs: ");
    if (stationCount > firstStation) {
        for (int i=firstStation; i < stationCount; i++) Serial.printf(" '%s'", stationList[i].ssid);
    } else {
        Serial.print("None");
    }
    Serial.println();
    byte mac[6] = {0,0,0,0,0,0};
    WiFi.macAddress(mac);
    Serial.printf("MAC address: %02X:%02X:%02X:%02X:%02X:%02X\r\n", mac[0], mac[1], mac[2], mac[3], mac[4], mac[5]);
    
    int bestStation = -1;
    long bestRSSI = -1024;
    char bestSSID[65] = "";
    uint8_t bestBSSID[6];
    if (stationCount > firstStation) {
        // We have a list to scan 
        Serial.printf("Scanning local Wifi Networks\r\n");
        int stationsFound = WiFi.scanNetworks();
        Serial.printf("%i networks found\r\n", stationsFound);
        if (stationsFound > 0) {
            for (int i = 0; i < stationsFound; ++i) {
                // Print SSID and RSSI for each network found
                String thisSSID = WiFi.SSID(i);
                int thisRSSI = WiFi.RSSI(i);
                String thisBSSID = WiFi.BSSIDstr(i);
                Serial.printf("%3i : [%s] %s (%i)", i + 1, thisBSSID.c_str(), thisSSID.c_str(), thisRSSI);
                // Scan our list of known external stations
                for (int sta = firstStation; sta < stationCount; sta++) {
                    if ((strcmp(stationList[sta].ssid, thisSSID.c_str()) == 0) || 
                    (strcmp(stationList[sta].ssid, thisBSSID.c_str()) == 0)) {
                        Serial.print("  -  Known!");
                        // Chose the strongest RSSI seen
                        if (thisRSSI > bestRSSI) {
                            bestStation = sta;
                            strncpy(bestSSID, thisSSID.c_str(), 64);
                            // Convert char bssid[] to a byte array
                            parseBytes(thisBSSID.c_str(), ':', bestBSSID, 6, 16);        
                            bestRSSI = thisRSSI;
                        }
                    }
                }
                Serial.println();
            }
        }
    } else {
        // No list to scan, therefore we are an accesspoint
        accesspoint = true; 
    }

    if (bestStation == -1) {
        if (!accesspoint) { 
            #if defined(WIFI_AP_ENABLE)
                Serial.println("No known networks found, entering AccessPoint fallback mode");
                accesspoint = true;
            #else
                Serial.println("No known networks found");
            #endif
        } else {
            Serial.println("AccessPoint mode selected in config");
        }
    } else {
        Serial.printf("Connecting to Wifi Network %d: [%02X:%02X:%02X:%02X:%02X:%02X] %s \r\n", 
                       bestStation, bestBSSID[0], bestBSSID[1], bestBSSID[2], bestBSSID[3], 
                       bestBSSID[4], bestBSSID[5], bestSSID);
        // Apply static settings if necesscary
        if (stationList[bestStation].dhcp == false) {
            #if defined(ST_IP)
                Serial.println("Applying static IP settings");
                #if !defined (ST_GATEWAY)  || !defined (ST_NETMASK) 
                    #error "You must supply both Gateway and NetMask when specifying a static IP address"
                #endif
                IPAddress staticIP(ST_IP);
                IPAddress gateway(ST_GATEWAY);
                IPAddress subnet(ST_NETMASK);
                #if !defined(ST_DNS1)
                    WiFi.config(staticIP, gateway, subnet);
                #else
                    IPAddress dns1(ST_DNS1);
                #if !defined(ST_DNS2)
                    WiFi.config(staticIP, gateway, subnet, dns1);
                #else
                    IPAddress dns2(ST_DNS2);
                    WiFi.config(staticIP, gateway, subnet, dns1, dns2);
                #endif
                #endif
            #else
                Serial.println("Static IP settings requested but not defined in config, falling back to dhcp");
            #endif
        }

        #if defined(HOSTNAME)
            WiFi.setHostname(HOSTNAME);
        #endif

        // Initiate network connection request (3rd argument, channel = 0 is 'auto')
        WiFi.begin(bestSSID, stationList[bestStation].password, 0, bestBSSID);

        // Wait to connect, or timeout
        unsigned long start = millis(); 
        while ((millis() - start <= WIFI_WATCHDOG) && (WiFi.status() != WL_CONNECTED)) {
            delay(500);
            Serial.print('.');
        }
        // If we have connected, inform user
        if (WiFi.status() == WL_CONNECTED) {
            Serial.println("Client connection succeeded");
            accesspoint = false;
            // Note IP details
            ip = WiFi.localIP();
            net = WiFi.subnetMask();
            gw = WiFi.gatewayIP();
            Serial.printf("IP address: %d.%d.%d.%d\r\n",ip[0],ip[1],ip[2],ip[3]);
            Serial.printf("Netmask   : %d.%d.%d.%d\r\n",net[0],net[1],net[2],net[3]);
            Serial.printf("Gateway   : %d.%d.%d.%d\r\n",gw[0],gw[1],gw[2],gw[3]);
            // Flash the LED to show we are connected
            for (int i = 0; i < 5; i++) {
                flashLED(50);
                delay(150);
            }
        } else {
            Serial.println("Client connection Failed");
            WiFi.disconnect();   // (resets the WiFi scan)
        }
    }

    if (accesspoint && (WiFi.status() != WL_CONNECTED)) {
        // The accesspoint has been enabled, and we have not connected to any existing networks
        #if defined(AP_CHAN)
            Serial.println("Setting up Fixed Channel AccessPoint");
            Serial.print("  SSID     : ");
            Serial.println(stationList[0].ssid);
            Serial.print("  Password : ");
            Serial.println(stationList[0].password);
            Serial.print("  Channel  : ");
            Serial.println(AP_CHAN);
            WiFi.softAP(stationList[0].ssid, stationList[0].password, AP_CHAN);
        # else
            Serial.println("Setting up AccessPoint");
            Serial.print("  SSID     : ");
            Serial.println(stationList[0].ssid);
            Serial.print("  Password : ");
            Serial.println(stationList[0].password);
            WiFi.softAP(stationList[0].ssid, stationList[0].password);
        #endif
        #if defined(AP_ADDRESS)
            // User has specified the AP details; apply them after a short delay
            // (https://github.com/espressif/arduino-esp32/issues/985#issuecomment-359157428)
            delay(100);
            IPAddress local_IP(AP_ADDRESS);
            IPAddress gateway(AP_ADDRESS);
            IPAddress subnet(255,255,255,0);
            WiFi.softAPConfig(local_IP, gateway, subnet);
        #endif
        // Note AP details
        ip = WiFi.softAPIP();
        net = WiFi.subnetMask();
        gw = WiFi.gatewayIP();
        strcpy(apName, stationList[0].ssid);
        Serial.printf("IP address: %d.%d.%d.%d\r\n",ip[0],ip[1],ip[2],ip[3]);
        // Flash the LED to show we are connected
        for (int i = 0; i < 5; i++) {
            flashLED(150);
            delay(50);
        }
        // Start the DNS captive portal if requested
        if (stationList[0].dhcp == true) {
            Serial.println("Starting Captive Portal");
            dnsServer.start(DNS_PORT, "*", ip);
            captivePortal = true;
        }
    }
}
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
void loop() {
    /* 
     *  Just loop forever, reconnecting Wifi As necesscary in client mode
     * The stream and URI handler processes initiated by the startCameraServer() call at the
     * end of setup() will handle the camera and UI processing from now on.
    */
    if (accesspoint) {
        // Accespoint is permanently up, so just loop, servicing the captive portal as needed
        // Rather than loop forever, follow the watchdog, in case we later add auto re-scan.
        unsigned long start = millis();
        while (millis() - start < WIFI_WATCHDOG ) {
            delay(100);
            if (otaEnabled) ArduinoOTA.handle();
            handleSerial();
            if (captivePortal) dnsServer.processNextRequest();
        }
    } else {
        // client mode can fail; so reconnect as appropriate 
        static bool warned = false;
        if (WiFi.status() == WL_CONNECTED) {
            // We are connected, wait a bit and re-check
            if (warned) {
                // Tell the user if we have just reconnected 
                Serial.println("WiFi reconnected");
                warned = false;
            }
            // loop here for WIFI_WATCHDOG, turning debugData true/false depending on serial input..
            unsigned long start = millis();
            while (millis() - start < WIFI_WATCHDOG ) {
                delay(100);
                if (otaEnabled) ArduinoOTA.handle();
                handleSerial();
            }
        } else {
            // disconnected; attempt to reconnect
            if (!warned) {
                // Tell the user if we just disconnected
                WiFi.disconnect();  // ensures disconnect is complete, wifi scan cleared
                Serial.println("WiFi disconnected, retrying");
                warned = true;
            }
            WifiSetup();
        }
    }
}

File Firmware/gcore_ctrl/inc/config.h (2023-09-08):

/*
 * config.h
 *
 *  Global default system configuration parameters
 *
 * Copyright (c) 2021-2023 danjuliodesigns, LLC.  All rights reserved.
 *
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
 */

#ifndef INC_CONFIG_H_
#define INC_CONFIG_H_

#include <SI_EFM8SB2_Register_Enums.h>

// =========================================================
// Firmware version
//  FW_ID should be limited to 8-bits
//  FW_VER fields should be limited to 4-bits
#define FW_ID               1
#define FW_VER_MAJOR        1
#define FW_VER_MINOR        2



// =========================================================
// Hardware configuration
//

//
// External battery resistor divider scale factor (x100)
//
#define BATT_MULT_FACTOR    502



// =========================================================
// Default hard-coded operating parameters
//

//
// Battery Voltage thresholds
//
#define BATT_VREF_MV        1250
#define BATT_CRIT_MV        3300
#define BATT_TURN_ON_MIN_MV 3500


//
// Evaluation intervals
//
#define EVAL_BATT_MSEC  100
#define EVAL_GPIO_MSEC  10
#define EVAL_LED_MSEC   10


//
// Critical battery shutdown interval
//
#define BATT_CRIT_TO_MSEC 10000


//
// Default Short button press interval
//
//   BTN_PRESS_SHORT_MSEC / EVAL_GPIO_MSEC must fit in a uint8_t
//
#define BTN_PRESS_SHORT_MSEC 100


//
// Long button press shutdown interval
//   BTN_PRESS_LONG_MSEC / EVAL_GPIO_MSEC must fit in a uint16_t
//
#define BTN_PRESS_LONG_MSEC 5000


//
// Default backlight PWM brightness
//
#define BL_PWM_DEFAULT      128


#endif /* INC_CONFIG_H_ */

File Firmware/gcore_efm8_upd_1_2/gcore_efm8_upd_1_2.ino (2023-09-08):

/*
 * gCore EFM8 firmware updater sketch.
 * 
 * This sketch has been designed to run on a 3.3V Arduino-compatible 32-bit development board.  It has been tested
 * on the following boards.
 * 
 *   1. PJRC Teensy 3.2 using Teensyduino 1.56
 *      - Important: Set Optimization Level to "Faster" (CPU default 96 MHz)
 *   2. PJRC Teensy 4 using Teensyduino 1.56
 *      - Important: Set Optimization Level to "Faster" (CPU default 600 MHz)
 *   3. Sparkfun ESP32 Thing Plus using Espressif ESP32 for Arduino version 2.0.9
 *      - Important: Flash frequency: 80 MHz
 *   4. Espressif ESP32-S3-DevKitC-1 using Espressif ESP32 for Arduino version 2.0.9
 *      - Important: Be sure Flash Mode matches your ESP32-S3 module (e.g. I used OPI 80 MHz for my MON32R8V module)
 *   5. Waveshare RP2040 Zero using Earle Philhower’s Raspberry Pi Pico/RP2040 version 3.4.1
 *      - Important: Set Optimization level to "Optimize Even More (-O3)" (CPU default 133 Mhz)
 *   
 * The C2 interface has some timing restrictions and various Arduino implementations have wildly different GPIO
 * performance so unfortunately I cannot guarantee operation on any other board (although different ESP32 and
 * RP2040 boards will probably work).
 * 
 * Updates the firmware on the gCore EFM8 PMIC/RTC co-processor to version 1.2 (fixing a bug in the RTC).
 * 
 * Use this sketch only if you are comfortable making the following connections to gCore.  There is the possibility
 * you'll damage the board (e.g. short something or rip a pad off the PCB).
 * 
 * Needs to be connected to the following 3 EFM8 programming pads on gCore (see my github repository
 * https://github.com/danjulio/gCore/tree/main/Firmware for more detailed instructions and pictures).
 * 
 *   Arduino GND    : gCore "G" pad
 *   Arduino c2dPin : gCore "D" pad
 *   Arduino c2ckPin: gCore "C" pad
 *   
 * c2dPin and c2ckPin are defined below.  You may either very carefully solder the three wires to gCore's pads or
 * [better] use male dupont pins held together and pressed against the pads (you may want to clean any oxide off the
 * pads using isopropyl alcohol first).
 * 
 * gCore is powered via a connected battery or USB-C.  It does not need to be turned on (the EFM8 will be powered
 * when gCore is powered).
 * 
 * Instructions
 *   1. Load this sketch into your 3.3V 32-bit Arduino board.
 *   2. The Arduino board should remain connected to the computer and the Serial Monitor opened and configured
 *      for 115200 baud.
 *   3. Type the character H into the Serial Monitor and hit send.  You should see a banner message indicating
 *      the sketch is running.
 *   4. With the Arduino connected to gCore and gCore powered, type P into the Serial Monitor and hit send.  You
 *      should see the programming sequence.  Programming will take a few seconds.  If you are pressing a set of
 *      dupont connectors into the gCore pads, make sure they remain in good contact.  You should see a message
 *      indicating success.  If you see a message indicating an error then probably you don't have a good or
 *      correct connection or gCore isn't powered.
 *   5. You can power everything down and disconnect the Arduino wires from gCore.
 *   6. With a battery attached to gCore press the power button.  It should turn on indicating the EFM8 is running.
 *      Load the gCore Arduino "gcore_reg_explorer" sketch to see the EFM8 version.  It should show "1.2".
 * 
 * Copyright 2023 danjuliodesigns, LLC.  All rights reserved.
 * 
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
 */

 
// ==================================================
// Pin Definition
//   Change these if necessary for your board.  Selected pins should be digital IO with nothing else attached
//   (e.g. Don't use the typical pin 13 with LED).
//

const int c2dPin  = 12;  // Connect to "D"
const int c2ckPin = 14;  // Connect to "C"



// ==================================================
// Arduino Entry Points
//
void setup() {
  Serial.begin(115200);

  // Time to open the Serial Monitor
  delay(2000);

  print_hello();
}


void loop() {
  char c;

  if (Serial.available()) {
    c = Serial.read();

    if ((c == 'H') || (c == 'h')) {
      print_hello();
    } else if ((c == 'P') || (c == 'p')) {
      program_device();
    }
  }

  delay(100);
}


// ==================================================
// Subroutines
//
void print_hello() {
  Serial.println("gCore EFM8 version 1.2 firmware updater sketch.");
}

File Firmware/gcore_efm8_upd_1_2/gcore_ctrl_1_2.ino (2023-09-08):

/*
 * This file contains the firmware to load into the EFM8 micro-controller
 */

const int byte_array_count = 10384;

const uint8_t hex_byte_array[] = {
	0x02, 0x0B, 0xFC, 0xA2, 0x87, 0x40, 0x02, 0xD3, 0x22, 0xC3, 0x22, 0x02, 0x12, 0x72, 0xA2, 0x15, 
	0x92, 0x17, 0x30, 0x15, 0x09, 0x7F, 0x0E, 0x12, 0x18, 0x30, 0x8F, 0x43, 0x80, 0x03, 0xE4, 0xF5, 
	0x43, 0xAD, 0x43, 0xE4, 0xFF, 0x02, 0x10, 0x5D, 0x02, 0x18, 0x75, 0x02, 0x0F, 0x82, 0x75, 0xF1, 
	0xE0, 0x75, 0xD4, 0xFF, 0x75, 0xC7, 0x80, 0x75, 0xD7, 0x7F, 0x22, 0x02, 0x05, 0x30, 0xE4, 0xF5, 
	0xC9, 0x22, 0x22, 0x02, 0x08, 0x65, 0x75, 0xF4, 0x24, 0x75, 0xF5, 0xFF, 0x53, 0xC1, 0xBF, 0x43, 
	0xC1, 0x90, 0x22, 0x02, 0x09, 0xFE, 0xE5, 0xC8, 0x54, 0x04, 0x53, 0xC8, 0xFB, 0x75, 0xCD, 0xFE, 
	0x75, 0xCC, 0x68, 0x75, 0xCB, 0xFE, 0x75, 0xCA, 0x68, 0x43, 0xC8, 0x04, 0x42, 0xC8, 0x22, 0xE4, 
	0xF5, 0xD1, 0x22, 0x02, 0x18, 0x37, 0xE8, 0x8F, 0xF0, 0xA4, 0xCC, 0x8B, 0xF0, 0xA4, 0x2C, 0xFC, 
	0xE9, 0x8E, 0xF0, 0xA4, 0x2C, 0xFC, 0x8A, 0xF0, 0xED, 0xA4, 0x2C, 0xFC, 0xEA, 0x8E, 0xF0, 0xA4, 
	0xCD, 0xA8, 0xF0, 0x8B, 0xF0, 0xA4, 0x2D, 0xCC, 0x38, 0x25, 0xF0, 0xFD, 0xE9, 0x8F, 0xF0, 0xA4, 
	0x2C, 0xCD, 0x35, 0xF0, 0xFC, 0xEB, 0x8E, 0xF0, 0xA4, 0xFE, 0xA9, 0xF0, 0xEB, 0x8F, 0xF0, 0xA4, 
	0xCF, 0xC5, 0xF0, 0x2E, 0xCD, 0x39, 0xFE, 0xE4, 0x3C, 0xFC, 0xEA, 0xA4, 0x2D, 0xCE, 0x35, 0xF0, 
	0xFD, 0xE4, 0x3C, 0xFC, 0x22, 0xEB, 0x9F, 0xF5, 0xF0, 0xEA, 0x9E, 0x42, 0xF0, 0xE9, 0x9D, 0x42, 
	0xF0, 0xEC, 0x64, 0x80, 0xC8, 0x64, 0x80, 0x98, 0x45, 0xF0, 0x22, 0xEB, 0x9F, 0xF5, 0xF0, 0xEA, 
	0x9E, 0x42, 0xF0, 0xE9, 0x9D, 0x42, 0xF0, 0xE8, 0x9C, 0x45, 0xF0, 0x22, 0xE8, 0x60, 0x0F, 0xEC, 
	0xC3, 0x13, 0xFC, 0xED, 0x13, 0xFD, 0xEE, 0x13, 0xFE, 0xEF, 0x13, 0xFF, 0xD8, 0xF1, 0x22, 0xE8, 
	0x60, 0x10, 0xEC, 0xA2, 0xE7, 0x13, 0xFC, 0xED, 0x13, 0xFD, 0xEE, 0x13, 0xFE, 0xEF, 0x13, 0xFF, 
	0xD8, 0xF0, 0x22, 0xE8, 0x60, 0x0F, 0xEF, 0xC3, 0x33, 0xFF, 0xEE, 0x33, 0xFE, 0xED, 0x33, 0xFD, 
	0xEC, 0x33, 0xFC, 0xD8, 0xF1, 0x22, 0xE6, 0xFC, 0x08, 0xE6, 0xFD, 0x08, 0xE6, 0xFE, 0x08, 0xE6, 
	0xFF, 0x22, 0x74, 0x01, 0xFF, 0x33, 0x95, 0xE0, 0xFE, 0xFD, 0xFC, 0x08, 0x08, 0x08, 0xE6, 0x2F, 
	0xFF, 0xF6, 0x18, 0xE6, 0x3E, 0xFE, 0xF6, 0x18, 0xE6, 0x3D, 0xFD, 0xF6, 0x18, 0xE6, 0x3C, 0xFC, 
	0xF6, 0x22, 0xEC, 0xF6, 0x08, 0xED, 0xF6, 0x08, 0xEE, 0xF6, 0x08, 0xEF, 0xF6, 0x22, 0x75, 0xF0, 
	0x08, 0x75, 0x82, 0x00, 0xEF, 0x2F, 0xFF, 0xEE, 0x33, 0xFE, 0xCD, 0x33, 0xCD, 0xCC, 0x33, 0xCC, 
	0xC5, 0x82, 0x33, 0xC5, 0x82, 0x9B, 0xED, 0x9A, 0xEC, 0x99, 0xE5, 0x82, 0x98, 0x40, 0x0C, 0xF5, 
	0x82, 0xEE, 0x9B, 0xFE, 0xED, 0x9A, 0xFD, 0xEC, 0x99, 0xFC, 0x0F, 0xD5, 0xF0, 0xD6, 0xE4, 0xCE, 
	0xFB, 0xE4, 0xCD, 0xFA, 0xE4, 0xCC, 0xF9, 0xA8, 0x82, 0x22, 0xB8, 0x00, 0xC1, 0xB9, 0x00, 0x59, 
	0xBA, 0x00, 0x2D, 0xEC, 0x8B, 0xF0, 0x84, 0xCF, 0xCE, 0xCD, 0xFC, 0xE5, 0xF0, 0xCB, 0xF9, 0x78, 
	0x18, 0xEF, 0x2F, 0xFF, 0xEE, 0x33, 0xFE, 0xED, 0x33, 0xFD, 0xEC, 0x33, 0xFC, 0xEB, 0x33, 0xFB, 
	0x10, 0xD7, 0x03, 0x99, 0x40, 0x04, 0xEB, 0x99, 0xFB, 0x0F, 0xD8, 0xE5, 0xE4, 0xF9, 0xFA, 0x22, 
	0x78, 0x18, 0xEF, 0x2F, 0xFF, 0xEE, 0x33, 0xFE, 0xED, 0x33, 0xFD, 0xEC, 0x33, 0xFC, 0xC9, 0x33, 
	0xC9, 0x10, 0xD7, 0x05, 0x9B, 0xE9, 0x9A, 0x40, 0x07, 0xEC, 0x9B, 0xFC, 0xE9, 0x9A, 0xF9, 0x0F, 
	0xD8, 0xE0, 0xE4, 0xC9, 0xFA, 0xE4, 0xCC, 0xFB, 0x22, 0x75, 0xF0, 0x10, 0xEF, 0x2F, 0xFF, 0xEE, 
	0x33, 0xFE, 0xED, 0x33, 0xFD, 0xCC, 0x33, 0xCC, 0xC8, 0x33, 0xC8, 0x10, 0xD7, 0x07, 0x9B, 0xEC, 
	0x9A, 0xE8, 0x99, 0x40, 0x0A, 0xED, 0x9B, 0xFD, 0xEC, 0x9A, 0xFC, 0xE8, 0x99, 0xF8, 0x0F, 0xD5, 
	0xF0, 0xDA, 0xE4, 0xCD, 0xFB, 0xE4, 0xCC, 0xFA, 0xE4, 0xC8, 0xF9, 0x22, 0x8F, 0x0A, 0x12, 0x15, 
	0x0B, 0xC3, 0xEF, 0x94, 0xAC, 0xEE, 0x64, 0x80, 0x94, 0x8D, 0x40, 0x03, 0xD3, 0x80, 0x01, 0xC3, 
	0x92, 0x14, 0x7F, 0x0F, 0x12, 0x18, 0x30, 0x8F, 0x0B, 0xE5, 0x54, 0x14, 0x60, 0x73, 0x14, 0x70, 
	0x03, 0x02, 0x03, 0x25, 0x14, 0x70, 0x03, 0x02, 0x03, 0x48, 0x14, 0x70, 0x03, 0x02, 0x03, 0xB5, 
	0x24, 0x04, 0x60, 0x03, 0x02, 0x03, 0xCC, 0xE5, 0x0A, 0x54, 0x02, 0x60, 0x0B, 0xE5, 0x0B, 0x54, 
	0x01, 0x60, 0x05, 0x30, 0x14, 0x02, 0x80, 0x57, 0xE5, 0x0A, 0x54, 0x04, 0x60, 0x2F, 0xE5, 0x0B, 
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
};


uint8_t* get_hex_array_addr(int* num_bytesP) {
  *num_bytesP = byte_array_count;
  return (uint8_t*) hex_byte_array;
}

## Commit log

2022-03-09 Add initial Arduino code
2022-03-29 Fixed typo about charge configuration resistor
2022-05-04 disp_mjpg_streamer and shake_2_wake Arduino sketches
2022-05-14 Added handheld_2_fdm enclosure design
    [standalone_enclosure_2.scad, standalone_enclosure_2_base.stl, standalone_enclosure_2_bezel.stl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]
2022-10-27 Fixed bug in parsing FW version
    [gcore_reg_explorer.ino]
2022-10-28 Rev 3 board schematic
2022-11-06 Added Hardware
    [gCore_centroid.csv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]
2022-12-02 Update documentation
    Rev 3 board, re-organize directory, document updates
2023-06-02 Fixed bugs in Arduino demos found when moving to 2.X
    [com_task.ino, dual_touch.ino]

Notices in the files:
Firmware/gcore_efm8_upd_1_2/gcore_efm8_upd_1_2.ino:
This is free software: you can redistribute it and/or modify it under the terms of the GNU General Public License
